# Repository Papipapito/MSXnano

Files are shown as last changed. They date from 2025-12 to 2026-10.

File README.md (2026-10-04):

# MSXnano — MSX2+ FPGA Core for Tang Nano 20K

**MSXnano** is an open-source MSX2+ FPGA implementation for the Tang Nano 20K (Gowin GW2AR-18). It runs a complete MSX2+ system — Z80 CPU, V9958 VDP with HDMI output, SCC/OPLL sound, SD card with Nextor, USB keyboard, joystick and mouse, and optional WiFi — entirely on the FPGA, with no original MSX hardware required.

> 📖 Project page, install guides and community: **[msx.barcelona](https://msx.barcelona)**

> **Project status: v2.1** ([`v2.1`](https://github.com/Papipapito/MSXnano/releases/tag/v2.1), 30/09/2026 — a **pre-release** until it is
> validated on the board; the last validated one is [`v2.0-final`](https://github.com/Papipapito/MSXnano/releases/tag/v2.0-final)).
> v2.1 brings a sorted SD browser and a faster CPU read path; the core still fills ~89 % of
> the GW2AR-18, so no larger features fit. Everything that
> works is documented; everything that was left out is listed, with the reasons, in
> [docs/tecnica/09-pendientes.md](docs/tecnica/09-pendientes.md). Larger features live on
> in [MSXimus](https://github.com/Papipapito/MSXimus) (Tang Console 60K).

## Features

* Z80 with authentic MSX timing (per-M1 wait state, ~100% of real MSX speed)
* V9958 VDP with HDMI output
* MSX2+ BIOS · 4 MB mapper · 2 MB Megaram SCC · RTC
* PSG · OPLL · SCC+ (×2) · stereo
* SD card with **Nextor 2.1.4**, boot menu and file browser
* **USB keyboard, joystick and MSX mouse** through an RP2040 companion
* **Turbo** — Panasonic WSX protocol at an exact 5.369318 MHz
* Optional **WiFi** (MSX UNAPI) via ESP-01S, or an **ESP32-C6** that adds a status screen

---

## What's new in v2.1

- **The SD browser is sorted**: folders first, then ROMs and disks together, alphabetical and
  case-insensitive. Hidden and system files stay out of the list (Windows' `System Volume
  Information`, the `.Trashes` and `._name.rom` a Mac leaves behind). A folder holds up to 112
  entries; if there are more, the counter ends in `+` (`112/112+`). On the gamepad, left and
  right (page jumps) now count once per press.
- **A faster CPU read path**: the read multiplexer is a tree instead of a 31-deep chain, with
  exactly the same priority (proven with a formal equivalence check). The CPU clock now closes
  on 6 placements out of 6, against 3 out of 6 before; this build runs at 62.5 MHz for the
  54 MHz it needs.
- **BIOS packs in English** as well as Spanish: four packs, English or Spanish menu, Nextor
  2.1.4 or 3.
- Settings shows **2.1** as the FPGA version. The RP2040 and ESP32-C6 firmwares do not change.

## What's new in v2.0

### 🎛️ One BIOS, and the menu is now an option

There used to be two BIOS builds — one that booted straight to MSX, one with the SD
browser — so you had to pick which one to flash. There is now **a single BIOS** and the
menu is a **setting**: press **S** at boot, tick *Menu al arrancar*, `Save & Restart`.
Untick it and you are back to booting straight into MSX. The choice is stored in flash.

### 📥 Downloads from the boot menu (File-Hunter)

With WiFi connected, press **F** in the browser to search and download ROMs and disk
images straight to the SD card, without a PC.

### 🕹️ RP2040 companion — better keyboards, and an MSX mouse

The onboard **BL616 is no longer used**. USB keyboard, joystick and mouse are now served
by an **RP2040 (Pico Zero)** over a single wire.

This removes the biggest compatibility headache of the previous versions: Tang Nano 20K
boards made since 2024 (marked **`3921`**) ship a BL616 in a secure-boot state that often
could not run the companion firmware, leaving you **without a keyboard** and needing an
external M0S Dock. **With the RP2040 that problem is gone** — every board behaves the same.

And it adds what the BL616 never did: a **real MSX mouse**, from any USB mouse.

### 🖥️ Optional companion screen

Alongside WiFi you can fit an **ESP32-C6 with a 240×240 LCD** that shows connection
status, the clock and whether Turbo is on — plus the classic MSX boot logo. The
**ESP-01S** is still supported if you only want WiFi.

---

## 🔌 Wiring

All three companions are **optional and independent**. The core boots and runs with none
of them (you just get no keyboard, so fit the RP2040 at least).

### FPGA ↔ RP2040 (keyboard, joystick, mouse)

| Pico Zero | Tang Nano 20K | Notes |
|---|---|---|
| **GP15** (TX) | **pin 31** | PIO-UART, 115200 8N1 |
| GND | GND | common ground |
| VBUS | 5V | powers the Pico |

Plug the USB keyboard, gamepad or mouse into the Pico's own USB port (a hub works).

Firmware: **`rp2040_keyboard_zero.uf2`** for the Waveshare **RP2040-Zero** (the default), or
**`rp2040_keyboard_pico.uf2`** for a plain Raspberry Pi Pico — both in the release. Source
and the same binaries are in [`fpga/rp2040/`](fpga/rp2040/) (there the Zero one is named
`rp2040_keyboard.uf2`).

### FPGA ↔ ESP-01S (WiFi only)

| ESP-01S | Tang Nano 20K |
|---|---|
| RX | **pin 27** |
| TX | **pin 28** |
| VCC | 3.3V |
| GND | GND |

### FPGA ↔ ESP32-C6 (WiFi + status screen)

The C6 replaces the ESP-01S on the same UART and adds one wire for the Turbo indicator.

| ESP32-C6 | Tang Nano 20K | Signal |
|---|---|---|
| **GPIO17** (RX) | **pin 27** | FPGA → C6 |
| **GPIO16** (TX) | **pin 28** | C6 → FPGA |
| **GPIO3** | **pin 29** | Turbo status |
| GND | GND | common ground |

Board: Waveshare **ESP32-C6-LCD-1.3**. Firmware: **[ESP32-for-FPGA](https://github.com/Papipapito/ESP32-for-FPGA)**.

---

## 💾 What to flash

Everything is attached to the **[v2.1 release](https://github.com/Papipapito/MSXnano/releases/tag/v2.1)** (the previous one, [`v2.0-final`](https://github.com/Papipapito/MSXnano/releases/tag/v2.0-final), stays available).

| Step | File | Address | Tool |
|---|---|---|---|
| 1 | `msxnano_v2.1.fs` | `0x000000` | [Gowin Programmer](https://www.gowinsemi.com/en/support/download_eda/) — External Flash mode |
| 2 | **One** pack: `pack_bios_msxnano.bin` (Spanish menu, Nextor 2.1.4, recommended), `pack_bios_msxnano_en.bin` (English menu), `pack_bios_msxnano_nextor3.bin` / `pack_bios_msxnano_en_nextor3.bin` (Nextor 3 beta) | `0x200000` | Gowin Programmer — *exFlash C Bin Erase, Program thru GAO-Bridge* |
| 3 | `rp2040_keyboard_zero.uf2` (RP2040-Zero) **or** `rp2040_keyboard_pico.uf2` (Pico) | — | Drag onto the Pico's `RPI-RP2` drive (hold BOOTSEL while plugging in) |
| 4 | `firmware_esp32c6_v2.0_merged.bin` | `0x0` | `esptool` — only if you fit the ESP32-C6 (the ESP-01S uses the ducasp UNAPI firmware) |

> The BIOS packs bundle the MSX2+ BIOS, sub-ROM, kanji, MSX-MUSIC, Nextor, the WiFi ROM,
> the boot menu and the config block. The system ROMs in them are copyrighted by their
> owners. Flashing a pack resets the saved Settings.

### The SD card

The best way to prepare the microSD is **[MSX SD Maker](https://github.com/Papipapito/SD_Maker)**, which has its own repository (a copy with
its guide is in [`MSXsdmaker/`](MSXsdmaker/README.md)): a Windows program that splits the card into 2 or 4 GB FAT16 partitions the way Nextor's FDISK does, copies Nextor 2.1.4 or 3
(to match your pack), SofaRun, Multi Mente and a set of utilities, and writes the `AUTOEXEC.BAT` that mounts the other
partitions as C:, D:… Nextor cannot read FAT32, so MSX-DOS needs FAT16.

---

## Keyboard

| MSX key | USB key |
|---|---|
| **GRAPH** | Left Alt, or either **Windows** key |
| **CODE / KANA** | Right Alt |
| **STOP** | F12, or Scroll Lock |
| **SELECT** | End |
| **CAPS** | Caps Lock |
| **F6–F10** | F6–F10 — sent as SHIFT+F1..F5, exactly as on a real MSX |
| F1–F5, arrows, HOME/INS/DEL, ESC/TAB/BS/RETURN | 1:1 |

**F11** toggles Turbo on the fly. It can also be set at power-on from **Settings**
(*Boot Turbo*) or by software through the Panasonic ports `$40/$41` (software wins if
both change it in the same cycle).

---

## Slot map

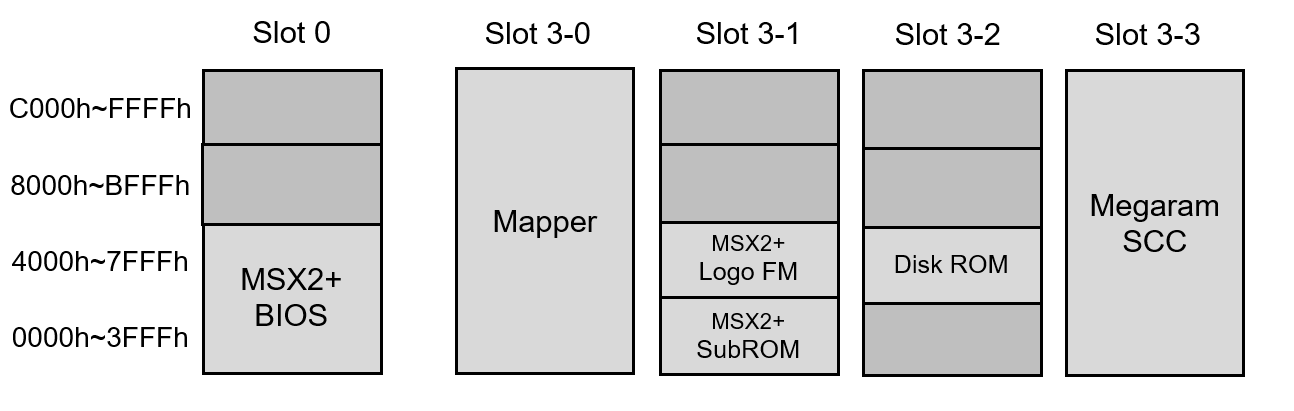
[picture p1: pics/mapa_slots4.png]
MSXnano MSX2+ slot map / memory layout for the Tang Nano 20K FPGA core


The layout is fixed by design: **Megaram in slot 2**, SD in **3-2**. SofaRun detects the
Megaram automatically; other software may need it set by hand.

---

## Hardware: case & bill of materials

* Parts list: [`docs/BOM.md`](docs/BOM.md) (spreadsheet: [`docs/MSXnano_BOM.xlsx`](docs/MSXnano_BOM.xlsx)).
* 3D-printable case: [`case/`](case/README.md) — a Bambu Studio project with every part,
  plus the STLs. Two top-left lids: one with a window for the ESP32-C6 screen, one plain.

> The 3D case is based on [this Thingiverse design](https://www.thingiverse.com/thing:4066021), which served as the inspiration and starting point for our improved version.

---

## 📚 Documentation

Full documentation (in Spanish) is in [`docs/INDICE.md`](docs/INDICE.md):

| | |
|---|---|
| [`docs/manual/`](docs/manual/01-que-es.md) | **User manual** — install, SD card, boot menu, ROMs and mappers, keyboard/mouse/joystick, WiFi and File-Hunter, audio/video/turbo, case, troubleshooting |
| [`docs/tecnica/`](docs/tecnica/01-arquitectura.md) | **Technical reference** — architecture, I/O ports, memory maps, the BIOS pack, the RP2040 protocol, synthesis and timing (why nothing more fits), simulation, changelog, open items |
| [`docs/historico/`](docs/historico/README.md) | Index of bug-hunt reports, design documents and retired code kept in the tree |

## Credits

This project is based on the work of **jabadiagm** ([MSXgoauldSD_tn20k](https://github.com/jabadiagm/MSXgoauldSD_tn20k)), licensed under **GPLv3**.

It is a standalone FPGA implementation that does not rely on the original physical MSX hardware, so all hardware-related files (PCB, MSX interface, schematics) have been removed.

**Claude (Anthropic)** collaborated on this project.

---

## Community & links

- 🌐 Project page & guides: [msx.barcelona](https://msx.barcelona)
- 🐙 Other MSX FPGA projects: [github.com/Papipapito](https://github.com/Papipapito)
- 🗣️ Barcelona MSX community: [AAMSX](https://www.aamsx.com)

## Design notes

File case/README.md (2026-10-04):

# Case (3D-printable enclosure)

3D-printable enclosure for the MSXnano (Tang Nano 20K based MSX2+).

## Quick print
Open **`msxnano_case_bambulab.3mf`** in **Bambu Studio** — it contains every part laid
out and ready to print all at once.

**Recommended material: white PETG.**

## Parts (STL)

| File | Part | Qty |
|---|---|-----|
| `Upper_Left_esp32.stl` | Top — left, **with a window for the ESP32-C6 LCD** | 1 (pick one) |
| `upper_left_sin_pantalla.stl` | Top — left, **plain** (ESP-01S or no WiFi module) | 1 (pick one) |
| `upper_right.stl` | Top — right | 1 |
| `lower_left.stl` | Bottom — left, **cut for the [MSXnano carrier v2](https://github.com/Papipapito/MSXnano-Boards/tree/main/carrier)**: USB-C, HDMI and 2 × USB-A out of the back wall, 4 standoffs for the board | 1 |
| `prototipo/lower_left_prototipo.stl` | Bottom — left, previous prototype (Tang + RP2040 wired by hand) | — |
| `lower_right.stl` | Bottom — right | 1 |
| `lower_side.stl` | Bottom side (TN20K case v4) | 1 |
| `keyboard_support_a.stl` | Keyboard support A | 1 |
| `keyboard_support_b.stl` | Keyboard support B | 1 |
| `raspberry_support.stl` | Board support (hand-wired RP2040 build; not needed with the carrier) | 1 |
| `pillar1.stl` | Pillar 1 | 2 |
| `pillar2.stl` | Pillar 2 | 2 |
| `msxnano_case_bambulab.3mf` | Bambu Lab project (all parts) | — |

### The two top-left lids

Only one of the two is printed. The left lid is where the WiFi module sits: choose
`Upper_Left_esp32.stl` if you fit the **Waveshare ESP32-C6-LCD-1.3** (its 240×240 screen
shows through the window), or `upper_left_sin_pantalla.stl` for an ESP-01S or no module.
Every other part is common to both builds.

### Bottom-left for the carrier board (2026-09)

`lower_left.stl` is the original Thingiverse part with the rear window closed and four new
openings for the carrier's rear edge (USB-C power, HDMI, keyboard USB-A, gamepad USB-A), plus
four standoffs printed into the floor on the Raspberry Pi 3 hole pattern (Ø 6 mm, 6.5 mm tall,
Ø 2.2 mm blind holes). The carrier sits on them 10.5 mm above the floor with its rear edge
against the back wall; fix it with 4 × M2.5 × 6–8 screws from the top (they cut their own
thread in the plastic; if you prefer heat-set inserts, open the holes to Ø 3.2 mm).
`raspberry_support.stl` is not needed with the carrier. The lid and the other parts are unchanged.

## Credits
Based on [Spectravideo SVI-728 Retropie case](https://www.thingiverse.com/thing:4066021)
by Palver (CC BY-NC), which served as the inspiration and starting point for this improved
version. The parts here are modified versions of that design.

## Assembly
See the bill of materials in [`../docs/MSXnano_BOM.xlsx`](../docs/MSXnano_BOM.xlsx) (or
[`../docs/BOM.md`](../docs/BOM.md)) and the wiring/flashing steps in the [main README](../README.md).
Step-by-step assembly, in Spanish: [`../docs/manual/09-carcasa.md`](../docs/manual/09-carcasa.md).

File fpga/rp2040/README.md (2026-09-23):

# RP2040 companion — USB keyboard, gamepad and mouse

The FPGA has no USB host. This RP2040 firmware is the MSXnano's USB host (TinyUSB): it reads
a USB keyboard, gamepads and a mouse and sends everything to the FPGA over **one wire**.
Derived from the MSXgoauld "Guardian Angel" firmware.

## Wiring (1 wire + power, RP2040 → FPGA)

| RP2040 | Tang Nano 20K | Notes |
|---|---|---|
| **GP15** | **pin 31** (`kbd_uart_rx_pin`) | PIO UART TX, 115200 8N1, idle-high. Data flows RP2040 → FPGA only |
| GND | GND | common ground |
| VBUS | 5V | the Tang powers the RP2040; the RP2040 powers the keyboard / hub |

- 3.3 V LVCMOS on both ends: direct connection, no level shifter.
- GP15 is driven by PIO because the hardware UARTs can't reach it on this board layout.
- Plug the keyboard, gamepad or mouse into the RP2040's own USB port. A self-powered hub
  lets you use all three at once.

## What it does

- **Keyboard** → MSX matrix (`inc/keymaps.h`): GRAPH on Left Alt and both Windows keys,
  CODE/KANA on Right Alt, STOP on F12 / Scroll Lock, SELECT on End, F6–F10 as SHIFT+F1..F5.
- **F11** → turbo toggle (command `0x04`).
- **Gamepads**: generic HID (DirectInput) and **XInput**. All pads go to MSX joystick
  port 1. Buttons 3 and 4 are **autofire** at 10 Hz.
- **Mouse** → a real MSX mouse on joystick port 2 (the protocol is emulated in the FPGA,
  `fpga/src/msx_mouse.v`). The RP2040-Zero LED turns cyan while a mouse is mounted.
- Full-matrix **resync every 250 ms**, so a lost byte never leaves a key stuck.

The wire protocol is frozen; the contract is the header of
[`fpga/src/kbd_uart_rx.v`](../src/kbd_uart_rx.v), explained in Spanish in
[`docs/tecnica/05-companion-rp2040.md`](../../docs/tecnica/05-companion-rp2040.md).

## Firmware files

| Board | In this directory | In the release |
|---|---|---|
| Waveshare RP2040-Zero (default, LED on GPIO16) | `rp2040_keyboard.uf2` | `rp2040_keyboard_zero.uf2` |
| Raspberry Pi Pico (LED on GPIO25) | `rp2040_keyboard_pico.uf2` | `rp2040_keyboard_pico.uf2` |

Same binaries, two names. To flash: hold **BOOTSEL** while plugging the board into a PC and
drag the `.uf2` onto the `RPI-RP2` drive.

## Build Instructions

Before build, make sure to:

* have `pico-sdk` with `tinyusb` library
* check `PICO_SDK_PATH` environment variable linked to `pico-sdk` directory
* have the **Arm bare-metal compiler**: `arm-none-eabi-gcc`
  (on Windows: `winget install --id Arm.GnuArmEmbeddedToolchain`)
* have a **native host C/C++ compiler too** — and this one catches people out.
  SDK 2.x builds `picotool` from source to turn the `.elf` into a `.uf2`, and
  picotool runs on your PC, not on the RP2040, so the Arm compiler alone is not
  enough. On Windows, running the build from a Visual Studio *vcvars64* shell is
  enough; on Linux, `build-essential`.

Both `.uf2` in this directory are built from this source. Rebuild BOTH when you change the
firmware.

```
mkdir build && cd build
cmake -G Ninja .. && ninja      # default = Waveshare RP2040-Zero; add -DRP2040_ZERO=0 for a Pico
```

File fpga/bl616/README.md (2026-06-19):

# Teclado USB (BL616 / FPGA-Companion) — IMPORTANTE

El teclado y los mandos USB del MSXnano los gestiona el **MCU BL616** mediante el
firmware **FPGA-Companion** (de [MiSTle-Dev](https://github.com/MiSTle-Dev/FPGA-Companion)),
que habla con la FPGA por SPI. Hay **dos formas** de tener ese BL616:

1. **El BL616 de a bordo** del propio Tang Nano 20K, o
2. **Un M0S Dock externo** (módulo BL616 aparte) conectado al header `m0s`.

El core conmuta **automáticamente** al M0S Dock externo cuando lo detecta
(pin `m0s[2]`), así que basta con enchufarlo.

---

## ⚠️ El problema de los Tang Nano 20K nuevos (2024+)

Desde **~febrero de 2024**, Sipeed fabrica los Tang Nano 20K (marca **`3921`** en la
placa) con el **eFuse de "secure-boot" del BL616 en un estado distinto**. En estas
placas, el BL616 de a bordo **a menudo NO puede ejecutar el firmware del companion**,
y el resultado es que **el teclado no funciona** (aunque la imagen por HDMI y el menú
sí funcionen — eso es la FPGA, no el BL616).

El propio autor del firmware lo advierte: en un BL616 en estado "unfused" *flashear el
firmware del µC lo puede dejar sin responder* (recuperable, ver abajo), y **es imposible
saber a priori si un `3921` es fused o unfused**. Su recomendación oficial para estas
placas es **usar un M0S Dock externo** (o PiPico) en lugar del BL616 de a bordo.

**Resumen:**

| Tu placa | BL616 de a bordo | Solución |
|---|---|---|
| Antigua (pre-2024) | Suele funcionar | Flashear el firmware onboard (abajo) |
| Nueva (`3921`, 2024+) | A menudo NO | **M0S Dock externo** |

---

## Test rápido: ¿mi Tang necesita el M0S Dock?

1. Flashea el **firmware onboard** (carpeta de abajo, `flash_nano20k.ini`).
2. Apaga y enciende la placa (power-cycle).
3. Conecta un teclado USB y prueba en el menú.
   - **Funciona** → tu BL616 de a bordo es compatible. Listo, no necesitas el dock.
   - **No funciona** → necesitas un **M0S Dock** (sección M0S Dock).

> Si tras flashear el onboard la placa deja de aparecer como puerto serie o no se deja
> reprogramar, **recupérala** con el firmware de fábrica `friend_20k`:
> https://github.com/harbaum/MiSTeryNano/blob/main/firmware/friend_20k

---

## Cómo flashear (Bouffalo Lab Dev Cube / Flash Cube)

Para cualquiera de las tres opciones:

1. Abre **BouffaloLabDevCube** (o BLFlashCube) → pestaña **MCU** / carga del `.ini`.
2. **Mantén pulsado BOOT/UPDATE** mientras conectas el USB-C, luego suelta.
3. Refresca el puerto COM, selecciónalo, baud **2000000**, y pulsa **Create & Download**.

### Opción A — BL616 de a bordo (estándar)
`flash_nano20k.ini`
- `bl616_fpga_partner_nano20k.bin` → `0x0`
- `fpga_companion_nano20k.bin` → `0x40000`

### Opción B — BL616 de a bordo (unconditional / bootloader firmado)
`flash_nano20k_unconditional.ini` (alternativa si la A no arranca el companion estando
el USB-C conectado a un PC para alimentar)
- `bl616_bootloader_0x20000_nano20k_signed.bin` → `0x0`
- `fpga_companion_bl616_tn20k.bin` → `0x20000`

### Opción C — M0S Dock externo (recomendado para placas nuevas)
`flash_m0sdock_cfg.ini`
- `fpga_companion_m0sdock.bin` → `0x0`

Flashea el M0S Dock (con su propio BOOT), cablea las 5 líneas SPI + alimentación
al Tang, y enchufa el teclado al USB-C del M0S Dock con un adaptador
**USB-C → USB-A (OTG)**. El core detecta el dock cuando CS (`m0s[2]`) baja y
conmuta del BL616 de a bordo al externo automáticamente (no hay que tocar RTL).

#### Cableado M0S Dock → Tang Nano 20K

Las señales SPI están definidas en el firmware (`mcu_hw.c`, build `M0S_DOCK`:
MISO=IO10, MOSI=IO11, CSN=IO12, SCK=IO13, IRQ=IO14) y en el RTL del MSXnano
(`fpga_companion.v` + `tang9k.cst`). Mapeo final:

| Señal | M0S Dock | Tang Nano 20K (pin GW2A) | `m0s[]` |
|---|---|---|---|
| MISO (FPGA→M0S) | IO10 | 42 | `m0s[0]` |
| MOSI (M0S→FPGA) | IO11 | 41 | `m0s[1]` |
| CS/SS (M0S→FPGA) | IO12 | 56 | `m0s[2]` |
| SCK (M0S→FPGA) | IO13 | 54 | `m0s[3]` |
| IRQ (FPGA→M0S) | IO14 | 51 | `m0s[4]` |
| 5V | 5V | 5V | alimentación |
| GND | GND | GND | común |

Notas:
- **IO10–IO14 están agrupadas** en el header CK-Link/debug del M0S Dock.
- El M0S Dock se **alimenta desde el Tang** (5V + GND), porque su USB-C lo ocupa
  el teclado.
- Las direcciones de señal cuadran 1:1: MISO/IRQ las conduce la FPGA, y
  MOSI/CS/SCK las conduce el M0S; `m0s[2]` lleva PULL-UP para que sin dock se use
  el BL616 de a bordo.

---

## Créditos / licencia

Los binarios `.bin` y `.ini` de esta carpeta son del proyecto
**FPGA-Companion** de MiSTle-Dev (versión **v1.4.21**), redistribuidos aquí por
comodidad bajo su licencia. Fuente y versiones más recientes:
https://github.com/MiSTle-Dev/FPGA-Companion/releases

Más contexto del cambio de hardware de Sipeed:
https://github.com/MiSTle-Dev/.github/wiki/Versions_TangNano20k

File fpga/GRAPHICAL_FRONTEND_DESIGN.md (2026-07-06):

# Frontend gráfico "no-MSX" para MSXnano — Documento de diseño

**Estado: FASE DE DISEÑO / investigación (2026-07-06).** Pregunta del usuario: sustituir el
menú MSX por un frontend gráfico bonito estilo EmuELEC/Batocera (con carátulas), NO limitado
al VDP MSX, que al elegir un juego lance el core MSX con el ROM/DSK. Investigado con panel
multi-agente (landscape multi-core, coste de construir el frontend, modelos de convivencia)
+ verificación en el repo. Ligado a [[msx_tang_nano_60k]].

## 1. Respuesta directa
SÍ es técnicamente posible, pero con una distinción crucial: NO es "instalar Batocera/EmuELEC". Es CONSTRUIR un frontend gráfico propio, estilo Game Bub (Eli Lipsitz), donde el MCU BL616 renderiza la UI bonita (carátulas, listas) y la envía a la FPGA, que la compone sobre el vídeo y la saca por el HDMI que ya generas. Al elegir un juego, el BL616 hace el handoff: carga el ROM/DSK en la megaram y reinicia el MSX (o reconfigura el bitstream). El frontend NO está limitado al VDP MSX porque no se dibuja con el VDP: lo dibuja el BL616 y lo pinta la lógica de vídeo de la FPGA (mismo camino HDMI, otra fuente de píxeles). Punto de partida REAL en tu repo: el canal SPI MCU↔FPGA ya existe y YA tiene un target OSD reservado (fpga/src/usb/mcu_spi_new.v:18-27: mcu_sys_strobe/mcu_hid_strobe/mcu_osd_strobe/mcu_sdc_strobe) y el BL616 ya es dueño de la SD (mcu_sdc_strobe + fpga/src/wondertang/sd_reader.sv). Es decir: el conducto de control y el acceso a las carátulas en SD ya están cableados; falta el renderizador gráfico (firmware) y un compositor de framebuffer (RTL). Esto va en el Console 60K, no en el TN20K.

## 2. Reality-check (por qué NO es "instalar Batocera")
Batocera, EmuELEC y MiSTer NO corren tal cual en un Tang, y la razón es de hardware, no de esfuerzo. Batocera/EmuELEC = Linux embebido + EmulationStation + RetroArch/libretro emulando por SOFTWARE sobre una CPU ARM (Rockchip/Amlogic); no reconfiguran ninguna FPGA. MiSTer sí reconfigura FPGA por juego, pero lo hace desde el ARM HPS del DE10-Nano (Cyclone V SoC: 2×Cortex-A9 @800MHz con Linux) que escribe el .rbf en la tela. Los tres dependen de un SoC con Linux para dibujar el menú gráfico. El Tang Nano 20K / Console 60K NO tiene SoC Linux: solo FPGA + el MCU BL616 (RISC-V, ~320-384MHz, ~480KB SRAM, SIN controlador HDMI propio — el vídeo SIEMPRE lo genera la FPGA). Por tanto EmulationStation es imposible aquí. Lo ÚNICO portable es el MODELO ABSTRACTO: un controlador renderiza el menú y hace handoff a la FPGA por juego. Además, el ecosistema de menús Tang que ya existe (FPGA-Companion, MiSTeryNano, TangCore, cores de nand2mario) hace ese handoff pero su OSD es SOLO TEXTO (buffer 32×28 caracteres enviado por UART/SPI), sin carátulas — no cumple tu deseo out-of-the-box. Un frontend gráfico con cover art en FPGA pelada NO existe reutilizable; hay que construirlo. Lo que SÍ es replicable y verificado: la arquitectura de Game Bub (MCU dibuja UI con Slint → framebuffer RGB15+alpha por QSPI ~20MB/s → la FPGA compone UI sobre vídeo del emulador y saca a pantalla → el MCU reconfigura el bitstream por consola). Es casi 1:1 con tu BL616+FPGA. Reutilizas: la ARQUITECTURA de referencia (no el código), tu canal SPI con target OSD ya existente, el acceso SD del BL616, y todo el camino HDMI (tn_vdp_v3_v9958/src/hdmi/*.sv + vdp_vga.vhd). Construyes: el renderizador de UI en el BL616 y un compositor/escalador en RTL. OJO de licencia: vdp_vga.vhd (Ohnaka) prohíbe uso comercial sin permiso escrito — condiciona qué se puede redistribuir.

## 3. Hook verificado en el repo (el punto de partida real)
El canal SPI BL616↔FPGA YA reserva un **target OSD**: `fpga/src/usb/mcu_spi_new.v:18-27` define
`mcu_{sys,hid,osd,sdc}_strobe`, direccionados por el primer byte de cada transacción
(`spi_target==2` → OSD, líneas 74-77). PERO está **stubbeado**: `fpga/src/usb/fpga_companion.v:85`
ata `.mcu_osd_din(8'b0)` y no hay ningún renderer que consuma `mcu_osd_strobe` (herencia de
MiSTeryNano/FPGA-Companion que este fork no activó porque usa el menú MSX). El BL616 además ya
es dueño de la SD (`mcu_sdc_strobe` + `fpga/src/wondertang/sd_reader.sv`). → El conducto de
control y el acceso a las carátulas en SD YA están cableados; falta el **renderer gráfico**
(firmware BL616) y un **compositor de framebuffer** (RTL).

Referencia de arquitectura probada y casi 1:1 con tu BL616+FPGA: **Game Bub** (Eli Lipsitz,
open-source): un MCU (ESP32-S3) renderiza la UI con Slint y envía el framebuffer RGB15+alpha
por QSPI (~20MB/s); la FPGA lo compone sobre el vídeo del emulador y saca a pantalla; el MCU
carga el bitstream por consola. Se copia la ARQUITECTURA, no el código.

## 4. Arquitecturas evaluadas
### A) Companion-OSD enriquecido del BL616 (carátulas simples sobre el OSD existente)
- **Convivencia**: companion-osd · **Esfuerzo**: medio · **¿Cabe en TN20K?**: Sí
- **Cómo**: Extender el target OSD que YA existe en el canal SPI (mcu_spi_new.v: mcu_osd_strobe) de texto a un overlay bitmap pequeño: el BL616 lee la carátula pre-escalada/pre-decodificada de la SD (ya es dueño de la SD vía mcu_sdc_strobe + sd_reader.sv), la manda por SPI y la FPGA la pinta en una ventana del OSD sobre el vídeo del menú/core. No es un framebuffer completo: es un overlay tipo MiSTer (tile/ventana) con una miniatura de carátula + texto bonito.
- **Carátulas**: Carátula pequeña pre-escalada (p.ej. 128x128 o 160x200) decodificada en el BL616 y enviada como bitmap a una ventana OSD; una imagen a la vez (la del juego seleccionado), no un grid 60fps. Actualización a ritmo de menú, no de frame.
- **Reutiliza / construye**: MUCHO: canal SPI + target OSD (mcu_spi_new.v:18-27), acceso SD del BL616 (sd_reader.sv), camino HDMI completo. Se construye: firmware de decodificación+envío en BL616 y ampliar el bloque OSD del RTL de texto a bitmap.
- **Pros**: El menor salto desde lo que ya tienes; reusa el conducto existente; probablemente cabe hasta en TN20K (overlay pequeño, no segundo sistema de vídeo). Handoff ya resuelto (el BL616 ya lanza juegos). Da el 'wow' de carátula sin reescribir el pipeline.
- **Contras**: No es un frontend 'Batocera' de pantalla completa: es un menú con una carátula, no un grid animado de portadas con scroll fluido. El menú de fondo sigue siendo el actual (MSX o un fondo simple), no una UI totalmente libre. Estético limitado por el tamaño del overlay.
### B) Blitter + framebuffer en DDR3 comandado por el BL616 (el 'Game Bub' propio)
- **Convivencia**: companion-osd · **Esfuerzo**: alto · **¿Cabe en TN20K?**: No (Console 60K)
- **Cómo**: En el Console 60K, un framebuffer completo en DDR3 (512MB da de sobra) que posee la FPGA; el BL616 renderiza la UI (Slint/LVGL) y envía SOLO tiles/regiones sucias por SPI/QSPI (partial rendering, como Game Bub), o comanda un pequeño blitter en RTL (copia rects, escala, alpha-blend carátulas). Un compositor lee el framebuffer y lo saca por el HDMI existente; en modo juego, compone la UI (semitransparente/overlay) sobre el vídeo del core o la sustituye. Al elegir juego: handoff a megaram + reset del MSX.
- **Carátulas**: Grid completo de carátulas con scroll: el BL616 decodifica JPG/PNG pre-escalados de la SD y los blitea al framebuffer DDR3; el blitter RTL hace el escalado/alpha. Esto SÍ es un frontend bonito de pantalla completa tipo EmulationStation.
- **Reutiliza / construye**: MEDIO: reusa el canal SPI (ampliándolo a QSPI para ancho de banda), acceso SD, camino HDMI (hdmi/*.sv), y el controlador DDR3 del port 60K. Se construye: compositor+blitter RTL (net-new), firmware UI del BL616 (net-new), protocolo de framebuffer.
- **Pros**: Es EXACTAMENTE lo que el usuario pide y hay referencia probada (Game Bub open-source, arquitectura casi idéntica: MCU+FPGA, framebuffer del lado FPGA, partial render del MCU). Aprovecha la DDR3 del 60K (el TN20K no la tiene). Frontend totalmente libre del VDP MSX, animaciones, transiciones. Escala a otros cores del futuro.
- **Contras**: Net-new RTL (blitter/compositor/escalador) + net-new firmware BL616 con GUI framework — el mayor bloque de trabajo original. 480KB SRAM del BL616 obliga a partial rendering + framebuffer del lado FPGA (no cabe frame completo en el MCU). NO cabe en TN20K (89% CLS). Requiere el port 60K terminado primero.
### C) Soft-SoC (LiteX/VexRiscv) que dibuja el frontend dentro de la FPGA
- **Convivencia**: hibrido · **Esfuerzo**: muy alto · **¿Cabe en TN20K?**: No (Console 60K)
- **Cómo**: Instanciar un soft-CPU RISC-V (LiteX + VexRiscv) DENTRO de la FPGA con su propio framebuffer en DDR3 y un core de vídeo; ese SoC corre el frontend (C/Rust o incluso un Linux mínimo en LiteX) y, al elegir juego, reconfigura/entrega el control al core MSX. En vez de usar el BL616 externo, el 'cerebro gráfico' es lógica de la propia FPGA.
- **Carátulas**: Framebuffer propio del soft-SoC en DDR3 con librería gráfica corriendo en el VexRiscv; carátulas decodificadas por el soft-CPU. Potencia equivalente a B pero todo dentro de la FPGA.
- **Reutiliza / construye**: BAJO en lo específico del proyecto: reusa el camino HDMI y DDR3, pero introduce un stack nuevo (LiteX) que hay que integrar con tu core MSX y tu toolchain Gowin. El BL616 quedaría solo para USB/teclado.
- **Pros**: Frontend muy potente e independiente del BL616 (no dependes de la SRAM/CPU del MCU); un soft-CPU con Linux/LiteX puede montar SD, decodificar imágenes, red, etc. Ecosistema LiteX maduro para Xilinx/Lattice.
- **Contras**: Coste de lógica ALTO (soft-CPU + MMU + framebuffer + periféricos compiten con el core MSX por LUTs del GW5AT-60); soporte LiteX en Gowin GW5A es inmaduro/no oficial (riesgo real de toolchain). Duplica un 'cerebro' que ya tienes en el BL616 — desperdicia el MCU. Peor relación esfuerzo/beneficio que B para el mismo resultado visual. Solo tiene sentido si se descarta usar el BL616 como renderizador.
### D) Reconfiguración total estilo MiSTer (bitstream 'monitor' separado + bitstreams por core)
- **Convivencia**: reconfig-total · **Esfuerzo**: alto · **¿Cabe en TN20K?**: Sí
- **Cómo**: Un bitstream 'menú/monitor' independiente (que puede incluir el frontend gráfico de B o C) corre solo; al elegir juego, el BL616 hace streaming del bitstream del core MSX (o de otro core) a la FPGA y arranca. No conviven dos sistemas de vídeo a la vez: se SUSTITUYEN por reconfiguración (nand2mario mide ~2s optimizado). Complementa B: define CÓMO se separa el frontend del core en el tiempo.
- **Carátulas**: La del bitstream de menú (por tanto, tan bonita como B o C, ya que el menú es su propio bitstream con framebuffer dedicado y sin compartir lógica con el core MSX).
- **Reutiliza / construye**: Reusa el mecanismo de carga de bitstream del BL616 (ya carga/gestiona la FPGA para teclado; TangCore/nand2mario demuestran /cores en SD). Se construye: el flujo de multi-bitstream, y el bitstream de menú (que es B o C).
- **Pros**: El frontend NO compite por lógica con el core MSX (viven en bitstreams distintos) — resuelve el 89% CLS del TN20K para la parte de menú. Modelo probado en Tang (TangCore, nand2mario ~2s de reconfig). Escala a multi-core (NES/SNES/MSX...). Casa con tu restricción conocida: la SDRAM/megaram es volátil y se pierde en cualquier reconfiguración de todos modos.
- **Contras**: El handoff pierde el estado (reconfig = reset total; coherente con tu megaram volátil, pero el retorno menú→juego→menú recarga flash cada vez). Complejidad de gestionar N bitstreams y el arranque. Sigues necesitando construir el bitstream de menú bonito (B o C) — D es el 'cómo se orquesta', no ahorra el trabajo del frontend gráfico. ~2s de conmutación visible.

## 5. Recomendación
Ruta escalonada, target Tang Console 60K (GW5AT-60) para todo lo gráfico nuevo — el TN20K al 89% CLS solo aguanta la Fase 1. FASE 1 (ya, bajo riesgo, incluso en TN20K): Arquitectura A. Ampliar el target OSD que YA existe en mcu_spi_new.v de texto a un overlay bitmap y que el BL616 lea una carátula pre-escalada de la SD (ya es dueño de la SD). Consigues 'menú con carátula' reutilizando el 90% del conducto existente, sin tocar el pipeline de vídeo ni depender del port 60K. Es la validación barata de que el modelo MCU-dibuja / FPGA-compone funciona en tu hardware. FASE 2 (cuando llegue y esté portado el Console 60K): Arquitectura B, el 'Game Bub propio'. Framebuffer completo en DDR3 propiedad de la FPGA + compositor/blitter RTL + firmware UI en el BL616 (Slint o LVGL, partial rendering porque los 480KB de SRAM no dan para frame completo, carátulas JPG/PNG pre-escaladas en SD). Copia la arquitectura de Game Bub (open-source, casi 1:1 con tu BL616+FPGA), NO su código. Esto es el frontend bonito de pantalla completa tipo Batocera que quieres. FASE 3 (organizativa, si vas a multi-core): envolver B en el modelo D (bitstream de menú separado + streaming de bitstream por core), que además esquiva el problema de compartir lógica con el core MSX y encaja con tu megaram volátil (la reconfig resetea de todos modos). DESCARTAR C (soft-SoC LiteX) salvo que decidas no usar el BL616 como renderizador: para el mismo resultado visual cuesta mucho más lógica y el soporte LiteX en Gowin GW5A es inmaduro; además duplica un cerebro que ya tienes. Regla de honestidad para comunicar al usuario: no prometas 'correr Batocera'; promete 'un frontend gráfico companion estilo Game Bub, con carátulas, construido para MSXnano, en el Console 60K'.

## 6. Preguntas abiertas
- Ancho de banda del enlace BL616→FPGA: el canal actual es SPI byte a byte (mcu_spi_new.v). ¿A qué reloj corre hoy y hay pines libres para pasar a QSPI 4-bit como Game Bub (~20MB/s) en el Console 60K? Un grid de carátulas necesita más que el UART/SPI de texto actual.
- ¿El controlador DDR3 del port 60K expondrá un puerto de escritura/lectura libre para un framebuffer del frontend, o toda la DDR3 estará ocupada por el core MSX (VRAM/megaram)? Determina si B es viable sin robar ancho de banda al MSX.
- Presupuesto de SRAM del BL616 (480KB) con USB-host de teclado YA activo + GUI framework + decodificador JPG/PNG + buffers de tiles sucios: ¿cabe Slint/LVGL a la vez que el firmware de teclado actual, o hace falta un segundo MCU / mover el teclado?
- Handoff y estado: con megaram volátil, el ciclo menú→juego→menú recarga flash y resetea. ¿Se acepta el ~2s (modelo D) y la pérdida de estado, o se quiere 'suspend/resume' del juego (que exigiría snapshot de SDRAM a SD, mucho más trabajo)?
- Licencia: vdp_vga.vhd (Ohnaka) prohíbe uso comercial sin permiso escrito, y el firmware PicoVerse es CC-BY-NC. Si el MSXnano se vende, ¿qué piezas del camino de vídeo/frontend son redistribuibles comercialmente y cuáles hay que reimplementar clean-room?
- ¿El frontend debe soportar solo MSX o es la semilla de un multi-core (SG-1000/Coleco ya existen en v1.8)? Si es multi-core, el modelo D (bitstream de menú separado) gana peso desde el principio y cambia el diseño de la Fase 2.
- Origen de las carátulas: ¿se generan/empaquetan offline en el Pack Builder (PySide6) pre-escaladas al tamaño exacto del overlay/grid, o el BL616 escala en runtime? Pre-escalar en el Pack Builder descarga muchísimo al MCU.

## 7. Ficheros clave del repo
- `fpga/src/usb/mcu_spi_new.v` (canal SPI BL616, target OSD reservado), `fpga/src/usb/fpga_companion.v` (OSD stubbeado, din=0).
- `fpga/src/wondertang/sd_reader.sv` (SD, ya del BL616).
- `fpga/tn_vdp_v3_v9958/src/hdmi/*.sv` + `vdp_vga.vhd` (camino HDMI; ⚠️ vdp_vga.vhd de Ohnaka = NO comercial sin permiso).
- Menú MSX actual: `fpga/src/msxnano_menu/` (se sustituiría/coexistiría).

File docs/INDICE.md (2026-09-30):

# Documentación del MSXnano

Índice general. El [README](../README.md) del repositorio (en inglés) se queda corto a
propósito: qué es, qué hace falta y cómo se instala. Todo lo demás vive aquí.

Estado del proyecto: **v2.1** (release [`v2.1`](https://github.com/Papipapito/MSXnano/releases/tag/v2.1), 30/09/2026, pre-release hasta validarla en placa; la última validada es [`v2.0-final`](https://github.com/Papipapito/MSXnano/releases/tag/v2.0-final), 23/09/2026). La v2.1 trae el navegador ordenado y el mux de lectura de la CPU en árbol ([changelog](tecnica/08-changelog.md)). El core ocupa el ~89 % de la lógica del chip y no
queda sitio para funcionalidades nuevas. Lo que hay funciona y está validado en placa; lo
que se quedó fuera está documentado en [pendientes y aparcado](tecnica/09-pendientes.md)
para quien quiera retomarlo.

## Cómo está organizada

| Carpeta | Para quién | Qué contiene |
|---|---|---|
| `docs/manual/` | Quien tiene la placa y quiere usarla | Instalación, tarjeta SD, menú, ROMs, teclado y ratón, WiFi, audio y vídeo, carcasa, problemas |
| `docs/tecnica/` | Quien quiere entender o modificar el core | Arquitectura, puertos de E/S, mapas de memoria, pack de BIOS, protocolo del companion, síntesis y timing, simulación, changelog, pendientes |
| `docs/historico/` | Nadie en particular | Índice de los documentos de diseño y las cazas de bugs que se conservan por si explican una decisión, pero que ya no describen el estado actual |

Idioma: castellano. El README y el `case/README.md` están en inglés porque son la puerta
de entrada pública.

## Manual de usuario (`docs/manual/`)

| Nº | Capítulo | De dónde sale |
|---|---|---|
| 01 | [Qué es el MSXnano](manual/01-que-es.md): la máquina, lo que trae, lo que hace falta, lo que no es | README, top.v |
| 02 | [Instalación](manual/02-instalacion.md): flashear el core y el pack, el RP2040, el ESP-01S o el ESP32-C6, cableado, actualizar | README, firmwares |
| 03 | [La tarjeta SD](manual/03-tarjeta-sd.md): formato, qué poner, Nextor | menú, Nextor |
| 04 | [El menú de arranque](manual/04-menu.md): Ajustes, navegador, lanzar ROM y disco, Boot Turbo, File-Hunter | bios-msxnano-msximus |
| 05 | [ROMs y mappers](manual/05-roms-mappers.md): la megaram, los mappers, cómo se decide, el forzado manual | megaram.v, menú |
| 06 | [Teclado, ratón y joystick](manual/06-teclado-raton-joystick.md): el companion RP2040, el mapa de teclas, F11, el ratón MSX, autofire, hubs | rp2040/, kbd_uart_rx.v, msx_mouse.v |
| 07 | [WiFi y File-Hunter](manual/07-wifi-file-hunter.md): ESP-01S o ESP32-C6, la tecla W, la tecla F, la pantalla del C6 | README, ESP32-for-FPGA |
| 08 | [Audio, vídeo y turbo](manual/08-audio-video-turbo.md): los chips, estéreo por HDMI, scanlines, el turbo Panasonic y cómo activarlo | top.v, tn_vdp |
| 09 | [La carcasa](manual/09-carcasa.md): piezas, las dos tapas, impresión, montaje, lista de materiales | case/, docs/BOM.md |
| 10 | [Problemas frecuentes](manual/10-problemas.md): por síntoma, con causa probable y qué hacer | todo lo anterior |

## Referencia técnica (`docs/tecnica/`)

| Nº | Capítulo | De dónde sale |
|---|---|---|
| 01 | [Arquitectura](tecnica/01-arquitectura.md): relojes, módulos, mapa de ficheros, defines de compilación | top.v, build.tcl |
| 02 | [Puertos de E/S](tecnica/02-puertos-es.md): todos los puertos que decodifica el core, propios y estándar | top.v, submódulos |
| 03 | [Mapas de memoria](tecnica/03-mapas-memoria.md): slots, SDRAM, flash | top.v, README |
| 04 | [El pack de BIOS](tecnica/04-pack-bios.md): anatomía byte a byte, cómo se monta, qué es propietario | bios-msxnano-msximus |
| 05 | [El companion RP2040](tecnica/05-companion-rp2040.md): el protocolo UART congelado, teclado, joystick, ratón, latencia | kbd_uart_rx.v, msx_mouse.v, usbin.c |
| 06 | [Síntesis y timing](tecnica/06-sintesis-timing.md): Gowin, ocupación, relojes críticos, campañas, **por qué no cabe más** | build.tcl, commits |
| 07 | [Simulación](tecnica/07-simulacion.md): Icarus en WSL, los testbenches que hay | tools/ |
| 08 | [Changelog](tecnica/08-changelog.md): de la v1.0 a la v2.0 | tags, releases |
| 09 | [Pendientes y aparcado](tecnica/09-pendientes.md): lo que se sabe y no se hizo, con su porqué | auditorías, sesiones |

## Histórico (`docs/historico/`)

[Índice](historico/README.md) de los documentos que se conservan tal cual: la auditoría
previa al porte al 60K, el diseño del frontend gráfico, la caza del bug de Metal Gear 2 y
el expediente de la doble interrupción de línea.

## Otros repositorios del proyecto

| Repositorio | Qué es |
|---|---|
| `bios-msxnano-msximus` (**privado**) | El menú de arranque y las herramientas que montan el pack de BIOS. Fuente único para las dos máquinas; los packs ya montados van en la release |
| [ESP32-for-FPGA](https://github.com/Papipapito/ESP32-for-FPGA) | Firmware del ESP32-C6 (WiFi UNAPI + pantalla) |
| [MSXimus](https://github.com/Papipapito/MSXimus) | El hermano mayor, en la Tang Console 60K |
| [msx-turbo](https://github.com/Papipapito/msx-turbo) | `TURBO.COM`: activar y desactivar el turbo desde MSX-DOS |

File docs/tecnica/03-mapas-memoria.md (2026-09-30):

# 03. Mapas de memoria

Tres mapas distintos que conviene no mezclar: lo que ve el **Z80** (slots), dónde vive
cada cosa en la **SDRAM** de 8 MB, y qué hay en la **flash SPI** de la placa.

## Lo que ve el Z80: slots

Los slots 0 y 3 están expandidos; el 1 no existe (a menos que la config lo habilite:
*Slot 1* en Ajustes) y el 2 es la Megaram.

| Slot | Página 0 (0000) | Página 1 (4000) | Página 2 (8000) | Página 3 (C000) |
|---|---|---|---|---|
| **0-0** | BIOS MSX2+ | BIOS | — | — |
| **0-1** | — | Driver kanji | Driver kanji | — |
| **0-2** | — | ROM WiFi (UNAPI ESP) | — | — |
| **0-3** | — | Logo (16 KB) | — | — |
| **1** | — | — | — | — |
| **2** | Megaram | Megaram | Megaram | Megaram |
| **3-0** | Mapper 4 MB | Mapper | Mapper | Mapper |
| **3-1** | Sub-ROM | MSX-MUSIC + **menú** | — | — |
| **3-2** | — | Nextor | Nextor | — |
| **3-3** | — | — | — | — |

Notas:

- La **BIOS** es la del MSXgoauld con el parche `int_fix` (ver [04](04-pack-bios.md)).
- **Nextor 2.1.4** en el 3-2 es lo que ven `NEXTOR.SYS` y las utilidades; es el slot que
  hay que dar a `DRVTEST` y compañía.
- El **mapper** es de 4 MB = 256 segmentos de 16 KB. Nextor lo detecta como "4096 KB".
- La **Megaram** de 2 MB responde en las cuatro páginas; el mapper que tenga activo decide
  qué ventanas se ven (ver [02](02-puertos-es.md), memoria mapeada).
- El **menú** va pegado a la ROM de MSX-MUSIC en el 3-1 (16 KB entre los dos) y el
  **logo** de arranque en el 0-3. Ninguno se ve una vez en el DOS: el menú hace su
  trabajo y se retira.
- Con *Slot 1* activado en Ajustes, el mapper aparece además en el slot 1 (`mapper_req12`
  en `top.v`): sirve para software antiguo que solo busca RAM en los slots 1-2.

## La SDRAM de 8 MB

Es un chip de 64 Mbit sobre la placa, con bus de datos de 16 bits. El core lo trata como
8 MB de bytes (`ram_addr[22:0]`) y lo reparte así (el comentario de `top.v` línea ~1540
es la fuente):

| Rango | Tamaño | Qué | Banco |
|---|---|---|---|
| `0x000000 – 0x3FFFFF` | 4 MB | **Mapper de RAM** | A + B |
| `0x400000 – 0x5FFFFF` | 2 MB | **Megaram** | C |
| `0x600000 – 0x6FFFFF` | 1 MB | libre | — |
| `0x700000 – 0x73FFFF` | 256 KB | Kanji JIS1 + JIS2 | D |
| `0x740000 – 0x75FFFF` | 128 KB | Nextor (disco WonderTANG) | D |
| `0x760000 – 0x767FFF` | 32 KB | BIOS MSX2+ | D |
| `0x768000 – 0x76BFFF` | 16 KB | Sub-ROM | D |
| `0x76C000 – 0x76FFFF` | 16 KB | MSX-MUSIC + menú | D |
| `0x770000 – 0x777FFF` | 32 KB | Driver kanji | D |
| `0x778000 – 0x77BFFF` | 16 KB | ROM WiFi (esp8266e) | D |
| `0x77C000 – 0x77FFFF` | 16 KB | Logo | D |
| `0x7C0000 – 0x7FFFFF` | 256 KB | **VRAM** del V9958 (128 KB útiles, ampliable) | D |

Tres cosas que se deducen del mapa:

1. **El pack se copia entero a `0x700000`**: el cargador de flash escribe desde
   `RAM_START_ADDRESS + 1` en adelante, y por eso el offset de cada ROM en el pack es
   exactamente su dirección menos `0x700000`. Si se mueve algo en el pack hay que mover
   también el `ram_addr` correspondiente en `top.v`.
2. **La VRAM comparte chip con todo**: de ahí el árbitro CPU/VDP en `memory.v` y por qué
   el VDP tiene prioridad (un píxel perdido se ve; un ciclo del Z80 retrasado no).
3. **Queda 1 MB libre** (`0x600000-0x6FFFFF`). No es sitio para lógica, es sitio para
   datos: por ejemplo, una SRAM de cartucho persistente ([09](09-pendientes.md)).

Los "bancos" A-D son los cuatro bancos internos de la SDRAM. El reparto no es casual:
el controlador puede tener una fila abierta por banco, así que la RAM del mapper (A+B),
la Megaram (C) y las ROMs + VRAM (D) no se pisan las filas entre sí.

## La flash SPI de la placa

Es la flash de configuración de la Tang Nano 20K (la misma que carga el bitstream), de
8 MB, y el core la lee por SPI en el arranque:

| Dirección | Tamaño | Qué | Cómo se graba |
|---|---|---|---|
| `0x000000` | ~1 MB | **Bitstream** (`msxnano_v2.1.fs` en la release, `bin/msxnano.fs` en el repo) | Gowin Programmer, *External Flash Mode* |
| `0x200000` | 512 KB + 6 | **Pack de BIOS** + firma + config | Gowin Programmer, *exFlash C Bin Erase, Program thru GAO-Bridge*, dirección `0x200000` |
| `0x280000` | 6 bytes | Firma `AB` + `config1` + `config2` + turbo de arranque + `FF` | Lo escribe el core al hacer *Save & Restart* |

El cargador (`flash_rw.v` + la máquina de estados de `top.v`, `FLASH_START_ADDRESS`)
lee `GOAULD_ROM_SIZE = 512·1024 + 6` bytes seguidos. Los 6 últimos son la configuración
persistente: la firma `41 42` ("AB") dice que el bloque es válido; si no está, se cargan
los valores por defecto (`CONFIG1_DEFAULT`, `CONFIG2_DEFAULT`).

Esto tiene una consecuencia práctica: **regrabar el pack borra los ajustes** (el
Programmer borra el sector entero). No es un fallo, es que la config vive pegada al pack.

## Ejemplo: seguir una lectura de la BIOS

`LD A,(0000h)` con el slot 0-0 en la página 0:

1. El Z80 saca `bus_addr = 0x0000`, `MREQ`, `RD`.
2. `top.v` resuelve slot primario 0 (PPI A8) y secundario 0 (`0xFFFF` del slot 0) →
   `bios_req = 1`.
3. `ram_addr = {8'b11101100, bus_addr[14:0]}` = `0x760000`.
4. `memory.v` pide el byte a la SDRAM en el hueco que le deja el VDP; el Z80 espera con
   `wait_n` si hace falta.
5. El byte vuelve por el mux de `cpu_din`.

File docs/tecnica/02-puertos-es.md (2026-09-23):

# 02. Puertos de E/S

Todos los puertos que responde el core, agrupados. Los estándar del MSX se comportan como
en la máquina real; los **propios** del MSXnano están marcados y son los que interesan a
quien escriba software para él.

## Propios del MSXnano

| Puerto | R/W | Qué es |
|---|---|---|
| **0x2F** | R | **Versión del core** (`FPGA_VERSION` en `top.v`). Formato `0x1X` = 1.X, `0x20` = 2.0. El menú lo **muestra** en Ajustes; desde la v2.0 no lo compara con nada (el guardián de versión de la v1.9 se quitó). Sin guarda: se lee siempre |
| **0x2B** | R | Diagnóstico del **ratón**: estado del handshake (fase, pin 8, últimos nibbles). Solo para depurar `msx_mouse.v`; portado del 0x2E del MSXimus |
| **0x40** | W | **E/S conmutada** (OCM): selecciona el dispositivo. `OUT &H40,8` = turbo Panasonic; `OUT &H40,&H48` (72) = configuración goauld |
| **0x40** | R | Devuelve el complemento del dispositivo seleccionado si existe (`&HF7` tras seleccionar el 8) |
| **0x41** | R/W | Con el dispositivo 8: **turbo Panasonic**. Bit 0 = 0 turbo 5,37 MHz, 1 = 3,58. `OUT &H41,128` activa, `OUT &H41,129` desactiva; `INP(&H41)` lee el estado. Con el dispositivo 0x48: **config1** (mapper, Megaram, segundo SCC, scanlines; mapa de bits en [04](04-pack-bios.md)) |
| **0x42** | R/W | Con el dispositivo 0x48: **config2** en los bits 5:0 (SD, slot de Nextor, menú al arrancar, 8 sprites/línea, estéreo); **bit 6 = guardar en la flash**, **bit 7 = reiniciar**. Escribir en 0x41 o en 0x42 aplica los dos registros a la vez: el menú escribe siempre 0x41 y luego 0x42 |
| **0x43** | R/W | Con el dispositivo 0x48: `sram_cfg` de la Megaram (qué segmentos son SRAM). Volátil |
| **0x45** | R/W | Con el dispositivo 0x48: **Boot Turbo** (bit 0); se guarda en la flash con el resto |
| **0x10 / 0x11 / 0x12** | W/W/R | **Segundo PSG** (YM2149): registro, escritura y lectura, como los 0xA0-0xA2. En estéreo va al canal derecho |
| **0x06 / 0x07** | R/W | **UART del ESP** (WiFi): 0x07 = TX / estado (bit 0 = hay dato), 0x06 = RX / velocidad (`OUT (6),20` vacía el FIFO). Los usa la ROM UNAPI; velocidad fija 859372 |

### El protocolo del turbo, paso a paso

Es exactamente el del Panasonic FS-A1WSX, para que el software que lo conoce lo detecte:

```basic
OUT &H40,8            ' seleccionar el dispositivo "turbo"
IF INP(&H40)=&HF7 THEN PRINT "hay turbo"
OUT &H41,128          ' activar (bit0 = 0)
OUT &H41,129          ' desactivar (bit0 = 1)
PRINT INP(&H41) AND 1 ' 0 = en turbo
```

Si el puerto y la tecla F11 cambian el turbo en el mismo ciclo, gana el puerto (en el
chip T9769 real el puerto es el único control).

## Estándar del MSX (comportan como la máquina real)

| Puerto | Chip | Notas |
|---|---|---|
| **0x98 – 0x9B** | V9958 | VRAM, registros, paleta, indirecto. Con las esperas del VDP real |
| **0xA0 – 0xA2** | PSG | Registro, escritura, lectura. El puerto A (R#14) lleva el joystick/ratón; el bit 7 es la entrada de casete (siempre a 1, no hay casete) |
| **0xA8 – 0xAB** | PPI 8255 | Slots primarios (A8), teclado (A9 columna, AA fila), y **AB con el modo bit-set/reset** (motor, click, CAPS). Los cuatro se decodifican; el AA se puede releer (hubo un bug histórico aquí) |
| **0x7C / 0x7D** | OPLL | MSX-MUSIC |
| **0xB4 / 0xB5** | RTC | RP-5C01 |
| **0xD8 – 0xDB** | Kanji | JIS1 y JIS2 |
| **0xFC – 0xFF** | Mapper de RAM | 4 MB = 256 segmentos; los registros **no son legibles** (devuelven 0xFF) — es uno de los hallazgos aparcados |
| **0xF2** | — | Latch de 8 bits de lectura/escritura (heredado del OCM) |

## Memoria mapeada (no son puertos, pero se buscan aquí)

| Rango | Qué | Cómo |
|---|---|---|
| `0x5000/0x7000/0x9000/0xB000` en slot 2 | Bancos de la Megaram en modo Konami SCC | Escritura del número de banco |
| `0x9800 – 0x98FF` en slot 2 | **SCC** de la Megaram (con el banco 0x3F en 0x9000) | Registros de onda, frecuencia, volumen |
| `0x6000/0x8000/0xA000` | Konami4 | Idem |
| `0x6000/0x6800/0x7000/0x7800` | ASCII8 | Idem |
| `0x6000/0x7000` | ASCII16 | Idem |
| `0x7FFE / 0xBFFE` | SCC+: registro de modo | Solo el bit 5 (modo SCC+) está implementado; los de deformación no |
| `0xFFFF` | Registro de slot expandido | En los slots 0 y 3, que están expandidos |

## Lo que NO hay

Sin puerto de casete (el bit 7 del PSG está fijo a 1), sin impresora (0x90/0x91), sin
puerto de la MSX-AUDIO (0xC0-0xC3), sin OPL4 (0x7E/0x7F, 0xC4-0xC7), sin puertos del
turbo R (0xA7, 0xE4-0xE7). El software que los sondea recibe 0xFF y sigue.

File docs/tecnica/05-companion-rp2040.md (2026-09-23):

# 05. El companion RP2040 (teclado, mando, ratón)

La FPGA no tiene host USB. Un **RP2040** (Waveshare RP2040-Zero o una Pico normal) hace
de host con TinyUSB, traduce teclado, mando y ratón a un protocolo de un solo cable y se
lo cuenta a la FPGA por una **UART a 115200 8N1** (GP15 → pin 31 de la Tang). La FPGA
mantiene una **matriz de teclado virtual** que el MSX lee por el PPI como si fuera un
teclado de verdad.

Fuentes: `fpga/rp2040/` (firmware, `FW_VERSION = 0x13`) y `fpga/src/kbd_uart_rx.v`
(receptor). **La cabecera de `kbd_uart_rx.v` es el contrato**; si alguien cambia el
protocolo tiene que cambiar los dos lados a la vez.

## Cableado

| Pico | Tang Nano 20K | Notas |
|---|---|---|
| GP15 | **pin 31** | UART TX (PIO) → RX de la FPGA. `PULL_MODE=UP`: sin Pico la línea reposa alta = nada pulsado |
| GND | GND | Masa común, obligatoria |
| VBUS (5 V) | 5 V | La Pico se alimenta de la Tang; el teclado y el hub, de la Pico |

Un solo sentido (la FPGA nunca habla con la Pico). Los pines 27/28/29 del mismo header
son de la WiFi y el turbo ([BOM](../BOM.md)).

## El protocolo (congelado)

Bytes por la UART, LSB primero. Los opcodes con el bit 7 a 1 llevan operandos; los que
lo tienen a 0 son órdenes de un byte.

| Secuencia | Significado |
|---|---|
| `0x90 <celda>` | **MAKE**: tecla pulsada. `celda = 0x80 \| (bit << 4) \| fila`, fila 0-10, bit 0-7 |
| `0xA0 <celda>` | **BREAK**: tecla soltada |
| `0xFE m0 … m10 0xFF` | **Resync** de la matriz completa (11 filas, activas a nivel bajo). Cada 250 ms |
| `0xC0 <versión>` | Anuncio de versión del firmware (con cada resync). La FPGA lo **consume y lo descarta** (el guardián de versión se quitó en la v2.0); hay que seguir leyéndolo o el byte de versión se tomaría por una orden |
| `0xB0 <puerto> <byte>` | **Joystick**: `puerto` 0 = puerto 1 del MSX, 1 = puerto 2. `byte` activo alto: bit0 derecha, bit1 izquierda, bit2 abajo, bit3 arriba, bit4 A, bit5 B |
| `0xD0 <dx> <dy> <btn>` | **Ratón**: deltas con signo (+ = derecha/abajo, tal cual del host), `btn` bit0 izquierdo, bit1 derecho, activo alto |
| `0x04` | Orden: **turbo toggle** (F11). La única orden cableada en `top.v` |
| `0x01`, `0x02`, `0x03` | Órdenes históricas (scanlines, reset, OSD). Decodificadas, sin conectar |

Dos propiedades de diseño que conviene no romper:

- **Todo es aditivo.** Una FPGA vieja ignora los opcodes que no conoce y los operandos
  caen como opcodes desconocidos, también ignorados. Así se pudo añadir el ratón y el
  joystick sin obligar a reflashear las dos cosas a la vez.
- **El resync cada 250 ms cura cualquier byte perdido.** Un MAKE que se pierde deja una
  tecla pulsada como mucho 250 ms. Y hay un **vigilante de ~1 s** en la FPGA: sin bytes
  durante ese tiempo suelta toda la matriz y pone los joysticks a cero. Desenchufar la
  Pico en caliente no deja nada colgado.

## Lo que hace el firmware

- **Teclado HID → matriz MSX**: la tabla en `inc/keymaps.h`. Distribución internacional
  (la de la BIOS); no hay ñ porque la fuente de la BIOS no la tiene.
- **F11** = orden `0x04` (turbo). El resto de F1-F10 son las teclas de función del MSX.
- **Mandos**: HID genérico (DirectInput) y **XInput** (`xinput_host.c`). Todos los mandos
  van al **puerto 1** (`joy_set_state(0, …)`): el firmware no reparte un segundo mando al
  puerto 2. Los botones 3 y 4 son **autofire** a 10 Hz (`AF_HALF_PERIOD_US = 50 ms`; no
  bajar de ~40 ms o el PAL a 50 Hz se pierde pulsaciones).
- **Ratón**: se reenvían los informes HID tal cual (deltas sin negar; negarlos es cosa
  del RTL). LED de la Pico Zero en cian cuando hay ratón montado.
- **Hubs**: funcionan; un teclado + un mando + un ratón por un hub alimentado es el
  montaje normal. Teclados con hub interno a veces no enumeran.

## El lado FPGA

`kbd_uart_rx.v` corre entero en `clk_54m` (el pin RX pasa por un sincronizador de dos
flops; no hay CDC multi-bit). Expone:

- `vkey_row_out`: la fila de la matriz virtual para la columna que el PPI tiene
  seleccionada (`vkey_col`, nibble bajo del puerto C). En `top.v` se hace AND con la
  lectura del `0xA9`, así que si algún día hubiera un teclado físico convivirían.
- `joy_state0/1`: guardados activos a alto tal cual llegan; `top.v` los reordena al
  formato activo-bajo del PSG y los mezcla en la lectura del `0xA2`.
- `cmd_turbo_toggle`: pulso de un ciclo que en `top.v` hace `turbo <= ~turbo`
  (la misma variable que mueve el puerto Panasonic `0x41`).
- `mouse_*`: hacia `msx_mouse.v`.

## El ratón: `msx_mouse.v`

El ratón MSX no es de cuadratura: es "inteligente" y habla por **handshake con el pin 8**
del puerto de joystick. El MSX mueve ese pin y el ratón presenta **cuatro nibbles** por
los bits 0-3 del puerto A del PSG (X alto, X bajo, Y alto, Y bajo); los botones van en
los bits 4-5, activos a bajo. El módulo sigue el protocolo de **openMSX**
(`src/input/Mouse.cc`), no de memoria, y hay cuatro detalles que documenta su cabecera y
que se pierde quien lo escribe de oído:

1. Son **ocho fases**, no cuatro: una ronda completa es el ciclo principal y un ciclo
   alterno que devuelve deltas a cero a propósito (es como el software distingue un
   ratón de un trackball).
2. Se avanza por **flanco** del strobe, no por nivel (por nivel la máquina avanzaría
   sola y perdería movimiento). Cazado por `tb_msx_mouse`, prueba 1.
3. **El delta va negado**: mover a la derecha da delta negativo.
4. **Timeout de 1,5 ms** sin actividad → la fase vuelve al final del ciclo alterno, de
   forma que el siguiente strobe alto empieza una ronda limpia. Tiene que ser menor que
   un frame para que el joytest funcione (bug #474 de openMSX).

El delta se entrega saturado a ±127 y se **consume** del acumulador en vez de borrarlo:
así los movimientos lentos no desaparecen al dividir por la sensibilidad, que es la
trampa clásica de un ratón USB moderno con mucho más DPI que uno de MSX. El ratón vive
en el **puerto 2** (strobe `psgPB[5]`); el puerto `0x2B` expone la fase para depurar.

## Latencia

De la tecla al MSX, con teclado USB:

| Tramo | Típico |
|---|---|
| Sondeo USB del teclado (intervalo HID típico) | 1-8 ms, media ~4 |
| Firmware + UART (2 bytes a 115200) | ~0,2 ms |
| Hasta que el MSX lee esa fila del PPI (barrido de la BIOS por interrupción) | 0-20 ms, media ~8-10 |
| **Total** | **~14 ms** típico, 30 peor caso |

El tramo grande es el barrido del propio MSX, que sería el mismo con un teclado físico.
El BL616 de la placa por SPI (lo que usaba la v1.x) daba lo mismo: el USB y el barrido
mandan, el cable no.

## Compilar el firmware

`fpga/rp2040/README.md` tiene el detalle. Resumen: Pico SDK + TinyUSB, `cmake -G Ninja
.. && ninja`. Salen dos `.uf2`: `rp2040_keyboard.uf2` para la RP2040-Zero (LED NeoPixel
en GPIO16, por defecto) y `rp2040_keyboard_pico.uf2` para la Pico (`-DRP2040_ZERO=0`,
LED en GPIO25). El pin de la UART es GP15 en las dos. Si tocas el firmware, recompila
las dos. Se graban arrastrando el `.uf2` con la placa en modo BOOTSEL.

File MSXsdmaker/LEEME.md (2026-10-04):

# MSX SD Maker 1.3 — preparar la tarjeta SD

*[English version](README.md)*

**MSX SD Maker** deja una tarjeta SD lista para usar en un **MSXimus** (Tang Console 60K, Tang Mega 138K o la versión Zynq), un **MSXnano** o una **MSX Pico**. En unos segundos hace todo esto:

1. Borra la tarjeta y la parte en particiones que MSX-DOS entiende.
2. Formatea cada partición.
3. Copia el sistema operativo (Nextor o MSX-DOS) en la primera partición.
4. Copia una colección de programas: SofaRun, Multi Mente, utilidades, red, música…
5. Escribe un `AUTOEXEC.BAT` que lo deja todo a mano al arrancar.
6. Relee lo escrito para comprobar que la tarjeta ha quedado bien.

No hay nada que instalar: es un solo fichero, `MSXsdmaker.exe`.

---

## Índice

1. [Qué necesitas](#1-qué-necesitas)
2. [Abrir el programa](#2-abrir-el-programa)
3. [Paso a paso](#3-paso-a-paso)
4. [Qué queda en la tarjeta](#4-qué-queda-en-la-tarjeta)
5. [El primer arranque en el MSX](#5-el-primer-arranque-en-el-msx)
6. [Poner juegos y programas](#6-poner-juegos-y-programas)
7. [Guardar como imagen en vez de tarjeta](#7-guardar-como-imagen-en-vez-de-tarjeta)
8. [Problemas frecuentes](#8-problemas-frecuentes)
9. [Para curiosos: cómo lo hace](#9-para-curiosos-cómo-lo-hace)
10. [Licencias y créditos](#10-licencias-y-créditos)

---

## 1. Qué necesitas

- **Un PC con Windows 10 u 11.**
- **Un lector de tarjetas**: el del portátil o uno USB.
- **Una tarjeta SD o microSD de 4 GB o más.** Lo más práctico es de 8 a 32 GB. Una de más de 32 GB también vale, pero con FAT16 solo se usan 8 particiones.
- **Saber qué versión de Nextor lleva tu máquina.** Depende del pack de BIOS o del `BOOT` que grabaste. Lo verás en el [paso 3.3](#33-el-sistema).

> ⚠️ **El programa borra la tarjeta entera.** Si tiene algo que quieras conservar, cópialo antes al PC.

---

## 2. Abrir el programa

1. Descarga el ZIP de la [última versión de MSX SD Maker](https://github.com/Papipapito/SD_Maker/releases/latest) (`MSX_SD_Maker_<versión>.zip`), en su repositorio ([SD_Maker](https://github.com/Papipapito/SD_Maker)), y **descomprímelo** donde quieras: dentro está `MSXsdmaker.exe` con estas instrucciones. En los repositorios de las máquinas también hay una copia en la carpeta `MSXsdmaker`.
2. Mete la tarjeta en el lector.
3. Haz doble clic en `MSXsdmaker.exe`.
4. Windows pregunta si permites que haga cambios en el equipo: responde **Sí**. Hace falta porque el programa escribe la tarjeta entera, tabla de particiones incluida.

**Versiones nuevas**: al abrirse, el programa mira en GitHub si hay una versión más nueva de MSX SD Maker; si la hay, lo dice y ofrece abrir la página de descarga. Sin internet no pasa nada.

**Si Windows muestra «Windows protegió su PC»** (SmartScreen): pulsa **Más información** y después **Ejecutar de todas formas**. Sale porque el programa no está firmado digitalmente.

**Si el antivirus se queja**: los programas hechos en Python y empaquetados en un solo `.exe` dan a veces falsos positivos. El código fuente está en [SD_Maker](https://github.com/Papipapito/SD_Maker) (y una copia en la carpeta `fuente/`).

---

## 3. Paso a paso

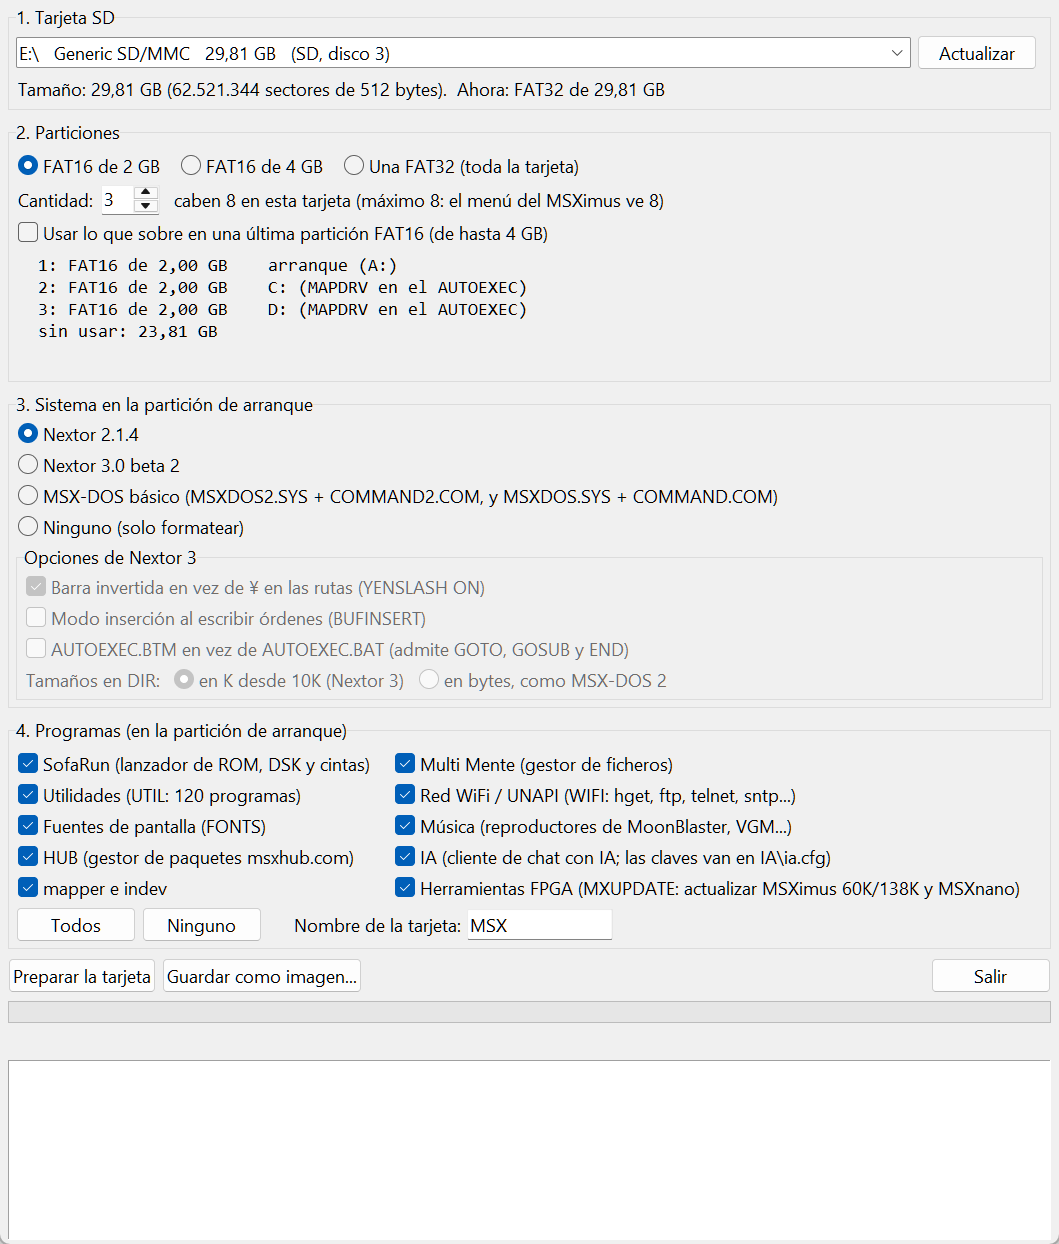
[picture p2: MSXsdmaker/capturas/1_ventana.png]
La ventana de MSX SD Maker


La ventana tiene cuatro bloques, de arriba abajo. Rellénalos en orden y pulsa **Preparar la tarjeta**.

### 3.1 La tarjeta

La lista de arriba muestra las tarjetas conectadas: letra de unidad, nombre del lector, tamaño y tipo. Si acabas de meter la tarjeta y no sale, pulsa **Actualizar**.

Debajo se ve el tamaño exacto y cómo está la tarjeta ahora; por ejemplo «Ahora: FAT32 de 29,81 GB».

> 🛡️ **Solo aparecen lectores de tarjetas SD y memorias USB extraíbles.** El disco donde está Windows no aparece nunca, y los discos duros externos tampoco. Aun así, fíjate bien en el tamaño antes de seguir.

### 3.2 Las particiones

Una **partición** es un trozo de la tarjeta que el MSX ve como una unidad de disco independiente (A:, C:, D:…). MSX-DOS no puede usar discos enormes, por eso la tarjeta se reparte en trozos que sí entiende.

| Opción | Tamaño de cada partición | Para qué sirve |
|---|---|---|
| **FAT16 de 2 GB** | 2 GB | **La opción recomendada.** Cada fichero ocupa como mínimo 32 KB, así que se desperdicia poco con ROM y DSK pequeños. |
| **FAT16 de 4 GB** | 4 GB, el máximo de Nextor | Menos particiones y más grandes. Cada fichero ocupa como mínimo 64 KB. |
| **Una FAT32** | Toda la tarjeta | Solo para el menú del MSXimus (ROM y DSK) y la MSX Pico. **MSX-DOS no la ve** (ver el aviso de abajo). |

**Cantidad.** El programa te dice cuántas particiones caben en tu tarjeta y no te deja pasar de ahí. El máximo es 8, que son las que recorre el menú del MSXimus. Si la tarjeta es más pequeña que una partición entera (las de «2 GB» tienen menos de 2 GB de verdad), se hace una sola partición con toda la tarjeta.

**«Usar lo que sobre en una última partición FAT16».** Márcalo para no desperdiciar el trozo final de la tarjeta: se crea una partición más, más pequeña, con lo que quede (hasta 4 GB). Si no lo marcas, ese espacio queda libre y ni Windows ni el MSX lo ven.

Debajo verás cómo quedará la tarjeta. Por ejemplo:

```
  1: FAT16 de 2,00 GB    arranque (A:)
  2: FAT16 de 2,00 GB    C: (MAPDRV en el AUTOEXEC)
  3: FAT16 de 2,00 GB    D: (MAPDRV en el AUTOEXEC)
  sin usar: 23,81 GB
```

Cuántas caben en las tarjetas más habituales (su capacidad real es algo menor que la de la etiqueta):

| Tarjeta | FAT16 de 2 GB | + lo que sobra | FAT16 de 4 GB | + lo que sobra |
|---|---|---|---|---|
| 2 GB | 1 con toda la tarjeta | — | 1 con toda la tarjeta | — |
| 4 GB | 1 | + 1 de 1,7 GB | 1 con toda la tarjeta | — |
| 8 GB | 3 | + 1 de 1,4 GB | 1 | + 1 de 3,4 GB |
| 16 GB | 7 | + 1 de 0,8 GB | 3 | + 1 de 2,8 GB |
| 32 GB | 8 | — | 7 | + 1 de 1,7 GB |
| 64 GB o más | 8 | — | 8 | — |

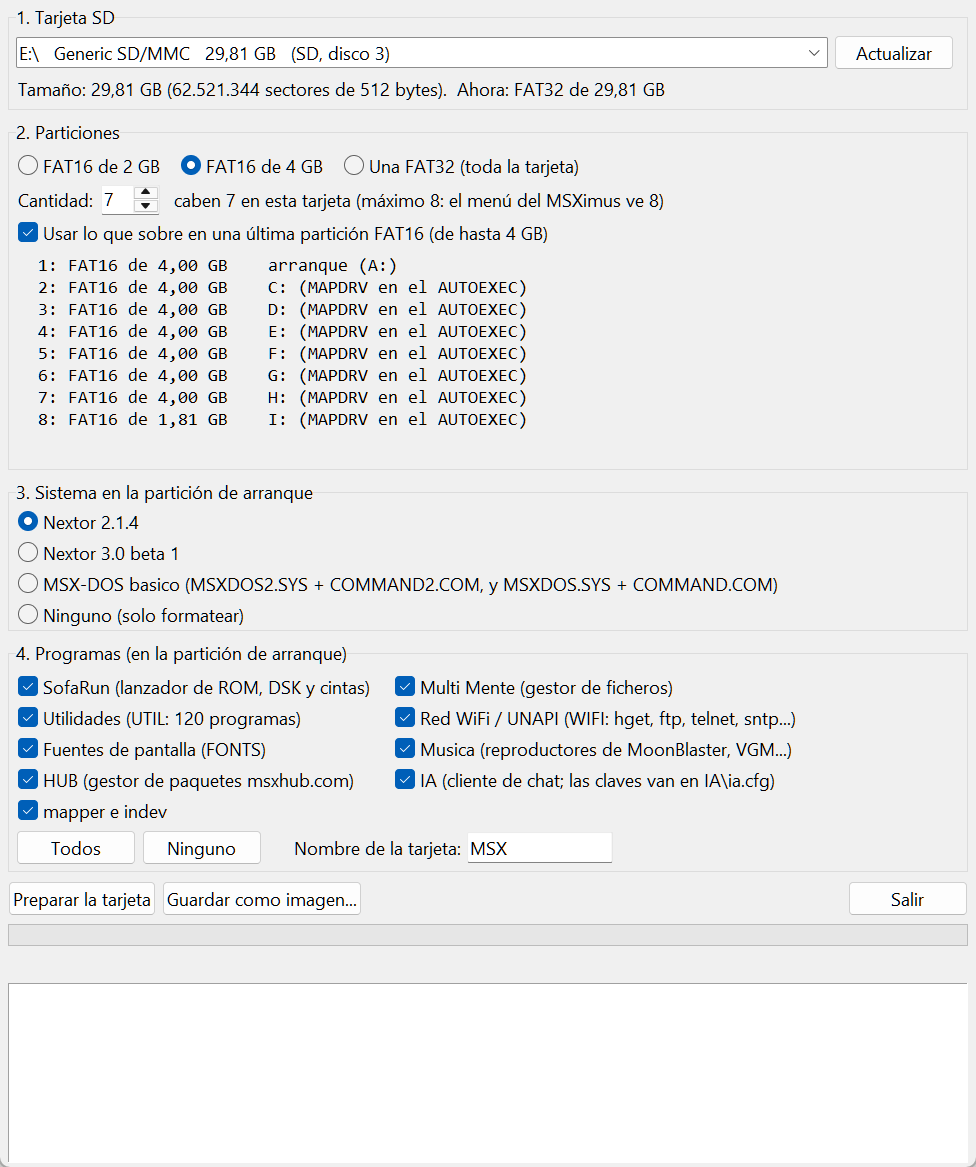
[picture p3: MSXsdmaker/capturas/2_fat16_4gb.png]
FAT16 de 4 GB con el sobrante aprovechado


> ⚠️ **FAT32 y MSX-DOS.** Ni Nextor 2.1.4 ni Nextor 3.0 leen particiones FAT32. Con una tarjeta FAT32 el MSX **no arrancará MSX-DOS** desde ella; saldrá el menú del MSXimus o BASIC. En el MSXimus, además, el menú no descarga del File-Hunter ni guarda la SRAM de los cartuchos en FAT32: solo lanza ROM y DSK. Elígela solo para eso o para la MSX Pico.
>
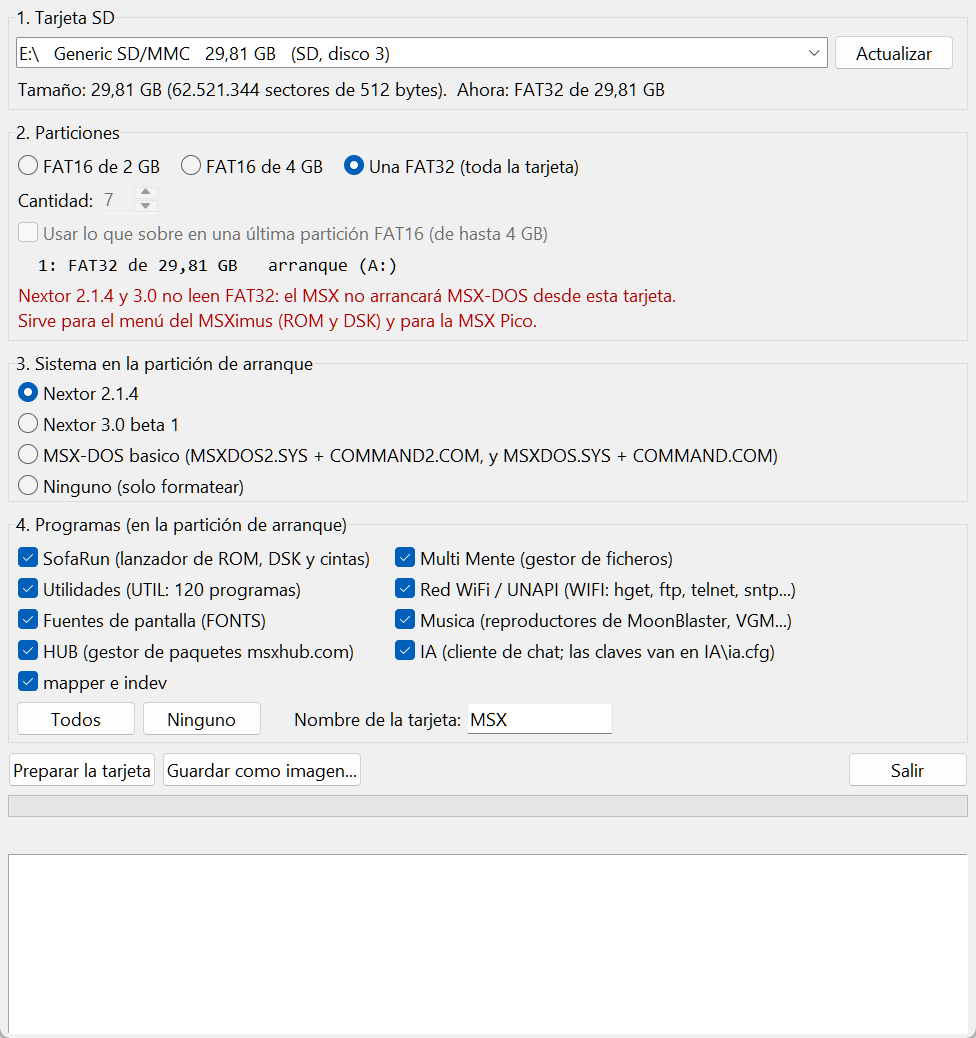
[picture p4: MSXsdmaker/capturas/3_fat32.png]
Aviso de FAT32
> 

### 3.3 El sistema

Es el sistema operativo que se copia en la primera partición, la de arranque. **Tiene que coincidir con el Nextor que lleva tu máquina**: si no, el MSX no llega a MSX-DOS.

| Tu máquina | Si grabaste… | Elige |
|---|---|---|
| MSXimus 60K o 138K | `pack_bios_msximus.bin` o `pack_bios_msximus_en.bin` | **Nextor 2.1.4** |
| MSXimus 60K o 138K | `pack_bios_msximus_nextor3.bin` o `…_en_nextor3.bin` | **Nextor 3.0 beta 2** |
| MSXimus Z (Zynq) | un `BOOT_…_nextor214.bin` | **Nextor 2.1.4** |
| MSXimus Z (Zynq) | un `BOOT_…_nextor3.bin` | **Nextor 3.0 beta 2** |
| MSXnano | `pack_bios_msxnano.bin` o `pack_bios_msxnano_en.bin` | **Nextor 2.1.4** |
| MSXnano | `pack_bios_msxnano_nextor3.bin` o `…_en_nextor3.bin` | **Nextor 3.0 beta 2** |
| Goa'uld | `pack_bios_goauld_es.bin` o `pack_bios_goauld_en.bin` | **Nextor 2.1.4** |
| MSX Pico u otro MSX con Nextor 2.1 | — | **Nextor 2.1.4** |

Las otras dos opciones:

- **MSX-DOS básico**: solo `MSXDOS2.SYS` y `COMMAND2.COM`, más `MSXDOS.SYS` y `COMMAND.COM` de MSX-DOS 1, sin las herramientas de Nextor. Sin ellas el `AUTOEXEC` no puede montar C:, D:…; se hace a mano con `CALL MAPDRV` desde BASIC.
- **Ninguno (solo formatear)**: particiona y formatea, sin sistema ni programas. Útil para una tarjeta solo de juegos.

**Opciones de Nextor 3.** Con Nextor 3 se activa un recuadro con cuatro opciones del arranque:

| Opción | Qué hace | Por defecto |
|---|---|---|
| Barra invertida en vez de ¥ (`YENSLASH ON`) | Las rutas se ven `A:\DIR\FICHERO` y no con el yen de los MSX japoneses. Desde la beta 2, `YENSLASH` es una orden del propio `COMMAND3.COM` | Marcada |
| Modo inserción (`SET BUFINSERT=ON`) | Al escribir una orden, lo que tecleas se inserta en vez de sobrescribir. INS cambia de modo, como siempre | Sin marcar |
| `AUTOEXEC.BTM` en vez de `AUTOEXEC.BAT` | `COMMAND3.COM` lo carga entero, así que admite `GOTO`, `GOSUB`, `RETURN` y `END` | Sin marcar |
| Tamaños en DIR | En K desde 10K (lo de Nextor 3) o siempre en bytes, como MSX-DOS 2 (`SET DIRK=0`). `DIRB` los da siempre en bytes | En K |

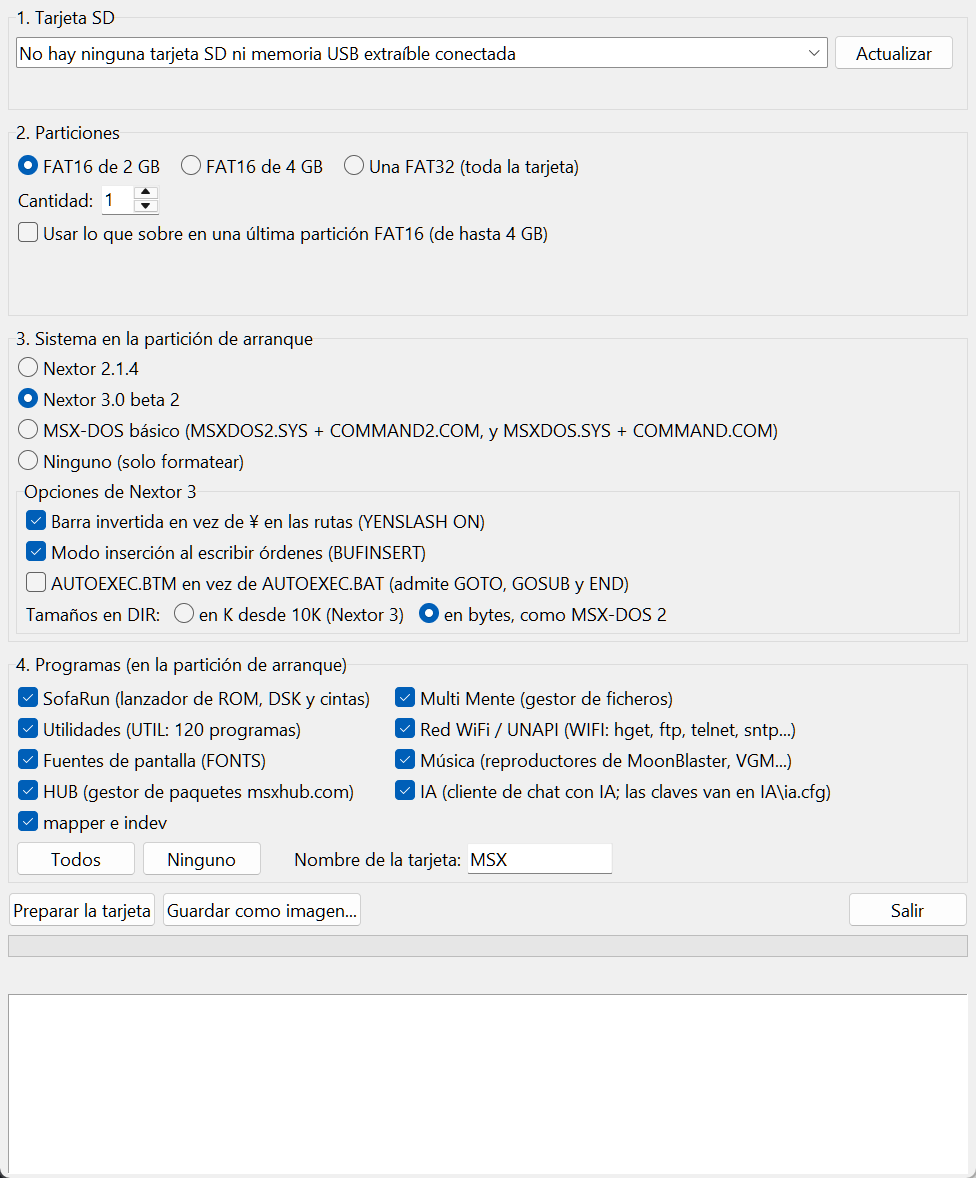
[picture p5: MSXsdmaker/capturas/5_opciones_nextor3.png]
Opciones de Nextor 3


> ℹ️ MSX-DOS 1 solo arranca desde particiones FAT12 de 16 MB o menos, que no son las que crea este programa. Por eso con cualquiera de estas opciones arranca MSX-DOS 2, y los ficheros de MSX-DOS 1 van solo por si los necesitas.

### 3.4 Los programas

Se copian en la primera partición, cada uno en su carpeta. Marca los que quieras; los botones **Todos** y **Ninguno** ayudan.

| Casilla | Carpeta | Qué es | Cómo se abre |
|---|---|---|---|
| SofaRun | `SOFARUN` | Lanzador de ROM, DSK y cintas CAS con menú, de Louthrax | `SR` |
| Multi Mente | `MM` | Gestor de ficheros de dos paneles | `MM` |
| Utilidades | `UTIL` | Unas 120 herramientas: `DI` (DIR con nombres largos), `LOGIN`, reproductores, copias… | por su nombre |
| Red WiFi / UNAPI | `WIFI` | Programas de red TCP/IP: `HGET`, `FTP`, `TELNET`, `SNTP`, `FH` (File-Hunter)… | por su nombre |
| Fuentes de pantalla | `FONTS` | Tipos de letra para Multi Mente (ISO Latin-1, japonés, ruso…) | los usa MM |
| Música | `musica` | Reproductores de MoonBlaster Wave, VGM y más | por su nombre |
| HUB | `hub` | Cliente de MSX Hub, para instalar programas desde internet | `HUBG` o `HUB` |
| IA | `IA` | Cliente de chat con IA; tus claves van en `IA\ia.cfg` | `IA` |
| mapper e indev | `mapper`, `indev.com` | `MAPPER` desactiva el mapeador de MSX-DOS 2 para programas antiguos | por su nombre |
| Herramientas FPGA | `FPGA` | `MXUPDATE`: actualiza el core y el pack del MSXimus 60K/138K y del MSXnano (2.1.1 o posterior) desde MSX-DOS, con un `.UPD` de la tarjeta o por WiFi (`MXUPDATE /N`); por WiFi se pone al día él mismo antes de nada. `MXUPDATE /?` enseña las órdenes. El MSXimus Z (Zynq) se actualiza por su cuenta | `MXUPDATE` |

Siempre que haya sistema se crean también estas carpetas vacías. **No las borres**:

- `FHUNT`: donde el menú del MSXimus guarda lo que descarga del File-Hunter. El menú no puede crear carpetas, así que tiene que existir.
- `TMP`: carpeta temporal de MSX-DOS y de SofaRun.
- `SAVES` y `SETTINGS`, si marcaste SofaRun: sus partidas guardadas y su configuración.

**Nombre de la tarjeta**: es el nombre de la partición 1 que verás en Windows y con `VOL` en MSX-DOS. Las demás se llaman igual con su número detrás: «MSX 2», «MSX 3»…

### 3.5 Preparar

1. Pulsa **Preparar la tarjeta**.
2. El programa te enseña **qué va a borrar** (nombre, tamaño y unidades de la tarjeta) y **qué va a crear**. Léelo con calma. Solo sigue si respondes **Sí**; el botón por defecto es No.
3. La barra avanza mientras trabaja. Tarda unos segundos; con FAT32 en tarjetas grandes, algo más.
4. Al final, **verifica**: vuelve a leer la tabla de particiones y cada fichero copiado, y los compara con lo que quería escribir. Si todo cuadra, dice **«La tarjeta está lista y verificada»**.
5. Windows vuelve a montar la tarjeta solo. Cada partición aparece con su propia letra de unidad.

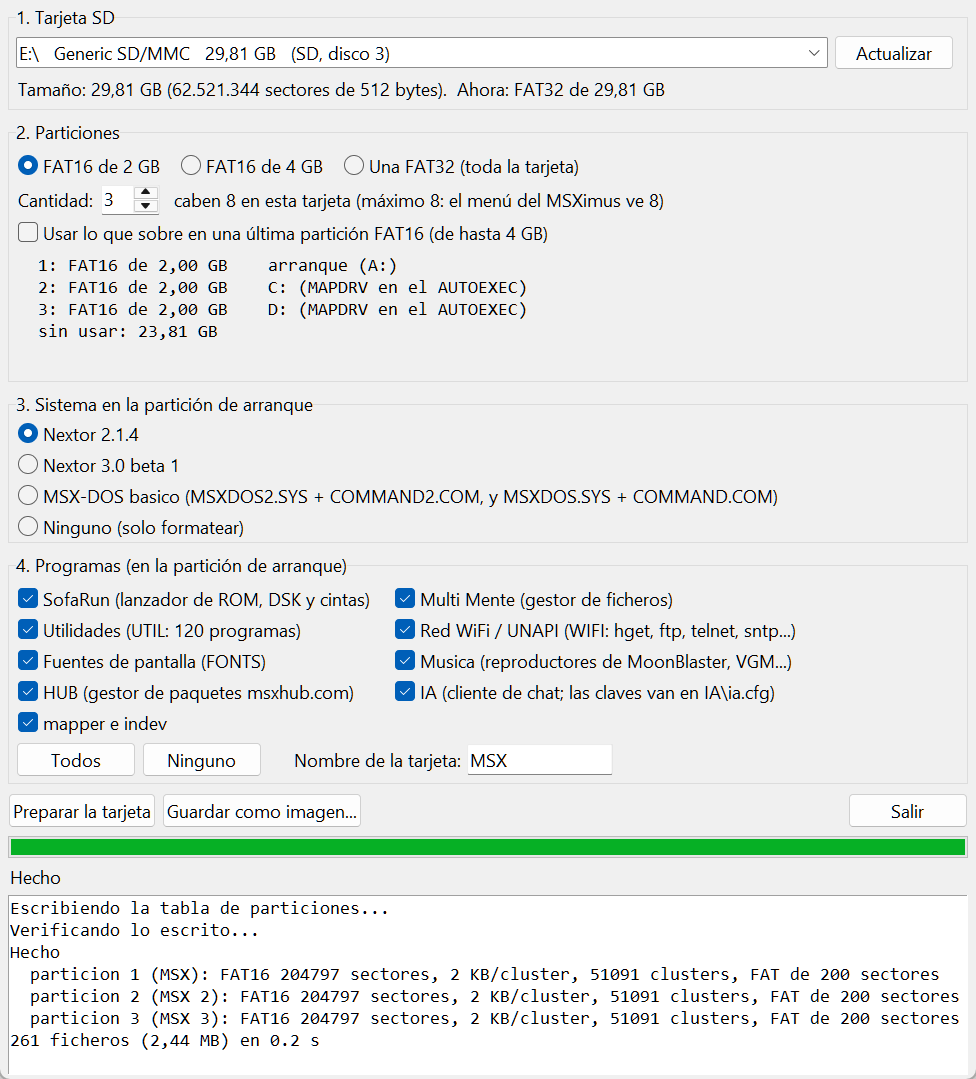
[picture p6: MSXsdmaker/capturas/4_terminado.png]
Tarjeta terminada


Ya puedes sacar la tarjeta. Usa «Expulsar» en Windows antes de quitarla, como con cualquier memoria.

---

## 4. Qué queda en la tarjeta

La **partición 1** (A: en el MSX), con Nextor 2.1.4 y todos los programas:

```
A:\
├── NEXTOR.SYS, COMMAND2.COM       el sistema (con Nextor 3: COMMAND3.COM)
├── MSXDOS2.SYS, MSXDOS.SYS…       sistema de respaldo
├── AUTOEXEC.BAT                   se ejecuta al arrancar (ver abajo)
├── bin\                           herramientas de Nextor: MAPDRV, DRIVERS, DEVINFO…
├── SOFARUN\  SAVES\  SETTINGS\    SofaRun y lo suyo
├── MM\  FONTS\                    Multi Mente y sus fuentes
├── UTIL\  WIFI\  musica\          utilidades, red y música
├── hub\  IA\  mapper\  indev.com
├── FPGA\                          MXUPDATE: actualizar el core del MSXimus y del MSXnano
├── FHUNT\                         descargas del File-Hunter (no borrar)
└── TMP\                           temporal (no borrar)
```

Las **particiones 2, 3…** quedan vacías para tus juegos y programas.

### El AUTOEXEC.BAT

Se genera según lo que hayas elegido. Con todo marcado y tres particiones queda así:

```
PATH A:\;%1\BIN;%1\SOFARUN;%1\MM;%1\UTIL;%1\WIFI;%1\musica;%1\hub;%1\IA;%1\mapper;%1\FPGA
SET TIMEZONE=+02:00
mode 80
ALIAS .BAS = "BASIC "
ALIAS .ASC = "BASIC "
sntp pool.ntp.org /v
set temp %1\TMP
set MM=%1\MM
alias .ROM srom
alias .DSK sri
yenslash
SET FONT0808=%1\FONTS\ISO-LAT1.FNT
echo Type LOGIN to show system info (not for MSX1!)
echo Type DI for DIR with long filenames
echo Type SR to start Sofarun
echo Type MM to start Multi Mente
echo Type HUBG to start HUB Gui or HUB to CLI
echo Type FH to FileHunter Download
echo
echo Maped Units C,D
mapdrv c: 2 1 0
mapdrv d: 3 1 0
```

Qué hace cada parte:

- **`PATH`**: puedes escribir el nombre de cualquier programa desde cualquier carpeta, sin la ruta. `%1` es la unidad de arranque.
- **`SET TIMEZONE`**: la zona horaria (+02:00, horario de verano peninsular). Cámbiala si hace falta.
- **`mode 80`**: pantalla de 80 columnas.
- **`ALIAS`**: escribiendo el nombre de un `.BAS` se abre en BASIC; el de un `.ROM` o un `.DSK`, se lanza con SofaRun.
- **`sntp`**: pone el reloj en hora por internet, si hay red. Sin red da un error y sigue: es normal.
- **`mapdrv c: 2 1 0`**: monta la partición 2 como unidad C:, la 3 como D:, y así sucesivamente.

Con **Nextor 3**, en lugar de `yenslash` van las líneas de sus opciones (`YENSLASH ON`, y `SET BUFINSERT=ON` y `SET DIRK=0` si las marcas), y el fichero se llama `AUTOEXEC.BTM` si eliges esa opción.

Puedes editar el `AUTOEXEC.BAT` desde Windows con el Bloc de notas. Guárdalo sin cambiarle el nombre.

---

## 5. El primer arranque en el MSX

1. Mete la tarjeta en la máquina y enciéndela.
2. **MSXimus y MSXnano**: si tienes activado «Menú al arrancar» en Ajustes, sale el navegador de la tarjeta.
   - La línea de abajo dice en qué partición estás, por ejemplo `P1/3`. **TAB** pasa a la siguiente.
   - **R**, **D** y **A** filtran por ROM, DSK o todo.
   - **ESC** sale del menú y arranca MSX-DOS desde la tarjeta.
3. MSX-DOS arranca, ejecuta el `AUTOEXEC.BAT` y queda en `A:\>`. Algo así (probado en un MSXimus Z con una tarjeta de tres particiones):

```
SNTP time setter for the TCP/IP UNAPI 1.1
*** ERROR: Unknown error when opening UDP connection (code 15)      <- sin red: normal
Type LOGIN to show system info (not for MSX1!)
Type DI for DIR with long filenames
Type SR to start Sofarun
Type MM to start Multi Mente
Type HUBG to start HUB Gui or HUB to CLI
Type FH to FileHunter Download

Maped Units C,D
A:\>vol c:
 Volume in drive C: is MSX 2
A:\>vol d:
 Volume in drive D: is MSX 3
```

Órdenes útiles para empezar:

| Escribe | Para |
|---|---|
| `SR` | SofaRun: elegir y lanzar ROM, DSK y cintas |
| `MM` | Multi Mente: copiar, mover y borrar ficheros |
| `DI` | Listar la carpeta con los nombres largos |
| `DIR C:` | Ver lo que hay en la partición 2 |
| `LOGIN` | Información del sistema |
| `BASIC` | Ir a MSX-BASIC |

---

## 6. Poner juegos y programas

Con la tarjeta en el PC, cada partición es una unidad de Windows. Copia los ficheros arrastrándolos como a cualquier memoria USB.

Una forma cómoda de organizarse:

| Partición | En el MSX | Para |
|---|---|---|
| 1 | A: | Sistema y programas (déjala como está) |
| 2 | C: | ROM de cartucho |
| 3 | D: | Discos DSK |
| 4 | E: | Música, imágenes, lo que quieras |

Hay que saber:

- **Nombres largos.** El menú del MSXimus y Windows los ven completos, como «Aleste 2 (1988).rom». MSX-DOS y SofaRun ven el nombre corto de 8+3 letras que Windows genera, como `ALESTE~1.ROM`.
- **El menú del MSXimus** recorre todas las particiones con TAB y lanza ROM y DSK sin pasar por MSX-DOS.
- **No formatees las particiones desde Windows.** Windows les cambiaría el formato o el tamaño de cluster. Para empezar de cero, vuelve a pasar la tarjeta por MSX SD Maker.
- **No borres `FHUNT` ni `TMP`** de la partición 1.

---

## 7. Guardar como imagen en vez de tarjeta

**Guardar como imagen…** crea un fichero `.img` con la tarjeta entera, en lugar de escribirla. Sirve para:

- Preparar varias tarjetas iguales: se graba la imagen con Rufus, balenaEtcher o Win32 Disk Imager.
- Probar en un emulador.
- Guardar una copia de una configuración.

El programa pregunta el tamaño de la imagen. Una imagen se puede grabar en una tarjeta de ese tamaño **o mayor**, nunca menor, y las tarjetas tienen algo menos de lo que dice la etiqueta: `1800M` cabe en cualquiera de 2 GB y `3500M` en cualquiera de 4 GB. La imagen solo ocupa en el disco del PC lo que se ha escrito de verdad, no su tamaño entero.

Con cada versión del MSXimus se publica también una imagen ya hecha con Nextor 3 (1800 MB, con todos los programas): basta con grabarla.

---

## 8. Problemas frecuentes

**La tarjeta no aparece en la lista.**
Comprueba que está bien metida y pulsa **Actualizar**. Solo salen lectores SD y memorias USB extraíbles. Algunos adaptadores USB-SATA o USB-NVMe se presentan como disco fijo y no salen, a propósito.

**«La unidad E: está en uso: cierra lo que la tenga abierta».**
Cierra las ventanas del Explorador que muestren la tarjeta y los programas que tengan ficheros suyos abiertos. Vuelve a intentarlo.

**El programa dice que hacen falta permisos de administrador.**
Ábrelo con doble clic y responde **Sí** en la ventana de Windows.

**El MSX no llega a MSX-DOS.**
- ¿El sistema que elegiste coincide con el pack de BIOS o el `BOOT` de tu máquina? Mira la tabla del [paso 3.3](#33-el-sistema).
- ¿Elegiste FAT32? MSX-DOS no la lee.
- ¿Está «Menú al arrancar» activado? Entonces sale el menú primero: pulsa **ESC**.

**En MSX-DOS no aparecen C: ni D:.**
Con «MSX-DOS básico» no se copian las herramientas de Nextor, así que el `AUTOEXEC` no puede montarlas. Hazlo desde BASIC con `CALL MAPDRV`, o vuelve a preparar la tarjeta con Nextor.

**Sale «ERROR … opening UDP connection» al arrancar.**
Es `SNTP`, que intenta poner la hora por internet y no hay red. No afecta a nada. Si te molesta, borra esa línea del `AUTOEXEC.BAT`.

**La verificación ha encontrado errores.**
La tarjeta o el lector pueden estar fallando. Prueba otra vez y, si se repite, con otro lector u otra tarjeta.

**¿Puedo tener más de 8 particiones?**
No. El menú del MSXimus ve 8, y Nextor solo busca en las 9 primeras al arrancar.

**Windows dice que la tarjeta es más pequeña de lo que pone en la etiqueta.**
Es normal: los fabricantes cuentan 1 GB como 1.000 millones de bytes y Windows como 1.073 millones.

**¿Toca algo de mi PC?**
No. Solo escribe en la tarjeta que elijas, y el disco de Windows nunca aparece en la lista.

---

## 9. Para curiosos: cómo lo hace

- **Reparte la tarjeta igual que el `FDISK` de Nextor**, la herramienta que se abre con `CALL FDISK`. La partición 1 es primaria, activa y empieza en el sector 1. Las demás son lógicas dentro de una partición extendida. Así Nextor las numera 1, 2, 3… y `MAPDRV` las encuentra.
- **La FAT16 usa la geometría del `FDISK` de Nextor**: clusters de 2 a 64 KB según el tamaño, como mucho 65.524 clusters y 512 entradas en la raíz.
- **La FAT32** empieza en el sector 8192, con los datos alineados a 4 MB, como hace el formateador de la SD Association.
- **Nombres**: guarda el nombre corto de 8+3 que lee MSX-DOS y, si hace falta, también el nombre largo que ven Windows y el menú.
- **La tabla de particiones se escribe al final**, cuando todo lo demás ya está en su sitio. Luego se relee y se compara cada fichero con su CRC32.

El código fuente y el contenido de la tarjeta están en [SD_Maker](https://github.com/Papipapito/SD_Maker); en los repositorios de las máquinas hay una copia del programa en [`fuente/`](fuente/) (Python 3 con tkinter; `construir_exe.bat` hace el `.exe` con PyInstaller). Para usarlo sin el `.exe` hace falta el contenido de la tarjeta en una carpeta `sd/` junto a `MSXsdmaker.py`, con `base/`, `nextor-2.1.4/`, `nextor-3.0.0-beta2/` y `extras/`. El `.exe` ya lo lleva dentro. Desde la línea de órdenes también se pueden hacer imágenes:

```
python MSXsdmaker.py imagen prueba.img --tamano 8G --esquema fat16-2g --n 3 --sistema nextor214 --programas todos
python MSXsdmaker.py imagen n3.img --tamano 1800M --sistema nextor3 --bufinsert --dirk bytes --btm
```

Con Nextor 3: `--sin-yenslash`, `--bufinsert`, `--dirk bytes` y `--btm` son las opciones del recuadro.

---

## 10. Licencias y créditos

MSX SD Maker es parte del proyecto MSXimus / MSXnano, de Albert (Papipapito), bajo GPL v3 como el resto del proyecto.

Los programas que copia en la tarjeta son de sus autores: Nextor y MSX-DOS, SofaRun, Multi Mente, las herramientas UNAPI, HUB y más. Mira [LICENCIAS.md](LICENCIAS.md): lleva la lista y el aviso de licencia de Nextor, que exige acompañar a sus ficheros.

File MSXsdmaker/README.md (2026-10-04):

# MSX SD Maker 1.3 — preparing the SD card

*[Versión en castellano](LEEME.md)*

**MSX SD Maker** gets an SD card ready for an **MSXimus** (Tang Console 60K, Tang Mega 138K or the Zynq version), an **MSXnano** or an **MSX Pico**. In a few seconds it does all this:

1. Wipes the card and splits it into partitions that MSX-DOS understands.
2. Formats each partition.
3. Copies the operating system (Nextor or MSX-DOS) to the first partition.
4. Copies a set of programs: SofaRun, Multi Mente, utilities, networking, music…
5. Writes an `AUTOEXEC.BAT` that sets everything up at boot.
6. Reads everything back to check that the card came out right.

Nothing to install: it is a single file, `MSXsdmaker.exe`. The program itself is in Spanish; this guide explains every option.

---

## Contents

1. [What you need](#1-what-you-need)
2. [Opening the program](#2-opening-the-program)
3. [Step by step](#3-step-by-step)
4. [What ends up on the card](#4-what-ends-up-on-the-card)
5. [First boot on the MSX](#5-first-boot-on-the-msx)
6. [Adding games and programs](#6-adding-games-and-programs)
7. [Saving an image instead of a card](#7-saving-an-image-instead-of-a-card)
8. [Troubleshooting](#8-troubleshooting)
9. [For the curious: how it works](#9-for-the-curious-how-it-works)
10. [Licenses and credits](#10-licenses-and-credits)

---

## 1. What you need

- **A PC with Windows 10 or 11.**
- **A card reader**: the laptop's own or a USB one.
- **An SD or microSD card of 4 GB or more.** 8 to 32 GB is the most practical. Bigger cards work too, but with FAT16 only 8 partitions are used.
- **To know which Nextor version your machine runs.** It depends on the BIOS pack or the `BOOT` file you flashed. See [step 3.3](#33-the-system).

> ⚠️ **The program wipes the whole card.** If it holds anything you want to keep, copy it to the PC first.

---

## 2. Opening the program

1. Download the ZIP from the [latest MSX SD Maker release](https://github.com/Papipapito/SD_Maker/releases/latest) (`MSX_SD_Maker_<version>.zip`), in its own repository ([SD_Maker](https://github.com/Papipapito/SD_Maker)), and **unzip it** anywhere: inside there is `MSXsdmaker.exe` with this guide. The machines' repositories also carry a copy in their `MSXsdmaker` folder.
2. Put the card in the reader.
3. Double-click `MSXsdmaker.exe`.
4. Windows asks whether to allow it to make changes to the device: answer **Yes**. It needs this because it writes the whole card, partition table included.

**New versions**: when it opens, the program checks GitHub for a newer MSX SD Maker; if there is one, it says so and offers to open the download page. Without internet nothing happens.

**If Windows shows "Windows protected your PC"** (SmartScreen): click **More info** and then **Run anyway**. It appears because the program is not digitally signed.

**If your antivirus complains**: Python programs packed into a single `.exe` sometimes trigger false positives. The source code is in [SD_Maker](https://github.com/Papipapito/SD_Maker) (and a copy in the `fuente/` folder).

---

## 3. Step by step

The MSX SD Maker window

The window has four blocks, top to bottom. Fill them in order and press **Preparar la tarjeta** (*Prepare the card*).

### 3.1 The card — *1. Tarjeta SD*

The list at the top shows the connected cards: drive letter, reader name, size and type. If you have just inserted the card and it is not there, press **Actualizar** (*Refresh*).

Below it you see the exact size and what is on the card now (*Ahora*), for example "FAT32 de 29,81 GB".

> 🛡️ **Only SD card readers and removable USB sticks are listed.** The disk Windows lives on never appears, and neither do external hard disks. Still, check the size carefully before going on.

### 3.2 The partitions — *2. Particiones*

A **partition** is a slice of the card that the MSX sees as a separate drive (A:, C:, D:…). MSX-DOS cannot handle huge disks, so the card is split into slices it does understand.

| Option | Size of each partition | What it is for |
|---|---|---|
| **FAT16 de 2 GB** | 2 GB | **The recommended choice.** Every file takes at least 32 KB, so little is wasted on small ROM and DSK files. |
| **FAT16 de 4 GB** | 4 GB, the Nextor maximum | Fewer, bigger partitions. Every file takes at least 64 KB. |
| **Una FAT32** | The whole card | Only for the MSXimus menu (ROM and DSK) and the MSX Pico. **MSX-DOS cannot see it** (see the warning below). |

**Cantidad** (*count*). The program tells you how many partitions fit on your card and does not let you go beyond that. The maximum is 8, the number the MSXimus menu walks through.

**"Usar lo que sobre en una última partición FAT16"** (*use the leftover space in one last FAT16 partition*). Tick it so the end of the card is not wasted: one more, smaller partition is created with what is left (up to 4 GB). If you leave it unticked, that space stays unused and neither Windows nor the MSX sees it.

Below you see how the card will end up. For example (*arranque* = boot, *sin usar* = unused):

```
  1: FAT16 de 2,00 GB    arranque (A:)
  2: FAT16 de 2,00 GB    C: (MAPDRV en el AUTOEXEC)
  3: FAT16 de 2,00 GB    D: (MAPDRV en el AUTOEXEC)
  sin usar: 23,81 GB
```

How many fit on the most common cards (their real capacity is a bit less than the label says):

| Card | FAT16 2 GB | + leftover | FAT16 4 GB | + leftover |
|---|---|---|---|---|
| 2 GB | 1 with the whole card | — | 1 with the whole card | — |
| 4 GB | 1 | + 1 of 1.7 GB | 1 with the whole card | — |
| 8 GB | 3 | + 1 of 1.4 GB | 1 | + 1 of 3.4 GB |
| 16 GB | 7 | + 1 of 0.8 GB | 3 | + 1 of 2.8 GB |
| 32 GB | 8 | — | 7 | + 1 of 1.7 GB |
| 64 GB or more | 8 | — | 8 | — |

FAT16 of 4 GB with the leftover space used

> ⚠️ **FAT32 and MSX-DOS.** Neither Nextor 2.1.4 nor Nextor 3.0 can read FAT32 partitions. With a FAT32 card the MSX **will not boot MSX-DOS** from it; you get the MSXimus menu or BASIC. On the MSXimus, the menu also cannot download from File-Hunter or save cartridge SRAM on FAT32: it only launches ROM and DSK files. Choose it only for that, or for the MSX Pico.
>
> FAT32 warning

### 3.3 The system — *3. Sistema en la partición de arranque*

This is the operating system copied to the first, boot partition. **It must match the Nextor your machine runs**; otherwise the MSX never reaches MSX-DOS.

| Your machine | If you flashed… | Choose |
|---|---|---|
| MSXimus 60K or 138K | `pack_bios_msximus.bin` or `pack_bios_msximus_en.bin` | **Nextor 2.1.4** |
| MSXimus 60K or 138K | `pack_bios_msximus_nextor3.bin` or `…_en_nextor3.bin` | **Nextor 3.0 beta 2** |
| MSXimus Z (Zynq) | a `BOOT_…_nextor214.bin` | **Nextor 2.1.4** |
| MSXimus Z (Zynq) | a `BOOT_…_nextor3.bin` | **Nextor 3.0 beta 2** |
| MSXnano | `pack_bios_msxnano.bin` or `pack_bios_msxnano_en.bin` | **Nextor 2.1.4** |
| MSXnano | `pack_bios_msxnano_nextor3.bin` or `…_en_nextor3.bin` | **Nextor 3.0 beta 2** |
| Goa'uld | `pack_bios_goauld_es.bin` or `pack_bios_goauld_en.bin` | **Nextor 2.1.4** |
| MSX Pico or another MSX with Nextor 2.1 | — | **Nextor 2.1.4** |

The other two options:

- **MSX-DOS básico** (*basic MSX-DOS*): only `MSXDOS2.SYS` and `COMMAND2.COM`, plus MSX-DOS 1's `MSXDOS.SYS` and `COMMAND.COM`, without the Nextor tools. Without them the `AUTOEXEC` cannot mount C:, D:…; do it by hand with `CALL MAPDRV` from BASIC.
- **Ninguno (solo formatear)** (*none, format only*): partitions and formats, with no system and no programs. Handy for a games-only card.

If the card is smaller than a whole partition ("2 GB" cards hold a little under 2 GB), a single partition with the whole card is made.

**Nextor 3 options** (*Opciones de Nextor 3*). With Nextor 3 a box with four boot options is enabled:

| Option | What it does | Default |
|---|---|---|
| Backslash instead of ¥ (`YENSLASH ON`) | Paths show as `A:\DIR\FILE` instead of with the yen sign of Japanese MSX computers. Since beta 2, `YENSLASH` is a command of `COMMAND3.COM` itself | Ticked |
| Insert mode (`SET BUFINSERT=ON`) | What you type at the prompt is inserted instead of overwriting. INS toggles, as always | Not ticked |
| `AUTOEXEC.BTM` instead of `AUTOEXEC.BAT` | `COMMAND3.COM` loads it whole, so it accepts `GOTO`, `GOSUB`, `RETURN` and `END` | Not ticked |
| Sizes in DIR | In K from 10K (Nextor 3's way) or always in bytes, like MSX-DOS 2 (`SET DIRK=0`). `DIRB` always shows bytes | In K |

Nextor 3 options

> ℹ️ MSX-DOS 1 only boots from FAT12 partitions of 16 MB or less, which is not what this program creates. That is why any of these options boots MSX-DOS 2; the MSX-DOS 1 files are there only in case you need them.

### 3.4 The programs — *4. Programas*

They are copied to the first partition, each in its own folder. Tick the ones you want; **Todos** (*all*) and **Ninguno** (*none*) help.

| Checkbox | Folder | What it is | How to start it |
|---|---|---|---|
| SofaRun | `SOFARUN` | ROM, DSK and CAS tape launcher with a menu, by Louthrax | `SR` |
| Multi Mente | `MM` | Two-pane file manager | `MM` |
| Utilidades | `UTIL` | About 120 tools: `DI` (DIR with long names), `LOGIN`, players, copying… | by name |
| Red WiFi / UNAPI | `WIFI` | TCP/IP networking: `HGET`, `FTP`, `TELNET`, `SNTP`, `FH` (File-Hunter)… | by name |
| Fuentes de pantalla | `FONTS` | Fonts for Multi Mente (ISO Latin-1, Japanese, Russian…) | used by MM |
| Música | `musica` | MoonBlaster Wave, VGM and other players | by name |
| HUB | `hub` | MSX Hub client, to install programs from the internet | `HUBG` or `HUB` |
| IA | `IA` | AI chat client; your keys go in `IA\ia.cfg` | `IA` |
| mapper e indev | `mapper`, `indev.com` | `MAPPER` disables the MSX-DOS 2 mapper routines for old software | by name |
| Herramientas FPGA | `FPGA` | `MXUPDATE`: updates the core and the pack of the MSXimus 60K/138K and the MSXnano (2.1.1 or later) from MSX-DOS, from a `.UPD` on the card or over WiFi (`MXUPDATE /N`); over WiFi it first brings itself up to date. `MXUPDATE /?` shows the commands. The MSXimus Z (Zynq) updates itself | `MXUPDATE` |

Whenever a system is installed these empty folders are created too. **Do not delete them**:

- `FHUNT`: where the MSXimus menu saves what it downloads from File-Hunter. The menu cannot create folders, so it must exist.
- `TMP`: temporary folder for MSX-DOS and SofaRun.
- `SAVES` and `SETTINGS`, if you ticked SofaRun: its saved games and its settings.

**Nombre de la tarjeta** (*card name*): the name of partition 1 as shown in Windows and by `VOL` in MSX-DOS. The others get the same name with their number: "MSX 2", "MSX 3"…

### 3.5 Preparing

1. Press **Preparar la tarjeta**.
2. The program shows **what it is going to wipe** (the card's name, size and drives) and **what it will create**. Read it carefully. It only goes ahead if you answer **Sí** (*Yes*); the default button is No.
3. The bar moves while it works. It takes a few seconds; somewhat longer with FAT32 on big cards.
4. At the end it **verifies**: it reads back the partition table and every copied file and compares them with what it meant to write. If everything matches it says **"La tarjeta está lista y verificada"** (*the card is ready and verified*).
5. Windows mounts the card again by itself. Each partition shows up with its own drive letter.

Finished card

You can take the card out now. Use "Eject" in Windows first, as with any memory stick.

---

## 4. What ends up on the card

**Partition 1** (A: on the MSX), with Nextor 2.1.4 and every program:

```
A:\
├── NEXTOR.SYS, COMMAND2.COM       the system (with Nextor 3: COMMAND3.COM)
├── MSXDOS2.SYS, MSXDOS.SYS…       fallback system files
├── AUTOEXEC.BAT                   runs at boot (see below)
├── bin\                           Nextor tools: MAPDRV, DRIVERS, DEVINFO…
├── SOFARUN\  SAVES\  SETTINGS\    SofaRun and its folders
├── MM\  FONTS\                    Multi Mente and its fonts
├── UTIL\  WIFI\  musica\          utilities, networking and music
├── hub\  IA\  mapper\  indev.com
├── FPGA\                          MXUPDATE: updating the MSXimus and MSXnano core
├── FHUNT\                         File-Hunter downloads (do not delete)
└── TMP\                           temporary (do not delete)
```

**Partitions 2, 3…** are left empty for your games and programs.

### The AUTOEXEC.BAT

It is generated from your choices. With everything ticked and three partitions it looks like this:

```
PATH A:\;%1\BIN;%1\SOFARUN;%1\MM;%1\UTIL;%1\WIFI;%1\musica;%1\hub;%1\IA;%1\mapper;%1\FPGA
SET TIMEZONE=+02:00
mode 80
ALIAS .BAS = "BASIC "
ALIAS .ASC = "BASIC "
sntp pool.ntp.org /v
set temp %1\TMP
set MM=%1\MM
alias .ROM srom
alias .DSK sri
yenslash
SET FONT0808=%1\FONTS\ISO-LAT1.FNT
echo Type LOGIN to show system info (not for MSX1!)
echo Type DI for DIR with long filenames
echo Type SR to start Sofarun
echo Type MM to start Multi Mente
echo Type HUBG to start HUB Gui or HUB to CLI
echo Type FH to FileHunter Download
echo
echo Maped Units C,D
mapdrv c: 2 1 0
mapdrv d: 3 1 0
```

What each part does:

- **`PATH`**: you can type any program's name from any folder, without its path. `%1` is the boot drive.
- **`SET TIMEZONE`**: the time zone (+02:00, Central European summer time). Change it if needed.
- **`mode 80`**: 80-column screen.
- **`ALIAS`**: typing the name of a `.BAS` opens it in BASIC; the name of a `.ROM` or `.DSK` launches it with SofaRun.
- **`sntp`**: sets the clock from the internet if there is a network. Without one it prints an error and carries on: that is normal.
- **`mapdrv c: 2 1 0`**: mounts partition 2 as drive C:, partition 3 as D:, and so on.

With **Nextor 3**, instead of `yenslash` come the lines of its options (`YENSLASH ON`, plus `SET BUFINSERT=ON` and `SET DIRK=0` if ticked), and the file is `AUTOEXEC.BTM` if you choose that option.

You can edit `AUTOEXEC.BAT` from Windows with Notepad. Keep its name.

---

## 5. First boot on the MSX

1. Put the card in the machine and switch it on.
2. **MSXimus and MSXnano**: if "Menú al arrancar" (*menu at boot*) is on in the Settings, the card browser appears.
   - The bottom line shows which partition you are in, for example `P1/3`. **TAB** moves to the next one.
   - **R**, **D** and **A** filter by ROM, DSK or all.
   - **ESC** leaves the menu and boots MSX-DOS from the card.
3. MSX-DOS boots, runs `AUTOEXEC.BAT` and stops at `A:\>`. Something like this (tested on an MSXimus Z with a three-partition card):

```
SNTP time setter for the TCP/IP UNAPI 1.1
*** ERROR: Unknown error when opening UDP connection (code 15)      <- no network: normal
Type LOGIN to show system info (not for MSX1!)
Type DI for DIR with long filenames
Type SR to start Sofarun
Type MM to start Multi Mente
Type HUBG to start HUB Gui or HUB to CLI
Type FH to FileHunter Download

Maped Units C,D
A:\>vol c:
 Volume in drive C: is MSX 2
A:\>vol d:
 Volume in drive D: is MSX 3
```

Useful commands to start with:

| Type | To |
|---|---|
| `SR` | SofaRun: pick and launch ROM, DSK and tapes |
| `MM` | Multi Mente: copy, move and delete files |
| `DI` | List the folder with long names |
| `DIR C:` | See what is on partition 2 |
| `LOGIN` | System information |
| `BASIC` | Go to MSX-BASIC |

---

## 6. Adding games and programs

With the card in the PC, each partition is a Windows drive. Copy files by dragging them, as with any USB stick.

A convenient way to organise it:

| Partition | On the MSX | For |
|---|---|---|
| 1 | A: | System and programs (leave it as it is) |
| 2 | C: | Cartridge ROMs |
| 3 | D: | DSK disk images |
| 4 | E: | Music, pictures, anything |

Good to know:

- **Long names.** The MSXimus menu and Windows show them in full, like "Aleste 2 (1988).rom". MSX-DOS and SofaRun see the 8+3 short name Windows generates, like `ALESTE~1.ROM`.
- **The MSXimus menu** walks every partition with TAB and launches ROM and DSK files without going through MSX-DOS.
- **Do not format the partitions from Windows.** Windows would change their format or cluster size. To start over, run the card through MSX SD Maker again.
- **Do not delete `FHUNT` or `TMP`** from partition 1.

---

## 7. Saving an image instead of a card

**Guardar como imagen…** (*save as image*) creates an `.img` file with the whole card instead of writing it. Useful to:

- Prepare several identical cards: write the image with Rufus, balenaEtcher or Win32 Disk Imager.
- Try it in an emulator.
- Keep a copy of a setup.

The program asks for the image size. An image can be written to a card of that size **or larger**, never smaller, and cards hold a little less than their label says: `1800M` fits any 2 GB card and `3500M` any 4 GB card. The image only takes up on the PC's disk what was really written, not its whole size.

Every MSXimus release also ships a ready-made image with Nextor 3 (1800 MB, all programs): just write it.

---

## 8. Troubleshooting

**The card is not in the list.**
Check it is properly inserted and press **Actualizar**. Only SD readers and removable USB sticks are listed. Some USB-SATA or USB-NVMe adapters present themselves as fixed disks and are left out on purpose.

**"La unidad E: está en uso: cierra lo que la tenga abierta"** (*drive E: is in use: close whatever has it open*).
Close the Explorer windows showing the card and any program with files open on it. Try again.

**The program says it needs administrator rights.**
Open it by double-clicking and answer **Yes** in the Windows prompt.

**The MSX never reaches MSX-DOS.**
- Does the system you chose match your machine's BIOS pack or `BOOT` file? See the table in [step 3.3](#33-the-system).
- Did you choose FAT32? MSX-DOS cannot read it.
- Is "Menú al arrancar" on? Then the menu comes first: press **ESC**.

**C: and D: do not appear in MSX-DOS.**
With "MSX-DOS básico" the Nextor tools are not copied, so the `AUTOEXEC` cannot mount them. Do it from BASIC with `CALL MAPDRV`, or prepare the card again with Nextor.

**"ERROR … opening UDP connection" at boot.**
That is `SNTP` trying to set the clock from the internet with no network. It does not affect anything. If it bothers you, delete that line from `AUTOEXEC.BAT`.

**The verification found errors.**
The card or the reader may be failing. Try again and, if it happens again, with another reader or another card.

**Can I have more than 8 partitions?**
No. The MSXimus menu sees 8, and Nextor only looks at the first 9 at boot.

**Windows says the card is smaller than its label.**
That is normal: manufacturers count 1 GB as 1,000 million bytes and Windows as 1,073 million.

**Does it touch anything on my PC?**
No. It only writes to the card you choose, and the Windows disk never appears in the list.

---

## 9. For the curious: how it works

- **It splits the card the same way as Nextor's `FDISK`**, the tool you open with `CALL FDISK`. Partition 1 is primary, active and starts at sector 1. The rest are logical partitions inside an extended one. That way Nextor numbers them 1, 2, 3… and `MAPDRV` finds them.
- **FAT16 uses the geometry of Nextor's `FDISK`**: clusters from 2 to 64 KB depending on the size, at most 65,524 clusters and 512 root entries.
- **FAT32** starts at sector 8192, with the data aligned to 4 MB, as the SD Association formatter does.
- **Names**: it stores the 8+3 short name MSX-DOS reads and, when needed, also the long name Windows and the menu show.
- **The partition table is written last**, once everything else is in place. Then everything is read back and every file is compared by its CRC32.

The source code and the card contents are in [SD_Maker](https://github.com/Papipapito/SD_Maker); the machines' repositories carry a copy of the program in [`fuente/`](fuente/) (Python 3 with tkinter; `construir_exe.bat` builds the `.exe` with PyInstaller). To run it without the `.exe` you need the card contents in an `sd/` folder next to `MSXsdmaker.py`, with `base/`, `nextor-2.1.4/`, `nextor-3.0.0-beta2/` and `extras/`. The `.exe` already carries them. From the command line it can also make images:

```
python MSXsdmaker.py imagen test.img --tamano 8G --esquema fat16-2g --n 3 --sistema nextor214 --programas todos
```

---

## 10. Licenses and credits

MSX SD Maker is part of the MSXimus / MSXnano project, by Albert (Papipapito), under GPL v3 like the rest of the project.

The programs it copies to the card belong to their authors: Nextor and MSX-DOS, SofaRun, Multi Mente, the UNAPI tools, HUB and more. See [LICENCIAS.md](LICENCIAS.md): it has the list and the Nextor license notice, which must accompany its files.

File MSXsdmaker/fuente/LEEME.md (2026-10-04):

# SD_Maker — tarjetas SD para los MSX en FPGA

*[English](README.md)*

**MSX SD Maker** prepara tarjetas SD para los MSX en FPGA, **MSXimus** (60K, 138K, Zynq), **MSXnano** y **Goa'uld**, y también para la **MSX Pico**: las particiona, las formatea, copia el sistema y deja una estructura de programas con su `AUTOEXEC.BAT`.

## Uso

Se reparte en un ZIP (`MSX_SD_Maker_<versión>.zip`, en las [releases](https://github.com/Papipapito/SD_Maker/releases/latest)): descomprimir y ejecutar `MSXsdmaker.exe`. Pide permisos de administrador (hacen falta para escribir la tarjeta entera).

1. **Tarjeta**: solo aparecen lectores SD/MMC y memorias USB extraíbles, nunca el disco de Windows. Se ve el tamaño y las particiones que tiene ahora.
2. **Particiones**:
   - FAT16 de 2 GB o de 4 GB, tantas como quepan (hasta 8, las que ve el menú del MSXimus). Opcionalmente, una última con lo que sobre.
   - O una FAT32 con toda la tarjeta. Nextor 2.1.4 y 3.0 no leen FAT32: sirve para el menú del MSXimus (ROM y DSK) y la MSX Pico, no para arrancar MSX-DOS.
3. **Sistema** en la partición 1: Nextor 2.1.4, Nextor 3.0 beta 2, MSX-DOS básico (`MSXDOS2.SYS` + `COMMAND2.COM`, y los de MSX-DOS 1) o ninguno.
4. **Programas**: SofaRun, Multi Mente, UTIL, WiFi/UNAPI, fuentes, música, HUB, IA, mapper e indev, y las herramientas FPGA (`FPGA\MXUPDATE.COM`, que actualiza el core del MSXimus 60K/138K y del MSXnano). Se crean también `FHUNT` y `TMP` (el menú no puede crear carpetas) y `SAVES` y `SETTINGS` de SofaRun.

El `AUTOEXEC.BAT` se genera con lo elegido: `PATH`, alias de SofaRun y una línea `mapdrv c: 2 1 0` por cada partición de más (C:, D:, E:...). Con Nextor 3 (1.1) lleva además las opciones del recuadro: `YENSLASH ON` (la orden interna de COMMAND3.COM desde la beta 2; el `yenslash` a secas solo diría el estado), `SET BUFINSERT=ON`, `SET DIRK=0` y, si se elige, se llama `AUTOEXEC.BTM`. Desde la 1.1, una tarjeta más pequeña que una partición entera (las de "2 GB") lleva una sola con todo, y la imagen pregunta siempre el tamaño (1800M por defecto: cabe en cualquier tarjeta de 2 GB).

Al acabar se relee todo lo escrito: la tabla de particiones y cada fichero por CRC.

Al abrirse mira en GitHub la última release de SD_Maker (`sdmaker/novedades.py`); si es mayor que la suya, lo dice y ofrece abrir la página de descarga. `python MSXsdmaker.py version` enseña las dos.

🚨 La primera vez, pruébalo con una tarjeta que no tenga nada que importe: borra la tarjeta entera.

## Cómo reparte la tarjeta

Igual que el `FDISK` de Nextor (`kernel/bank5/fdisk2.c`): partición 1 primaria, activa y en el sector 1; las demás lógicas dentro de una extendida, cada una con su EBR. Geometría FAT16 idéntica a la suya (cluster de 2 a 64 KB, como mucho 65.524 clusters, 512 entradas de raíz). La FAT32 empieza en el sector 8192 con los datos alineados a 4 MB.

## Contenido

Sale de `sd/` y va dentro del `.exe`: `base/`, `nextor-2.1.4/`, `nextor-3.0.0-beta2/` y `extras/` (SOFARUN, hub, mapper, IA e indev de la SD de la MSX Pico, y FPGA con MXUPDATE.COM); [`sd/LEEME.md`](sd/LEEME.md) explica cada carpeta. Para cambiar lo que se copia, se cambian esas carpetas y se vuelve a construir.

Casi todo lo de `sd/` es de terceros (Nextor, MSX-DOS, SofaRun, Multi Mente, las herramientas UNAPI...) y va bajo la responsabilidad del autor de este proyecto: autores y licencias en [`paquete/LICENCIAS.md`](paquete/LICENCIAS.md), con la licencia de Nextor. El programa es GPL v3 ([`LICENSE`](LICENSE)).

## Construir y probar

```bat
construir_exe.bat
```

Hace `dist\MSXsdmaker.exe` con PyInstaller. `python hacer_zip.py` hace el ZIP de la release (`dist\MSX_SD_Maker_<versión>.zip`: el `.exe` con LEEME, README, LICENCIAS y las capturas).

Línea de órdenes (con Python), útil para probar con imágenes:

```bash
python MSXsdmaker.py imagen prueba.img --tamano 8G --esquema fat16-2g --n 3 --sistema nextor214 --programas todos
```

Pruebas en WSL con herramientas ajenas al programa (`sfdisk`, `fsck.fat`, `mtools`):

```bash
bash pruebas/probar_imagenes.sh
```

Nueve casos: 3×200 MB, 2×2 GB con sobrante y Nextor 3, 2×4 GB con sobrante, FAT32 de 16 GB, MSX-DOS, vacía, 8 particiones, las opciones de Nextor 3 y una imagen de 1800 MB. En cada uno, la partición 1 se extrae y se compara con un árbol hecho con `cp`.

## Paquete para los repos de las máquinas

```bash
python publicar_paquete.py ../MSXimus_zynq ../MSXimus
```

Copia a la carpeta `MSXsdmaker/` de cada repo el `.exe` (antes, `construir_exe.bat`), las instrucciones, `LICENCIAS.md` y las capturas de `paquete/`, y el código en `fuente/`. No hace commit.

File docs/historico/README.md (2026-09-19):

# Histórico: expedientes, diseños y código retirado

Documentos y directorios que **no describen la v2.0** pero explican cómo se llegó a ella.
Se dejan donde están (muchos los referencian commits y scripts); esto es el índice.

## Expedientes de cazas de bugs

| Documento | Qué cuenta |
|---|---|
| [`fpga/tools/hsync_int_sim/README.md`](../../fpga/tools/hsync_int_sim/README.md) | La interrupción de línea del VDP que se dispara dos veces: diagnóstico, testbench, parche y por qué está aparcado. Commit `633e58e` |
| [`tools/scctest/opcheck/BUG22_MG2_bladeba.md`](../../tools/scctest/opcheck/BUG22_MG2_bladeba.md) | Nota de traspaso de la caza del bug #22 (Metal Gear 2 glitcheando en partida), con lo aprendido del repo de bladeba. Resuelto en la v1.8 (R#13 del menú) |
| [`fpga/AUDIT_PRE_PORT_60K.md`](../../fpga/AUDIT_PRE_PORT_60K.md) | Auditoría del core antes de portarlo a la Tang Console 60K (base v1.8/v1.9): código muerto heredado, 6 bugs latentes en rutas de error, y los cuatro frentes del port (SDRAM → DDR3, relojes, constraints, companion). Es el punto de partida del MSXimus |

## Diseños no implementados en el nano

| Documento | Qué es |
|---|---|
| [`fpga/GRAPHICAL_FRONTEND_DESIGN.md`](../../fpga/GRAPHICAL_FRONTEND_DESIGN.md) | Frontend gráfico de carátulas estilo EmuELEC, dibujado por el MCU y compuesto en la FPGA. Investigado en julio de 2026; pensado para el 60K. `tools/frontend_demo/sample_sd/` tiene el `INDEX.DAT` + `COVERS.PAK` de muestra |
| [`fpga/src/msxnano_menu/LEEME.md`](../../fpga/src/msxnano_menu/LEEME.md) | Por qué el fuente del menú ya no vive en este repo (está en `bios-msxnano-msximus`) y por qué queda un `.bin` |

## Código en el árbol que no compila en la v2.0

| Directorio | Qué era | Estado |
|---|---|---|
| [`fpga/bl616/`](../../fpga/bl616/README.md) | Firmware FPGA-Companion del BL616 (teclado/mando por SPI) y sus `.ini` de flasheo, con la guía del M0S Dock externo | Retirado en la v2.0 (RP2040). Se conserva para quien tenga una placa anterior a la `3921` y quiera la v1.9 |
| `fpga/src/usb/` | El lado FPGA del BL616: `fpga_companion.v`, `hid.v`, `mcu_spi_new.v`, `sys_ctrl.v`, `usb_keyboard_msx.vhd` | Fuera de `build.tcl` desde `8ce5b74` |
| `fpga/msx_debug/timing_debug.v` | Diagnóstico de tiempos del goauld original | Fuera de producción (costaba 3 % de CLS) |
| `fpga/pulse_min_max/` | Utilidades de medida de pulsos del goauld | Sin usar |
| `fpga/src/rom/` | `build.bat` y los rellenos `*_ff.bin` para montar el pack a la antigua | Sustituido por `hacer_packs.py` del repo de BIOS; sigue valiendo si tienes las 10 ROMs |
| `tools/megaram_equiv/megaram_v16.v`, `megaram_v17.v` | Versiones históricas de la Megaram | Referencia para comparar |

## Releases y ficheros entregados

- `files/<fecha>/` guarda cada pareja `.fs` + `.bin` entregada, con el dado en el nombre
  o en el commit. La v2.0 es `files/20260904/msxnano_20260904_48_v20_sinCinta.*`.
- `bin/` lleva el `.fs` y el pack de la release vigente.
- Las notas de cada versión: [`tecnica/08-changelog.md`](../tecnica/08-changelog.md) y
  [GitHub → Releases](https://github.com/Papipapito/MSXnano/releases).

## Ramas y repos que ya no están

`MSXNano_SCC`, `MSXNano_Menu`, `Menu`, `dev`, `MSXnano-cinta` y `_MSXnano_dev_ref` se
fusionaron o se eliminaron; **`main` es la única rama**. Los repos `ESP32-UNAPI-MSX` y el
fork `ESP32-UNAPI-Firmware` se retiraron: el firmware del ESP vive en
[`ESP32-for-FPGA`](https://github.com/Papipapito/ESP32-for-FPGA). Todo lo borrado sigue en
el respaldo privado `MSXnano-backup`.

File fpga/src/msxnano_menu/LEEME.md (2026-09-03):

# El fuente del menú ya NO vive aquí

El **repositorio oficial de las BIOS de las dos máquinas** (MSXnano y MSXimus)
es **`bios-msxnano-msximus`**. Allí está el fuente único (`src/menu_main.asm`),
que genera las cuatro variantes con las banderas `MSXIMUS` / `BIOS_MENU` /
`BIOS_ESP32` / `BIOS_FH`, y allí se montan los packs con `tools/hacer_packs.py`.

Lo que había en esta carpeta era una **copia bifurcada y obsoleta** (8.504 líneas
frente a 9.393): le faltaban `sd_cmd_go` (la carrera del strobe de la SD),
`INIT_VEC`/`MIR16` (el lanzamiento de ROMs planas) y la verificación CRC32 de las
descargas. Se eliminó el 02/09/2026 para que no hubiera dos menús con el mismo
nombre y distinto contenido.

Los documentos de diseño que estaban aquí se movieron a `bios-msxnano-msximus/docs/`:
`LAUNCH_SCREEN_DESIGN.md`, `M2_DESIGN.md` y `SRAM_PERSIST_CONSOLE60K_DESIGN.md`.

## Por qué queda un .bin

`fpga/src/rom/build.bat` concatena `..\msxnano_menu\fm_logo_menu.bin` para armar
el pack. **Ese binario lo genera el repo de BIOS**; aquí solo está la copia que
consume el build. Para regenerarlo:

```bash
cd ../../../../bios-msxnano-msximus && ./build.sh
# y copiar out/bios-Menu_msxnano.bin sobre fm_logo_menu.bin
```

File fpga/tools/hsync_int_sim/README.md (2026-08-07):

# Interrupción de línea del VDP: se dispara DOS veces por línea

**Estado: bug CONFIRMADO, arreglo ESCRITO Y VERIFICADO en simulación, pero
APARCADO porque hoy no cabe en el chip.** Ver "Por qué está aparcado".

## El bug

`vdp.vhd` genera la ventana de disparo de la interrupción de línea con **dos**
comparaciones:

```vhdl
IF( PREDOTCOUNTER_X = 255+25 OR PREDOTCOUNTER_X = "111111111" )THEN
    ACTIVE_LINE <= '1';
```

Y las dos pertenecen a la **misma línea**. El motivo está en `vdp_ssg.vhd`:

```vhdl
-- vdp_ssg.vhd:399 — el avance de linea cae en el MISMO valor 511
W_HSYNC <= '1' WHEN( W_H_CNT(1 DOWNTO 0) = "10" AND FF_PRE_X_CNT = "111111111" )
-- vdp_ssg.vhd:454 — y el contador Y va un ciclo por detras
FF_PRE_Y_CNT <= FF_MONITOR_LINE + ("0" & REG_R23_VSTART_LINE);
```

O sea: cuando el contador X vale 511 —que es justo el instante en que avanza la
línea— el contador Y **todavía tiene el número de la línea anterior**. Así que
`Y_CNT = R#19` se cumple dos veces para la misma línea, separadas por decenas de
microsegundos.

Como el borrado del flag (leer S#1) es un **pulso**, si la ISR hace el ack entre
las dos ventanas, la segunda **vuelve a pedir interrupción** y la rutina se
ejecuta **dos veces en la misma línea**.
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

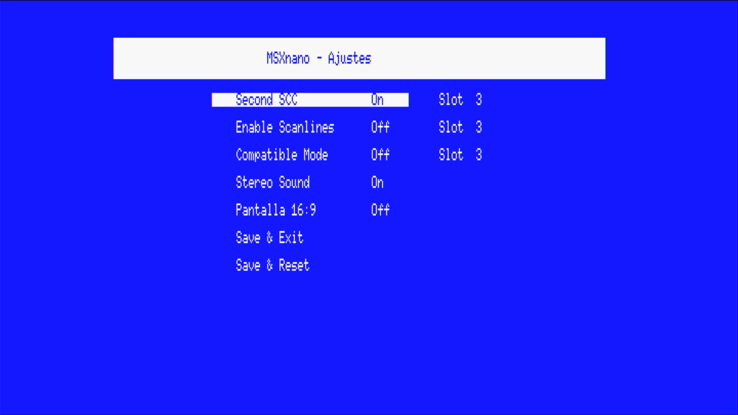
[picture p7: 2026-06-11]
pics/menu_settings.png

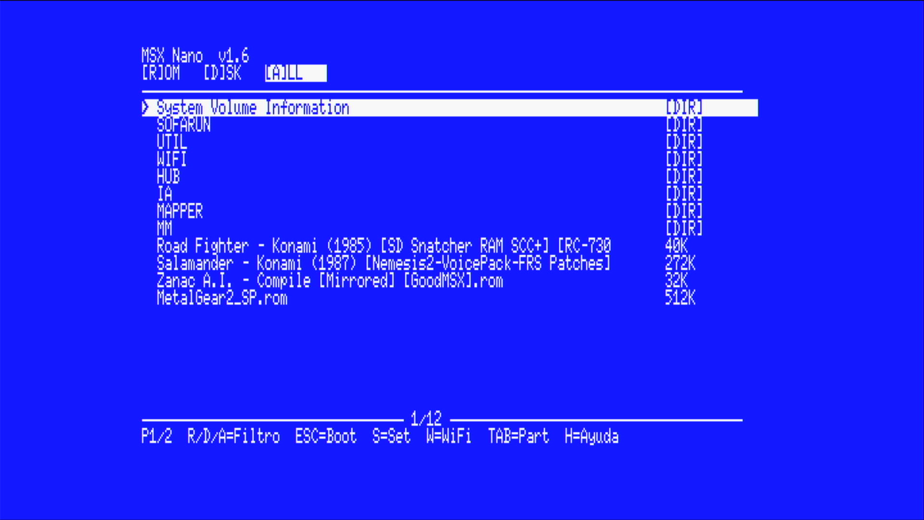
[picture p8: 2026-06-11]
pics/menu_browser.png

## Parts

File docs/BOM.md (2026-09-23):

# Bill of Materials (BOM) — v2.0

Everything you need to build a **MSXnano** (standalone MSX2+ on the Tang Nano 20K).
Items marked _(optional)_ are not required to boot; they add the feature noted.

Spreadsheet version: [`MSXnano_BOM.xlsx`](MSXnano_BOM.xlsx).

## Core

| # | Qty | Component | Notes |
|---|-----|---|---|
| 1 | 1 | **Sipeed Tang Nano 20K** (GW2AR-18) | The main board. Any revision works: since v2.0 the onboard BL616 is **not used**, so boards marked `3921` (locked BL616) are fine. |
| 2 | 1 | **microSD card**, FAT32 | 2–32 GB is simplest. Larger cards must be formatted FAT32 by hand. |
| 3 | 1 | **USB-C cable** | Power + programming (Gowin Programmer). |
| 4 | 1 | **HDMI cable** | Video and audio out. There is no analog audio. |

## Keyboard, joystick and mouse (required for a keyboard)

| # | Qty | Component | Notes |
|---|-----|---|---|
| 5 | 1 | **RP2040 board** | Waveshare **RP2040-Zero** (recommended, `rp2040_keyboard_zero.uf2` in the release) or a plain **Raspberry Pi Pico** (`rp2040_keyboard_pico.uf2`). |
| 6 | 3 | **Jumper wires** | Pico GP15 → Tang **pin 31**, GND → GND, VBUS → 5V. |
| 7 | 1 | **USB keyboard** | Plugged into the Pico's USB port. Plain keyboards work best (avoid ones with a built-in hub). |
| 8 | 1 | **USB hub** _(optional)_ | To use keyboard **and** gamepad/mouse at once. A **self-powered** hub is recommended. |
| 9 | 1 | **USB gamepad** _(optional)_ | DirectInput (HID) or XInput. Buttons 3/4 = autofire. |
| 10 | 1 | **USB mouse** _(optional)_ | Becomes a real MSX mouse on joystick port 2. |

## WiFi _(optional — MSX UNAPI, File-Hunter)_

Pick **one** of the two. Both use the same UART on pins 27/28.

| # | Qty | Component | Notes |
|---|-----|---|---|
| 11a | 1 | **ESP-01S** (ESP8266) | RX → Tang **pin 27**, TX → **pin 28**, VCC → 3.3V, GND → GND. Firmware: ducasp ESP8266-UNAPI at 859372 baud. WiFi only. |
| 11b | 1 | **Waveshare ESP32-C6-LCD-1.3** | GPIO17 → pin 27, GPIO16 → pin 28, GPIO3 → **pin 29** (turbo LED), GND → GND. Powered by its own USB-C. Adds a 240×240 status screen. Firmware: [ESP32-for-FPGA](https://github.com/Papipapito/ESP32-for-FPGA). |
| 12 | — | Jumper wires / header | 4 wires for either module. |

## Enclosure _(optional)_

| # | Qty | Component | Notes |
|---|-----|---|---|
| 13 | 1 set | **3D-printed case**, white PETG recommended | STL files in [`../case/`](../case). Print everything at once with `msxnano_case_bambulab.3mf`. Two top-left variants: with a window for the ESP32-C6 screen, or without. |
| 14 | — | **M2/M3 screws and standoffs** | See the spreadsheet and [`../case/README.md`](../case/README.md). |

## Notes

- **No soldering** is needed: the RP2040 and the ESP connect with jumper wires to the
  Tang Nano 20K header. All signals are 3.3 V, direct connection.
- Pins used on the Tang Nano 20K: **27, 28** (WiFi UART), **29** (turbo status, C6 only),
  **31** (keyboard link). All in the free 26–32 area.
- Flashing (bitstream + BIOS pack + RP2040 + ESP) is in the [main README](../README.md)
  and, in Spanish and in detail, in [`manual/02-instalacion.md`](manual/02-instalacion.md).

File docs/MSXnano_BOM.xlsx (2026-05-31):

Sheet: Piezas 3D (case)
MSXnano — Piezas de la carcasa (impresión 3D)
🖨 Imprime todo con case/msxnano_case_bambulab.3mf (proyecto Bambu Lab). Material recomendado: PETG BLANCO.
# | Pieza | Fichero | Cantidad | Link (descarga/origen) | Notas
1 | Superior izquierda | upper_left.stl | 1
2 | Superior derecha | upper_right.stl | 1
3 | Inferior izquierda | lower_left.stl | 1
4 | Inferior derecha | lower_right.stl | 1
5 | Lateral inferior | lower_side.stl | 1 |  | TN20K case v4
6 | Soporte teclado A | keyboard_support_a.stl | 1
7 | Soporte teclado B | keyboard_support_b.stl | 1
8 | Soporte de placa | raspberry_support.stl | 1
9 | Pilar 1 | pillar1.stl | 2 |  | imprimir ×2
10 | Pilar 2 | pillar2.stl | 2 |  | imprimir ×2
11 | Proyecto Bambu Lab (todo) | msxnano_case_bambulab.3mf | 1 |  | abre en Bambu Studio e imprime todo de una

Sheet: Componentes
MSXnano — Lista de componentes (BOM)
# | Componente | Cantidad | Link (compra)
Núcleo
1 | Sipeed Tang Nano 20K (FPGA GW2AR-18) | 1 | https://es.aliexpress.com/item/1005005581148230.html
2 | Conector Hembra MicroSD a Micro SD 15cm | 1 | https://es.aliexpress.com/item/1005004124859525.html?scm_id=1007.22922.271278.0&scm-url=1007.22922.271278.0
3 | Cable USB-C internos 20cm | 3 | https://es.aliexpress.com/item/1005006806265814.html?scm_id=1007.23125.137358.0&scm-url=1007.23125.137358.0
4 | Conector Hembra USB-C | 1 | https://es.aliexpress.com/item/1005003355262263.html
5 | Conector HDMI Hembra |  | https://es.aliexpress.com/item/1005001975924049.html
6 | Conector Hembra HDMI 15cm | 1 | https://es.aliexpress.com/item/1005009220802088.html
7 | Teclado USB (USB-A) | 1 | Ajazz AK33
8 | Hub USB | 1 | https://es.aliexpress.com/item/1005009094671557.html
WiFi (opcional)
9 | Módulo ESP-01S (ESP8266) | 1 | https://es.aliexpress.com/item/1005007199950424.html?curPageLogUid=fEYHOSyp5NIc

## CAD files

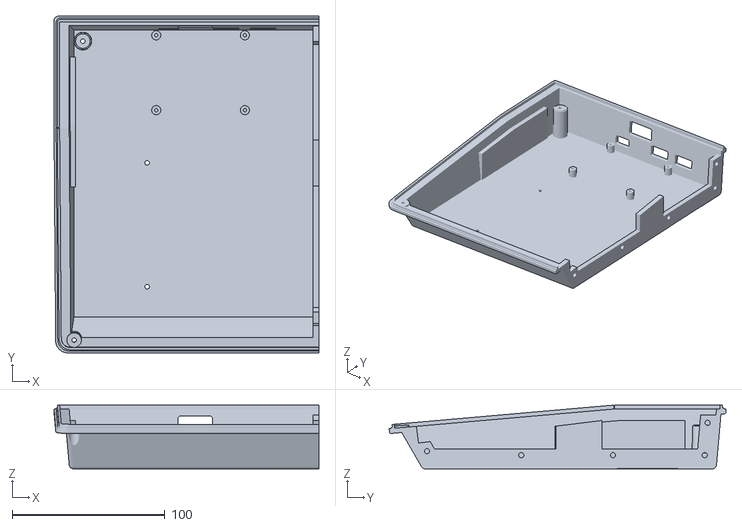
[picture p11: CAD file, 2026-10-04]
case/lower_left.stl
173.4 x 220.4 x 41.8

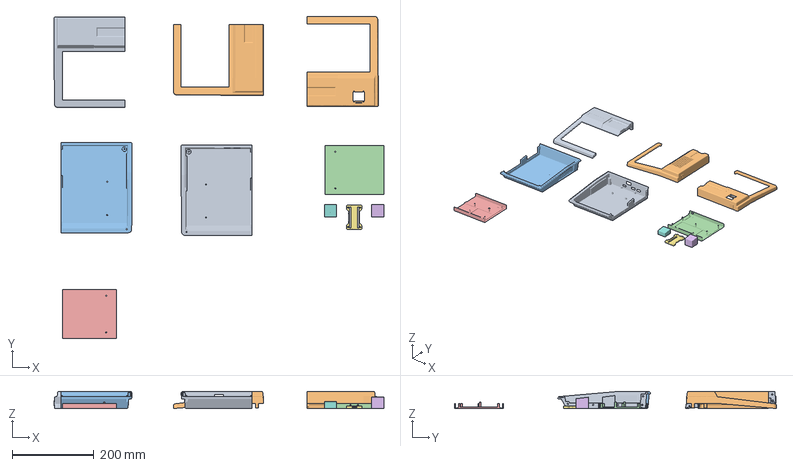
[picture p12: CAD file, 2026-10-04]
case/msxnano_case_bambulab.3mf
805.1 x 786.5 x 41.9 mm
Upper_Left.stl.stl
Upper_Right.stl.stl
Lower_Right.stl.stl
Keyboard_Support.stl_B.stl
Keyboard_Support.stl_A.stl
Pillar1_x2.stl.stl
tn20k_case_v4-lower_side.stl
Pillar2_x2.stl.stl
Lower left.stl
Upper_Left_esp32.stl

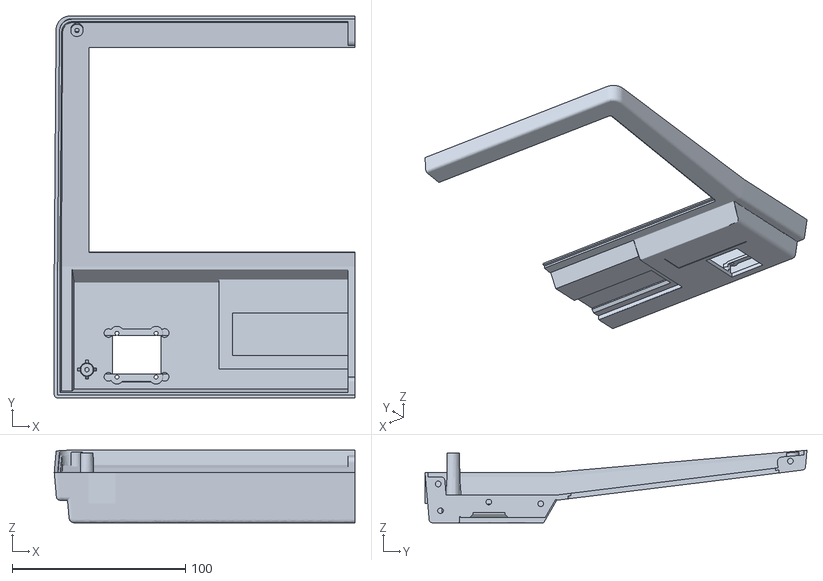
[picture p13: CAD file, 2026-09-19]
case/Upper_Left_esp32.stl
173.4 x 220.4 x 41.9

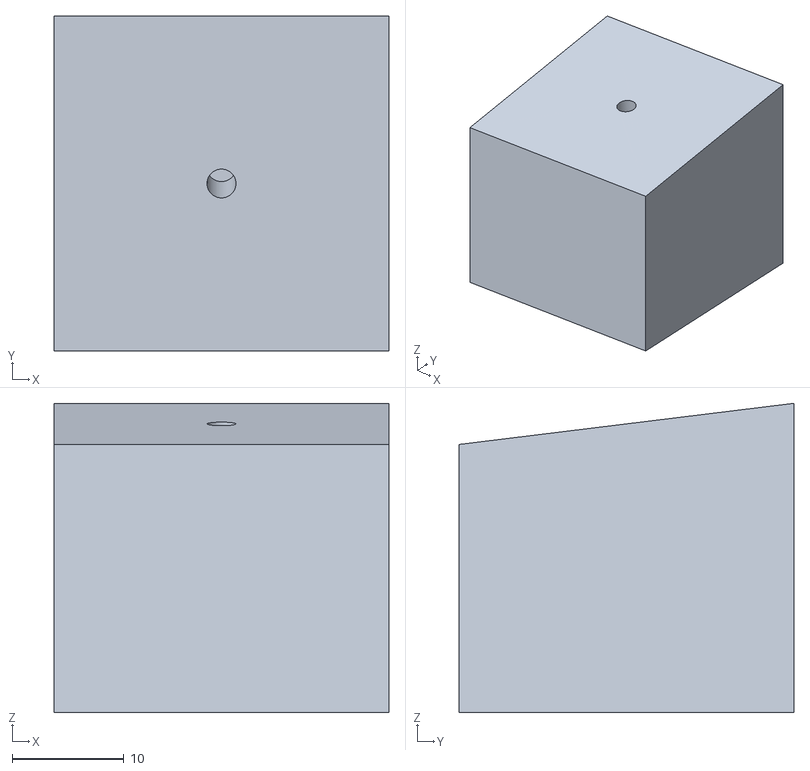
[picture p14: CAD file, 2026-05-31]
case/pillar1.stl
30.0 x 30.0 x 27.7

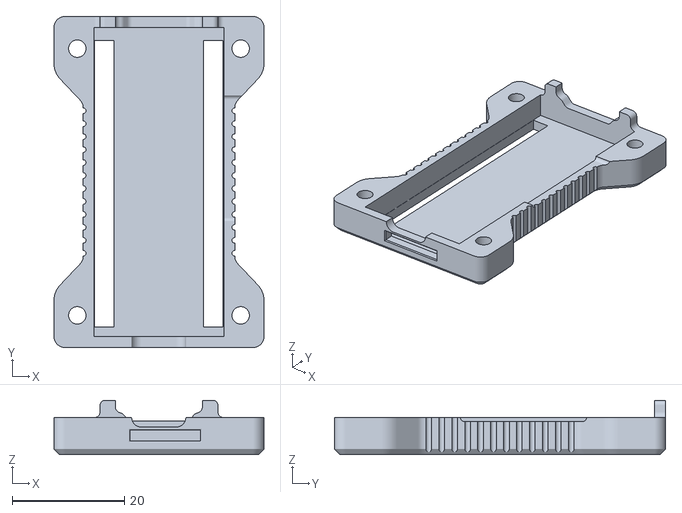
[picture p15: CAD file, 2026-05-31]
case/lower_side.stl
37.4 x 59.0 x 9.67

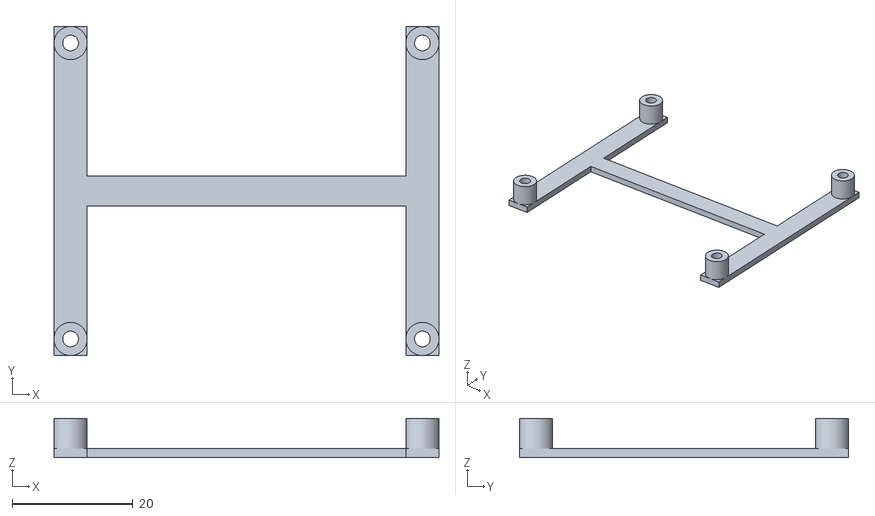
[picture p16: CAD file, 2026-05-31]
case/raspberry_support.stl
63.8 x 54.5 x 6.50

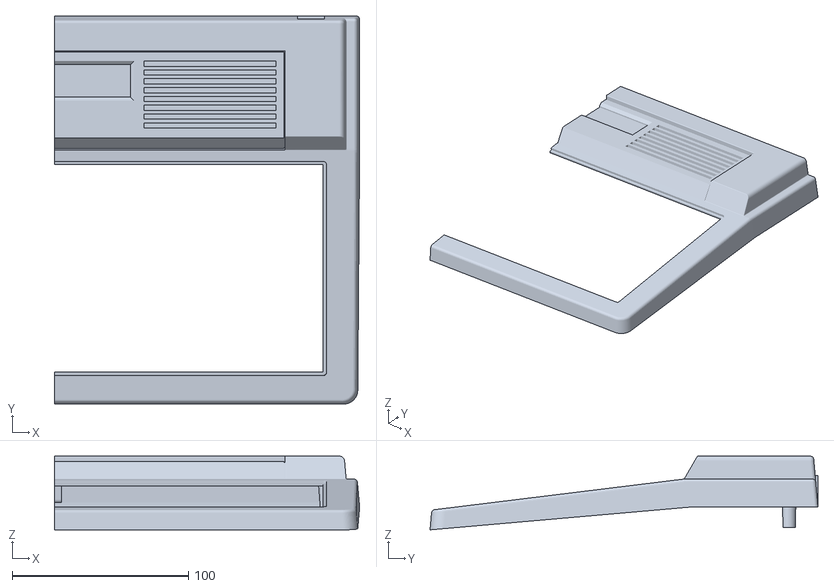
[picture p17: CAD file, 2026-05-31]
case/upper_right.stl
173.4 x 220.4 x 41.9

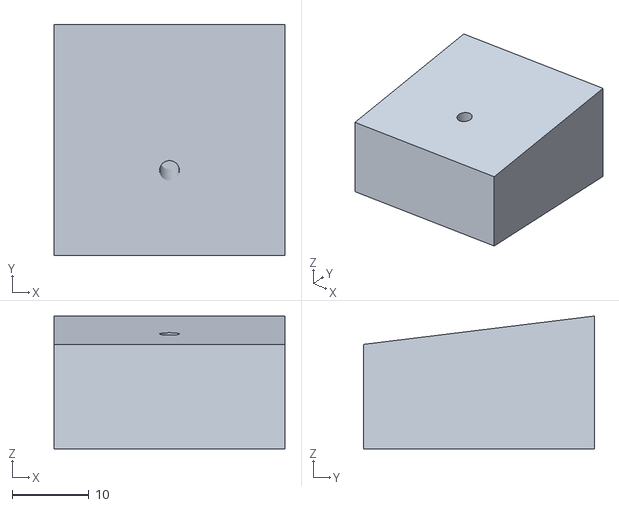
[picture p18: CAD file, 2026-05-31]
case/pillar2.stl
30.0 x 30.0 x 17.3

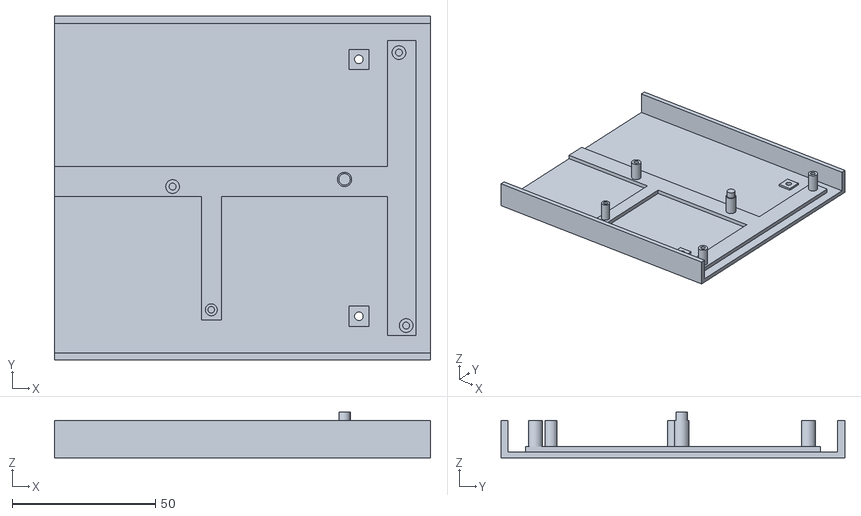
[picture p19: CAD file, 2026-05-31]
case/keyboard_support_a.stl
131.2 x 120.0 x 16.0

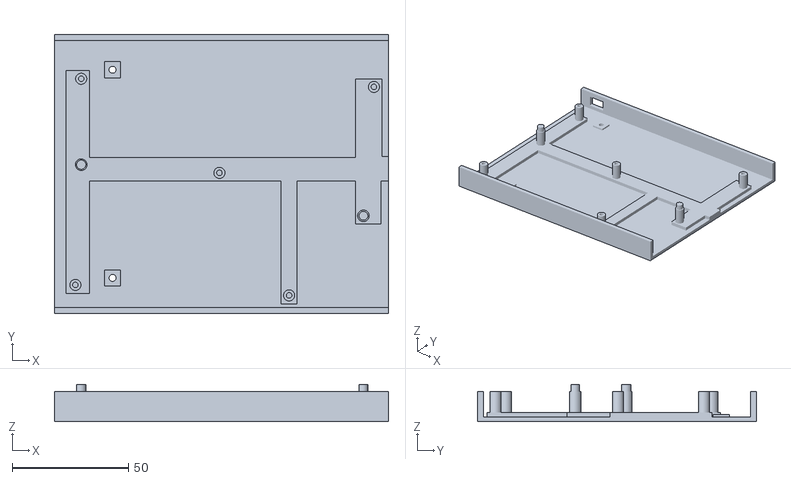
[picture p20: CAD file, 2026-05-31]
case/keyboard_support_b.stl
143.8 x 120.0 x 16.0

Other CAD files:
case/prototipo/lower_left_prototipo.stl
case/lower_right.stl
case/upper_left_sin_pantalla.stl

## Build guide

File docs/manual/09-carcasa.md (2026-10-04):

# 09. La carcasa

Una caja impresa en 3D, en dos mitades (superior e inferior) partidas a su vez en
izquierda y derecha para caber en cualquier impresora de sobremesa. Está en
[`case/`](../../case/). Parte de
[este diseño de Thingiverse](https://www.thingiverse.com/thing:4066021), rediseñado para
el MSXnano.

## Imprimir

Lo más cómodo: abrir **`msxnano_case_bambulab.3mf`** en **Bambu Studio**. Trae todas las
piezas colocadas y orientadas para imprimirlas de una vez.

Si tu impresora no es Bambu, los **STL** están sueltos. Material recomendado: **PETG
blanco**. Sin soportes en la mayoría de piezas; las tapas van boca abajo.

## Las piezas

| Fichero | Pieza | Cantidad |
|---|---|---|
| `Upper_Left_esp32.stl` | Tapa superior izquierda, **con ventana para la pantalla del ESP32-C6** | 1 (elige una) |
| `upper_left_sin_pantalla.stl` | Tapa superior izquierda, **sin ventana** | 1 (elige una) |
| `upper_right.stl` | Tapa superior derecha | 1 |
| `lower_left.stl` | Base izquierda, **preparada para la [placa portadora v2](https://github.com/Papipapito/MSXnano-Boards/tree/main/carrier)**: USB-C, HDMI y 2 × USB-A salen por detrás; 4 separadores para la placa | 1 |
| `prototipo/lower_left_prototipo.stl` | Base izquierda del prototipo anterior (Tang y RP2040 cableados a mano) | — |
| `lower_right.stl` | Base derecha | 1 |
| `lower_side.stl` | Lateral de la base (encaje de la Tang Nano 20K, versión 4) | 1 |
| `keyboard_support_a.stl` | Soporte de teclado A | 1 |
| `keyboard_support_b.stl` | Soporte de teclado B | 1 |
| `raspberry_support.stl` | Soporte de la placa RP2040 (montaje cableado a mano; con la portadora no hace falta) | 1 |
| `pillar1.stl` | Pilar 1 | 2 |
| `pillar2.stl` | Pilar 2 | 2 |
| `msxnano_case_bambulab.3mf` | Proyecto Bambu Lab con todo | — |

### Las dos tapas superiores izquierdas

Son la **única decisión** al imprimir. La tapa izquierda es donde va el módulo WiFi:

- **`Upper_Left_esp32.stl`**: lleva la ventana para la pantalla del **ESP32-C6-LCD-1.3**.
  Imprime esta si vas a montar el C6.
- **`upper_left_sin_pantalla.stl`**: tapa lisa. Para un montaje con ESP-01S, o sin WiFi.

El resto de piezas es igual en los dos casos. Solo se imprime una de las dos.

## Montaje

1. La **Tang Nano 20K** encaja en `lower_side.stl`, que se une a las dos bases. El
   USB-C, la microSD y el HDMI de la placa quedan accesibles por los laterales.
2. La **RP2040** va en `raspberry_support.stl`, con su USB hacia fuera para enchufar el
   teclado (o el hub).
3. Los **pilares** unen la base con la tapa y fijan la altura.
4. Si montas el **ESP32-C6**, va detrás de la ventana de `Upper_Left_esp32.stl`, con su
   USB-C accesible para alimentarlo.
5. Los tres cables de la Pico y los cuatro del ESP van por dentro al header de la Tang:
   ver [02. Instalación](02-instalacion.md).

Tornillería y detalles de medidas en la [lista de materiales](../BOM.md) y en la hoja
[`MSXnano_BOM.xlsx`](../MSXnano_BOM.xlsx).

### Base izquierda para la placa portadora (09/2026)

`lower_left.stl` es la pieza original de Thingiverse con la ventana trasera tapada y cuatro
aberturas nuevas para el borde trasero de la portadora (USB-C de alimentación, HDMI, USB-A
del teclado y USB-A del mando), más cuatro separadores impresos en el suelo con el patrón de
la Raspberry Pi 3 (Ø 6 mm, 6,5 mm de alto, agujero ciego de Ø 2,2 mm). La placa apoya en
ellos a 10,5 mm del suelo con el borde trasero contra la pared; se fija con 4 tornillos
M2,5 × 6–8 desde arriba (hacen rosca en el plástico; si prefieres insertos roscados, abre los
agujeros a Ø 3,2 mm). `raspberry_support.stl` no hace falta con la portadora. La tapa y el
resto de piezas no cambian.

## Créditos

Diseño base: [Spectravideo SVI-728 Retropie case](https://www.thingiverse.com/thing:4066021),
de Palver (CC BY-NC), que sirvió de punto de partida. Las modificaciones para el MSXnano
(soportes, la ventana de la pantalla, el lateral v4 de la Tang, la base para la portadora)
son del proyecto.

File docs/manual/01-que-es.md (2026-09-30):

# 01. Qué es el MSXnano

Un **MSX2+ completo dentro de una FPGA**, en la placa Sipeed Tang Nano 20K. No necesita
un MSX: **es** un MSX. Se conecta a un televisor por HDMI, se le enchufa un teclado USB y
arranca en MSX-DOS o en un menú desde el que se lanzan juegos y discos guardados en una
tarjeta microSD.

Es la línea de core que empezó jabadiagm con el
[MSXgoauldSD_tn20k](https://github.com/jabadiagm/MSXgoauldSD_tn20k) —un Tang Nano 20K
enchufado al zócalo del Z80 de un MSX real— convertida en una máquina **autónoma**: sin
placa MSX debajo, con todo el hardware del sistema dentro del chip. Su hermano mayor es el
[MSXimus](https://github.com/Papipapito/MSXimus), en la Tang Console 60K, que hereda este
core y lo amplía con lo que aquí no cabe.

## Lo que trae

| | |
|---|---|
| **CPU** | Z80 a 3,58 MHz con la temporización de un MSX real (un estado de espera por cada ciclo M1), y **turbo a 5,369318 MHz exactos** con el protocolo Panasonic WSX |
| **Vídeo** | **V9958** (el VDP del MSX2+, con SCREEN 10-12 y scroll horizontal) con salida **HDMI**; scanlines opcionales |
| **Audio** | PSG, **OPLL** (MSX-MUSIC) y **dos SCC+**, mezclados en **estéreo** por el HDMI |
| **Memoria** | 4 MB de mapper de RAM · **Megaram de 2 MB** con SCC en el slot 2 · reloj de tiempo real |
| **Almacenamiento** | Tarjeta microSD con **Nextor 2.1.4** en el slot 3-2, menú de arranque y navegador de ficheros |
| **Teclado, joystick y ratón** | USB, a través de un **RP2040** (Pico Zero); incluye un **ratón MSX** de verdad a partir de cualquier ratón USB |
| **WiFi** | Opcional: MSX UNAPI con un **ESP-01S**, o un **ESP32-C6** que además pone una pantalla de estado |
| **BIOS** | MSX2+ internacional, con el menú integrado y activable desde Ajustes |

## Lo que hace falta

- Una **Tang Nano 20K**. Cualquier revisión: desde la v2.0 el companion USB es externo,
  así que da igual que la placa traiga el BL616 bloqueado (las marcadas `3921` en adelante).
- Un **RP2040** para el teclado. Por defecto una Waveshare **RP2040-Zero**; vale también
  una Raspberry Pi Pico normal. Tres cables.
- Un **teclado USB**. Y si quieres, un mando y un ratón, por un hub.
- Una **tarjeta microSD** en FAT32.
- Un cable **HDMI** y un televisor o monitor.
- El **pack de BIOS**. Va aparte del core: ver [02. Instalación](02-instalacion.md).
- Opcional: un **ESP-01S** o un **ESP32-C6-LCD-1.3** para WiFi, y la [carcasa](09-carcasa.md).

## Lo que no es

- **No es un emulador.** El Z80, el VDP y los chips de sonido son lógica en la FPGA; el
  software corre sobre ellos ciclo a ciclo. Por eso funciona lo que en un emulador se
  rompe, y también por eso cada función nueva cuesta silicio.
- **No es un turbo R.** Es un MSX2+ con turbo Panasonic: el turbo acelera el Z80, no hay R800.
- **No lleva cartucho físico.** Las ROMs se cargan desde la SD en la Megaram. No hay slot.
- **No es un MSXimus.** Le faltan el V9968, el OPL4, el DMA de la SD y demás cosas que
  necesitan un chip cuatro veces más grande.

## Por qué está cerrado

El core ocupa el **~89 % de las celdas lógicas** del GW2AR-18. En ese régimen, cualquier
cambio —incluso quitar lógica— reordena el emplazamiento y puede tumbar el reloj de la
CPU; se ha comprobado varias veces. El `.fs` de la v2.0 cerraba a 61,7 MHz sobre los 54
necesarios, pero era el mejor de tres emplazamientos: uno de los tres no cerraba. La v2.1,
con el mux de lectura de la CPU en árbol, cierra en todos los emplazamientos probados
(seis de seis) y la entregada va a 62,5 MHz. Ahí se
queda. Lo que se sabe y no se pudo meter está
en [pendientes y aparcado](../tecnica/09-pendientes.md).

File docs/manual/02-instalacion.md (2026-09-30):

# 02. Instalación

Cuatro cosas que grabar, en este orden: el **core** en la flash de la Tang, el **pack de
BIOS** detrás de él, el **firmware del RP2040**, y —solo si lo montas— el del **ESP**. Y
unos pocos cables.

## 1. El core (`.fs`)

Herramienta: **Gowin Programmer** (viene con el
[Gowin EDA](https://www.gowinsemi.com/en/support/download_eda/); basta la edición
Education). **No** uses openFPGALoader: no maneja bien la flash externa de esta placa.

| Qué | Fichero | Dirección | Modo del Programmer |
|---|---|---|---|
| Core | `msxnano_v2.1.fs` (de la [release](https://github.com/Papipapito/MSXnano/releases/tag/v2.1)) | `0x000000` | *External Flash Mode* |

Al terminar, la placa reinicia sola con el core cargado. Sin pack todavía no arranca nada
útil: falta la BIOS.

## 2. El pack de BIOS

El pack es un fichero de **512 KB** que concatena la BIOS MSX2+, la sub-ROM, Nextor, la
ROM de kanji, la ROM WiFi, el logo, el menú y el bloque de configuración. La FPGA lo lee
de la flash por streaming al arrancar.

| Qué | Fichero | Dirección | Modo del Programmer |
|---|---|---|---|
| Pack | `pack_bios_msxnano.bin` | `0x200000` | *exFlash C Bin Erase, Program thru GAO-Bridge* |

Hay dos packs en la release: **`pack_bios_msxnano.bin`** (Nextor 2.1.4, el recomendado) y
`pack_bios_msxnano_nextor3.bin` (Nextor 3 beta). Ver [03. La tarjeta SD](03-tarjeta-sd.md)
para las diferencias.

> Los packs llevan ROMs de sistema con derechos de autor de sus dueños; van en la release
> por decisión del autor. Las herramientas que los montan (`tools/hacer_packs.py`) viven en
> su repositorio de BIOS, `bios-msxnano-msximus`, que es **privado**. La anatomía completa
> está en [tecnica/04-pack-bios.md](../tecnica/04-pack-bios.md).

## 3. El RP2040 (teclado, joystick y ratón)

Sin él no hay teclado. Es un **RP2040** con firmware propio que hace de host USB y le
cuenta al FPGA qué teclas hay pulsadas por **un solo hilo**.

**Firmware** (en [`fpga/rp2040/`](../../fpga/rp2040/), fuente incluido):

| Placa | Fichero en el repo | Fichero en la release |
|---|---|---|
| Waveshare **RP2040-Zero** (la recomendada) | `rp2040_keyboard.uf2` | `rp2040_keyboard_zero.uf2` |
| Raspberry Pi **Pico** normal | `rp2040_keyboard_pico.uf2` | `rp2040_keyboard_pico.uf2` |

Para grabarlo: mantén pulsado **BOOTSEL** mientras enchufas la Pico al PC, aparece una
unidad `RPI-RP2`, arrastra el `.uf2` encima. Se reinicia sola.

**Cableado** (tres hilos):

| Pico Zero | Tang Nano 20K | Qué es |
|---|---|---|
| **GP15** | **pin 31** | datos, UART 115200 8N1 (salida del Pico) |
| GND | GND | masa común |
| VBUS | 5V | alimentación del Pico |

El teclado, el mando o el ratón se enchufan al **USB de la propia Pico**. Un hub funciona
(teclado + mando a la vez está probado), y un hub **con alimentación propia** evita
sorpresas.

## 4. WiFi: ESP-01S o ESP32-C6 (opcional)

Los dos hablan el mismo protocolo (MSX UNAPI, firmware de ducasp) por la misma UART a
859372 baudios; el core no sabe cuál tiene enchufado. El C6 añade una **pantalla de
estado** y un hilo más para el indicador de turbo.

### ESP-01S (solo WiFi)

| ESP-01S | Tang Nano 20K |
|---|---|
| RX | **pin 27** |
| TX | **pin 28** |
| VCC | 3,3 V |
| GND | GND |

Firmware: el [ESP8266-UNAPI de ducasp](https://github.com/ducasp/ESP8266-UNAPI-Firmware),
compilado para 859372 baudios (soportado de serie).

### ESP32-C6-LCD-1.3 (WiFi + pantalla)

| ESP32-C6 | Tang Nano 20K | Señal |
|---|---|---|
| **GPIO17** (RX) | **pin 27** | FPGA → C6 |
| **GPIO16** (TX) | **pin 28** | C6 → FPGA |
| **GPIO3** | **pin 29** | indicador de turbo, FPGA → C6 |
| GND | GND | masa común |

Firmware: [ESP32-for-FPGA](https://github.com/Papipapito/ESP32-for-FPGA)
(`firmware_esp32c6_v2.0_merged.bin` en la release). La pantalla enseña el logo al arrancar,
el estado de la WiFi, la hora y si el turbo está activo.

Placa: Waveshare **ESP32-C6-LCD-1.3** (240×240). Se alimenta por su propio USB-C.

## 5. Primer arranque

1. HDMI al televisor, Pico con teclado, SD en la ranura, alimentación por el USB-C de la Tang.
2. Sale el **logo de MSX Barcelona** y, según el ajuste, el menú o directamente MSX-DOS.
3. Si sale el menú y quieres arrancar directo a MSX: **S** (Ajustes) → desmarcar *Menu al
   arrancar* → *Save & Restart*. Ver [04. El menú](04-menu.md).

## Actualizar

Cada versión nueva son los mismos pasos 1 y 2. **El core y el pack van emparejados**: el
menú **no** lo comprueba (solo enseña la versión del `.fs` en Ajustes, leída del puerto
0x2F), así que graba siempre el core y el pack de la misma release.

## Resumen de pines de la Tang Nano 20K

| Pin | Señal | Companion |
|---|---|---|
| 27 | UART TX (FPGA → ESP) | ESP-01S / C6 |
| 28 | UART RX (ESP → FPGA) | ESP-01S / C6 |
| 29 | turbo_status | C6 |
| 31 | teclado/joystick/ratón (Pico → FPGA) | RP2040 |

Todos en la zona libre 26-32 de la placa; la 26, 30 y 32 quedan sin usar. Nivel lógico
3,3 V en todos: conexión directa, sin adaptación.

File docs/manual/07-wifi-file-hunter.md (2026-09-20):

# 07. WiFi y File-Hunter

La WiFi la pone un módulo ESP externo que habla con el MSX por una UART. Para el software
del MSX es una tarjeta de red **MSX UNAPI** (el estándar de Konamiman), así que sirve todo
lo que use UNAPI: clientes de red, descargas, el File-Hunter del menú, `NT.COM`, etc.

El firmware del ESP es el **UNAPI de ducasp**, en dos sabores según el módulo. El core no
distingue cuál lleva: los dos hablan a **859372 baudios** por los pines 27/28.

## Qué módulo

| | ESP-01S | ESP32-C6-LCD-1.3 |
|---|---|---|
| WiFi UNAPI | ✅ | ✅ |
| Pantalla de estado | — | ✅ 240×240 |
| Indicador de turbo | — | ✅ (pin 29) |
| TLS / HTTPS | limitado (poca RAM) | ✅ |
| Alimentación | 3,3 V de la Tang | su propio USB-C |
| Firmware | [ESP8266-UNAPI de ducasp](https://github.com/ducasp/ESP8266-UNAPI-Firmware) | [ESP32-for-FPGA](https://github.com/Papipapito/ESP32-for-FPGA) |

El cableado está en [02. Instalación](02-instalacion.md).

## Configurar la red: tecla W

Desde el menú, **W** abre la configuración del ESP: escaneo de redes, elegir una, meter
la contraseña. La configuración se guarda **en el ESP**, no en la SD ni en la flash de la
Tang, así que sobrevive a cambiar de pack o de core.

Al conectar, el ESP pone en hora el reloj (NTP). El MSX pregunta la hora por UNAPI.

## La pantalla del ESP32-C6

Si montas el C6, su pantalla enseña:

- Al arrancar, el **logo de MSX Barcelona**.
- El nombre de la red, la señal y la IP.
- La **hora**, el tiempo encendido y la temperatura del chip.
- **TURBO** iluminado cuando el MSX está a 5,37 MHz (lo lee del pin 29).
- Un punto de actividad cuando hay tráfico entre el MSX y el ESP.

## File-Hunter: tecla F

Con la red conectada, **F** en el navegador abre el buscador de
[file-hunter.com](https://www.file-hunter.com): escribes parte del nombre, sale la lista,
eliges y se descarga a `FHUNT/` en la SD. Cada descarga se verifica por **CRC32**; si no
cuadra, se avisa y no se guarda. Después el fichero aparece en el navegador como uno más.

> **Estado en el MSXnano**: probado en placa el 04/09/2026 (la primera vez que cupo en el
> pack) y funciona. Lleva menos horas de uso que en el MSXimus, donde se ha validado con
> muchas descargas: si una descarga falla, apunta el fichero y el mensaje.

## Diagnóstico

| Síntoma | Mira |
|---|---|
| W dice que no hay ESP | cables 27/28 cruzados (RX↔TX), o el ESP sin alimentación |
| Se ve el ESP pero no conecta | contraseña; redes de 5 GHz no valen (los dos módulos son de 2,4 GHz) |
| Conecta pero las descargas fallan | la señal; con un ESP-01S, HTTPS puede quedarse sin memoria |
| El C6 se reinicia al conectar | alimentación del C6: por su USB-C con una fuente decente, no del 3,3 V de la Tang |

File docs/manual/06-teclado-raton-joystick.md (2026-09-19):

# 06. Teclado, ratón y joystick

Todo lo USB pasa por el **RP2040**. Hace de host USB (teclado, mando y ratón, por un hub
si quieres los tres) y le manda al FPGA el estado por un solo hilo a 115200 baudios. El
FPGA mantiene una **matriz de teclado virtual** que el MSX lee exactamente igual que
leería un teclado de membrana: para el software no hay diferencia.

Desde la v2.0 es el **único** companion de entrada: el BL616 que la Tang Nano 20K trae de
fábrica ya no se usa. Motivo: las placas fabricadas desde 2024 (las marcadas `3921`)
llevan el BL616 en un estado de arranque seguro que no admite el firmware companion, y te
quedabas sin teclado. Con el RP2040 todas las placas se comportan igual.

## El mapa de teclas

Distribución **internacional / US**. Las teclas del MSX que no existen en un teclado de PC
van así:

| Tecla MSX | En el teclado USB |
|---|---|
| **GRAPH** | Alt izquierdo, o cualquiera de las teclas **Windows** |
| **CODE / KANA** | Alt derecho |
| **STOP** | **F12**, o Bloq Despl (Scroll Lock) |
| **SELECT** | Fin (End) |
| **CAPS** | Bloq Mayús |
| **F6 – F10** | F6 – F10, enviadas como SHIFT+F1..F5, exactamente como hace un MSX real |
| F1–F5, cursores, HOME/INS/DEL, ESC/TAB/BS/RETURN | 1:1 |
| **Turbo** | **F11** conmuta el turbo (ver abajo) |
| Teclado numérico | al teclado numérico del MSX |

### La ñ y el teclado español

La BIOS internacional no lleva la ñ. Con un teclado español la tecla ñ no produce nada.
Está apuntado cómo resolverlo (reciclar la capa KANA) pero no se ha hecho: ver
[pendientes](../tecnica/09-pendientes.md).

### F11 y el turbo

**F11 conmuta el turbo** entre 3,58 y 5,37 MHz al momento, y el cambio sobrevive hasta
que el software lo cambie por los puertos Panasonic o reinicies. Si además quieres que
la máquina **arranque** ya en turbo, es el ajuste *Boot Turbo* del menú. Más en
[08. Audio, vídeo y turbo](08-audio-video-turbo.md).

## El ratón

Cualquier ratón USB se convierte en un **ratón MSX** de los de verdad —el "inteligente",
el que habla por handshake con el pin 8 del puerto de joystick, no el de cuadratura—. El
protocolo está tomado de openMSX ciclo a ciclo, incluidas las ocho fases (las cuatro
normales y las cuatro alternas que devuelven cero y que el software usa para distinguir
un ratón de un trackball).

Lo ve el software que usa ratón MSX (SymbOS, los programas de dibujo, los juegos que lo
admiten). Aparece en el **puerto de joystick 2**. Los dos botones van a los disparos.

En la placa Pico Zero, el LED de a bordo lo cuenta: **cian** = ratón montado, **magenta**
= ratón moviéndose. Útil para saber si el hub se lo ha tragado.

## El joystick

Un gamepad USB HID normal (DirectInput) es un joystick MSX en el **puerto 1**. Se usan
la cruceta o el stick izquierdo, y los botones 1 y 2 como disparos A y B.

**Autofire**: los botones **3 y 4** disparan en ráfaga (A y B respectivamente) a 10 Hz
(semiperiodo de 50 ms, elegido para que cada disparo se lea también a 50 Hz).

Todos los mandos van al **puerto 1**; el firmware no reparte un segundo mando al puerto 2.
Mando y ratón sí conviven, porque el ratón usa el puerto 2.

Los mandos **XInput** (tipo Xbox) también funcionan, con soporte específico. Los mandos
que llevan interruptor XInput/DInput funcionan en cualquiera de las dos posiciones.

## Hubs

Teclado + mando por un hub está **probado en placa**. Recomendaciones:
- Hub **con alimentación propia** si vas a colgar más de un dispositivo: la Pico se
  alimenta del 5 V de la Tang y no le sobra corriente.
- Teclados **sencillos**. Los que llevan hub interno (puerto USB en el lateral, teclas
  multimedia como dispositivo aparte) cuentan como varios dispositivos y pueden agotar
  los endpoints del RP2040.

## Latencia

Del teclado al programa: **~14 ms típicos**. Casi todo es del propio MSX (la BIOS lee el
teclado una vez por frame, ~8 ms de media) y del sondeo USB del teclado (~4 ms). Lo que
añade el RP2040 y el hilo son **0,17 ms**: menos de un 1 % de un frame, imperceptible.
Un teclado con sondeo a 1 ms (los "gaming") lo baja a ~10 ms. Cifras y desglose en
[tecnica/05-companion-rp2040.md](../tecnica/05-companion-rp2040.md).

## Si el teclado deja de responder

El FPGA lleva un **vigilante de un segundo**: si deja de recibir datos del RP2040, suelta
todas las teclas y el joystick, para que un cable suelto no deje una tecla clavada. Si el
teclado "muere", mira el cable del pin 31 y que la Pico tenga alimentación (su LED).

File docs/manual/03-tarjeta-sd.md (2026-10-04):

# 03. La tarjeta SD

La tarjeta es el disco del MSX. La maneja **Nextor** (el MSX-DOS 2 moderno de Konamiman)
a través de un driver propio para el lector SD de la Tang Nano 20K, y el menú de arranque
la lee directamente para enseñarte las ROMs y los discos.

## Qué tarjeta

Una **microSD** de marca, en **FAT16**. La mejor forma de dejarla lista es
**[MSX SD Maker](https://github.com/Papipapito/SD_Maker)**, un programa para Windows con su propio
repositorio (en [`MSXsdmaker/`](../../MSXsdmaker/LEEME.md) hay una copia con sus instrucciones): parte la tarjeta en particiones FAT16 de 2 o 4 GB como lo hace el FDISK de
Nextor, copia Nextor (la versión de tu pack), SofaRun, Multi Mente y un surtido de
utilidades, y escribe el `AUTOEXEC.BAT` que monta las demás particiones como C:, D:…

**FAT16, no FAT32.** Nextor (la 2.1.4 y la 3.0 beta 1) solo monta FAT12 y FAT16, hasta
4 GB por partición: con una tarjeta FAT32 el menú navega y lanza ROMs y discos, pero ESC no
llega a MSX-DOS y el File-Hunter no descarga («FH: la SD es FAT32»). Sin MSX SD Maker, una
tarjeta de 2 GB o menos se formatea en FAT16 desde cualquier sistema; con tarjetas mayores,
una partición de hasta 4 GB en FAT16 con una herramienta de particiones o con `CALL FDISK`
desde el propio MSX.

Nextor soporta **varias particiones** y el menú permite cambiar entre ellas con **TAB**.

## Qué poner

Lo que quieras, en la estructura de carpetas que quieras: el navegador del menú recorre
las carpetas. Por costumbre:

| Carpeta | Contenido |
|---|---|
| `ROMS/` | Cartuchos `.rom` (se cargan en la Megaram) |
| `DSK/` | Imágenes de disco `.dsk` (se montan en Nextor) |
| `FHUNT/` | La crea el File-Hunter para sus descargas |
| raíz | `NEXTOR.SYS`, `COMMAND2.COM`, `AUTOEXEC.BAT` si quieres arrancar en DOS con utilidades |

Para arrancar en **MSX-DOS** hace falta `NEXTOR.SYS` y `COMMAND2.COM` en la raíz de la
primera partición FAT16 (vienen con la distribución de Nextor, y MSX SD Maker los copia). Sin ellos, ESC en el menú te deja en BASIC con
la SD accesible como unidad.

## Las dos versiones de Nextor

El pack lleva Nextor **dentro** (no va en la SD), y hay dos packs:

| Pack | Nextor | Cuándo |
|---|---|---|
| `pack_bios_msxnano.bin` | **2.1.4** | El recomendado. Estable, es el de siempre |
| `pack_bios_msxnano_nextor3.bin` | 3 beta | Para probar Nextor 3. Validado en el MSXimus; en el MSXnano no se ha probado en placa |

La SD sirve igual para los dos. Nextor 3 trae mejoras de compatibilidad con FAT y
ficheros largos; si no sabes cuál, el 2.1.4.

> Detalle que conviene saber: Nextor 2.1 **no se salta con SHIFT** al arrancar en esta
> máquina; si quieres arrancar sin disco, quita la tarjeta.

## Editar la SD desde el PC

Sin problema: es FAT32 normal. Solo una cosa: si editas ficheros de texto del MSX
(`AUTOEXEC.BAT`, `.BAT`, ficheros de configuración), hazlo con un editor que respete los
**finales de línea CR+LF** y no "arregle" las barras invertidas. Un editor de código en
modo Unix ha roto más de un `AUTOEXEC.BAT`.

## Rendimiento

La lectura de la SD va a unos **170 sectores por segundo** (unos 5,9 ms por sector de
512 bytes). El cuello de botella no es la tarjeta: es el Z80 copiando los datos con
`LDIR`, que se lleva la mitad del tiempo. Es lo normal en un MSX con interfaz de disco;
un juego de 128 KB carga en un par de segundos. El MSXimus lo acelera con DMA porque tiene
sitio para meterlo; aquí no.

## Guardado de partidas

El guardado en SRAM de los cartuchos (por ejemplo los juegos con pila) se emula en
**RAM volátil**: se pierde al apagar. Llevarlo a la tarjeta SD está resuelto en el MSXimus
y pendiente aquí por falta de espacio — ver [pendientes](../tecnica/09-pendientes.md).

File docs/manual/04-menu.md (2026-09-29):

# 04. El menú de arranque

El menú vive **dentro del pack de BIOS** (en la ROM de MSX-MUSIC, a partir del offset
0x760) y su fuente está en el repositorio de BIOS del autor, `bios-msxnano-msximus`
(privado), común a las dos máquinas. Este capítulo cuenta cómo se usa.

## Arranque

1. Logo de **MSX Barcelona**.
2. Si *Menu al arrancar* está activado: el **navegador** de la SD.
   Si no: directamente **MSX-DOS** (o BASIC, si no hay `NEXTOR.SYS`).

Desde la v2.0 hay **una sola BIOS** y el menú es un ajuste. Antes había que elegir qué pack
grabar; ahora se elige en Ajustes y se guarda en la flash.

## El navegador

| Tecla | Hace |
|---|---|
| **↑ / ↓** | mover; **← / →** = una página |
| **RETURN** o **botón A** del mando | abrir carpeta, o lanzar la ROM / montar el disco |
| **BACKSPACE** o **botón B** | carpeta anterior |
| **TAB** | cambiar de partición |
| **/** | buscar por nombre (subcadena; RETURN busca la siguiente, ESC cancela) |
| **M** | forzar el mapper de la ROM seleccionada (cicla entre los tipos) |
| **ESC** | arrancar el sistema (MSX-DOS) |
| **S** | Ajustes |
| **W** | configuración WiFi del ESP |
| **F** | File-Hunter: buscar y descargar de internet |
| **H** | ayuda |

Los nombres largos se desplazan (marquesina) cuando la entrada está seleccionada.

**Orden** (desde la v2.1): primero las carpetas y después las ROM y los discos juntos, por
orden alfabético sin distinguir mayúsculas. **No salen los ficheros ocultos ni los de
sistema**: la `System Volume Information` de Windows, las `.Trashes`/`.fseventsd` y los
`._nombre.rom` que deja un Mac al copiar.

Caben **112 entradas por carpeta**. Si hay más, el contador de la esquina lo avisa con un
`+` (`112/112+`) y las que no caben —las últimas que se copiaron a la tarjeta— no salen:
repártelas en subcarpetas. Las listas del File-Hunter van en el orden del servidor.

## Lanzar una ROM

Al pulsar RETURN sobre un `.rom` sale la **pantalla de lanzamiento**: nombre, tamaño, el
mapper detectado (o el forzado con M) y una barra de carga mientras se copia a la Megaram.
Con la ROM cargada, cualquier tecla arranca el MSX con ella "enchufada". Ver
[05. ROMs y mappers](05-roms-mappers.md) para cómo se decide el mapper.

## Montar un disco

Sobre un `.dsk` la pantalla es la misma. El disco se monta como unidad A: y el sistema
arranca desde él (o desde la SD si el disco no es de arranque).

## Ajustes (tecla S)

| Ajuste | Qué hace |
|---|---|
| **Slot 1** | Qué hay en el slot 1 |
| **Second SCC** | Activa el segundo SCC+ |
| **Enable Scanlines** | Líneas de barrido en la salida HDMI |
| **Stereo Sound** | Mezcla estéreo (PSG/SCC a un lado, OPLL al otro) o mono |
| **Sprites 8/línea** | Limita a 8 sprites por línea como un VDP real (algunos juegos cuentan con ello) |
| **Boot Turbo** | Arrancar siempre a 5,37 MHz. **Requiere reiniciar físicamente** (apagar y encender), porque se aplica al leer la flash |
| **Version FPGA (.fs)** | Muestra la versión del core que hay grabado (lee el puerto 0x2F; `2.1` con el core de la v2.1). Solo informa: no la compara con la del pack |
| **Menu al arrancar** | Si está marcado sale el navegador; si no, arranca directo |
| **Save & Restart** | Guarda en la flash y reinicia |

Los ajustes se guardan en el **bloque de configuración** del pack (los 6 bytes del final)
y sobreviven a apagar la máquina. Actualizar el pack los pone a su valor por defecto.

## File-Hunter (tecla F)

Con WiFi conectada, busca en [file-hunter.com](https://www.file-hunter.com) por nombre y
descarga ROMs e imágenes de disco a la carpeta `FHUNT/` de la SD, verificando el CRC32 de
cada descarga. Después aparecen en el navegador como cualquier otro fichero.

> **Estado en el MSXnano**: cabe en el pack desde el 04/09/2026 y ese mismo día se probó
> en placa: funciona. Ver [07. WiFi y File-Hunter](07-wifi-file-hunter.md).

## WiFi (tecla W)

Configura la red del ESP (escaneo de redes, contraseña, hora por NTP). Necesita un ESP-01S
o un ESP32-C6 enchufado. Ver [07](07-wifi-file-hunter.md).

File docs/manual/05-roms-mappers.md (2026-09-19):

# 05. ROMs y mappers

No hay slot de cartucho: las ROMs se cargan desde la SD en una **Megaram de 2 MB** que
vive en el **slot 2** y que sabe comportarse como los mappers más comunes. El menú copia
el fichero a la Megaram, le dice al hardware qué mapper imitar, y reinicia el MSX con el
"cartucho" puesto.

## Los mappers que hay en el hardware

`fpga/src/megaram.v` implementa cuatro modos, seleccionables por el menú:

| Modo | Mapper | Bancos | Registros de cambio de banco |
|---|---|---|---|
| Konami4 | Konami sin SCC | 8 KB | 0x6000 · 0x8000 · 0xA000 (el banco de 0x4000 es fijo) |
| Konami SCC | Konami con SCC | 8 KB | 0x5000 · 0x7000 · 0x9000 · 0xB000 |
| ASCII8 | ASCII de 8 KB | 8 KB | 0x6000 · 0x6800 · 0x7000 · 0x7800 |
| ASCII16 | ASCII de 16 KB | 16 KB | 0x6000 · 0x7000 |

Las ROMs **planas** (16 KB, 32 KB, 48 KB sin mapper) se cargan tal cual, sin cambio de
banco. Cubre la inmensa mayoría de lo que existe para MSX1/MSX2: Konami, la generación
ASCII, y los cartuchos sencillos.

Lo que **no** está: mappers exóticos (R-Type de 384 KB, Cross Blaim, Harry Fox, los NEO
modernos, SRAM de cartucho tipo Game Master 2 o Koei). Algunos los tiene el MSXimus; aquí
no cabían.

## Cómo se decide el mapper

En este orden:

1. **Etiqueta en el nombre del fichero**: `Juego [KonamiSCC].rom`, `[ASCII8]`, `[ASCII16]`,
   `[Konami4]`. Es lo más fiable, y lo que te recomiendo si un juego no arranca.
2. **Heurística**: la cabecera `AB`, el tamaño, y un barrido del código buscando escrituras
   a las direcciones de los registros de banco de cada mapper.
3. Si nada encaja: **ROM plana**.

El barrido de código falla con juegos que cambian de banco con `LD (HL),A` en vez de con
una escritura directa (Ikari, por ejemplo): para esos, la etiqueta.

## Forzar el mapper: tecla M

En el navegador, con la ROM seleccionada, **M** cicla entre los tipos. El mapper forzado
se muestra en la pantalla de lanzamiento. No se guarda: si quieres que sea permanente,
pon la etiqueta en el nombre.

## La Megaram desde el software

Para el software que corre en el MSX, la Megaram es una **Megaram SCC estándar en el slot 2**:
2 MB, con el registro de control habitual. **SofaRun** la detecta sola y carga ROMs desde
MSX-DOS sin pasar por el menú. Otros cargadores (por ejemplo `ODO`) puede que necesiten
que les digas el slot a mano.

## Dos SCC

El core lleva **dos SCC+**: el de la Megaram y un segundo que se activa en Ajustes
(*Second SCC*). Con los dos, el software que pide "SCC en dos slots" (Konami SCC-I, algunos
reproductores) lo encuentra. Los dos suenan mezclados en estéreo con el resto.

## Lo que no arranca y por qué

| Síntoma | Causa probable | Qué hacer |
|---|---|---|
| Pantalla negra tras lanzar | mapper mal detectado | etiqueta o tecla M |
| Arranca y se cuelga al cambiar de nivel | mapper casi bien (8 vs 16 KB) | probar el otro ASCII |
| "Se ve" pero sin sonido de SCC | ROM etiquetada Konami4 siendo SCC | `[KonamiSCC]` |
| ROM de más de 2 MB | no cabe en la Megaram | no hay solución aquí |
| ROM con SRAM (guardado) | el guardado es volátil | se pierde al apagar; ver [pendientes](../tecnica/09-pendientes.md) |

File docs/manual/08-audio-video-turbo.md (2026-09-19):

# 08. Audio, vídeo y turbo

## Audio

Cuatro fuentes, mezcladas en el FPGA y sacadas **por el HDMI** (no hay jack analógico en
la Tang Nano 20K):

| Chip | Qué es | Dónde |
|---|---|---|
| **PSG** (YM2149) | Los tres canales de tono + ruido de todo MSX | puertos 0xA0-0xA2 |
| **OPLL** (YM2413, MSX-MUSIC) | FM de 9 canales; la BIOS de MSX-MUSIC va en el pack | puertos 0x7C/0x7D |
| **SCC+** ×2 | El chip de ondas de Konami. Uno en la Megaram, el segundo se activa en Ajustes | en el espacio de la Megaram |
| — | El click de teclado y el motor de casete del PPI | puerto 0xAA |

**Estéreo**: con *Stereo Sound* activado en Ajustes, PSG y SCC van a un canal y el OPLL al
otro, como en el OCM. Desactivado, todo mezclado en mono a los dos.

El PSG pasa por un **filtro** (`psg_filter.v`) que le quita el escalón digital y lo
acerca al sonido de un MSX real por el altavoz de un televisor.

Lo que **no** hay: OPL4/MoonSound (no cabe ni de lejos; hay un estudio de viabilidad en
[pendientes](../tecnica/09-pendientes.md)), Y8950/MSX-AUDIO, ni salida analógica.

## Vídeo

El VDP es un **V9958** —el del MSX2+— con salida **HDMI**. Todos los modos, incluidos
SCREEN 10-12 (YJK) y el scroll horizontal por hardware (R#26/R#27) que usan los juegos
"smooth scroll".

| Ajuste | Qué hace |
|---|---|
| **Enable Scanlines** | Líneas de barrido alternas, para el efecto de monitor de tubo |
| **Sprites 8/línea** | Limita a 8 sprites por línea como el VDP real. Por defecto el core deja pintar más (sin parpadeo); algunos juegos y demos cuentan con el límite para efectos, y ahí conviene activarlo |

La imagen sale a la resolución nativa del VDP escalada por el HDMI; la sincronización es
la del MSX (50 o 60 Hz según lo que pida el software por R#9).

Dos rarezas conocidas del vídeo, ambas con expediente:

- **R-Type con el parche de smooth-scroll** tiembla en un ~15 % de los frames. Se sabe
  la causa (la interrupción de línea se dispara dos veces) y el arreglo está escrito y
  probado en simulación, pero **no cabe en el chip**: ver
  [pendientes](../tecnica/09-pendientes.md).
- La paleta se expande con ceros en vez de replicando bits, así que **los blancos salen
  un ~12 % oscuros**. Es el hallazgo número uno de la lista de mejoras aparcadas.

## Turbo

El MSXnano lleva el turbo **Panasonic WSX**: el Z80 pasa de 3,579545 a **5,369318 MHz
exactos** (3/2), con el VDP y el sonido a su velocidad normal. Es el mismo mecanismo que
usan el Panasonic FS-A1WSX y el FS-A1WX, así que el software que lo conoce lo detecta.

### Cómo activarlo

| Forma | Cómo | Cuándo |
|---|---|---|
| **F11** en el teclado USB | conmuta al momento | para probar |
| **Boot Turbo** en Ajustes | arranca siempre en turbo; requiere apagar y encender | para dejarlo fijo |
| **Desde software** | `OUT &H40,8 : OUT &H41,128` activa; `OUT &H41,129` desactiva | programas y `AUTOEXEC` |
| **`TURBO.COM`** | `TURBO ON` / `TURBO OFF` / `TURBO` (consulta) desde MSX-DOS | [msx-turbo](https://github.com/Papipapito/msx-turbo) |

El protocolo: el dispositivo 8 del **switched I/O** (`OUT &H40,8`), `INP(&H40)` devuelve
`&HF7` si está presente, y el bit 0 de `&H41` es el estado (0 = turbo). Es exactamente lo
que hace un Panasonic real, así que `INP(&H41)` te dice en qué velocidad estás.

Si F11 y el software cambian el turbo en el mismo ciclo, **gana el software**: en el
chip real (T9769) el puerto es el único control.

### Qué acelera y qué no

Acelera el Z80 en RAM y ROM. **No** acelera los accesos al VDP, que siguen con las esperas
del MSX, ni el sonido, ni la SD (que va limitada por el propio protocolo). En la práctica:
los juegos van más fluidos, las cargas de disco un poco más rápidas, y el software con
temporización por bucles (algunos juegos de MSX1, música) puede ir demasiado deprisa —
para eso está F11.

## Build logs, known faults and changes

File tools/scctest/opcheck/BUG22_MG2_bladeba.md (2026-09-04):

# Bug #22 — MG2/Solid Snake glitchea en partida · Hallazgos del repo bladeba/MSX

> Nota de traspaso (2026-06-23). Generada tras investigar el repo público
> **github.com/bladeba/MSX** (Victor Martínez) buscando referencias para el bug #22.
> **Cómo usar esta nota:** abre una sesión nueva de Claude *dentro de*
> `C:\Users\alber\MSXnano` (así tienes CLAUDE.md + CodeGraph + este harness), di
> "lee tools/scctest/opcheck/BUG22_MG2_bladeba.md" y ataca el plan de la sección 6.

---

## 1. Estado del bug (recordatorio)
MG2/Solid Snake: intro OK, **gameplay corrupto cuando se lanza desde el menú del
nano**; va bien lanzado desde **SofaRun** (OCM). ~11 hipótesis ya descartadas.
Causa sospechada: quisquillosidad de MG2 con los **slots** (no tanto el mapper en sí).

## 2. Qué aporta bladeba/MSX (evidencia nueva)
El repo contiene **el fix comunitario exacto de este problema**:

- **`Fixes/MGEAR2-ESP-FRS-SLOTEXPANDIDO.IPS`** — parche de MG2 que incluye, entre
  otras cosas, un **"parche de slot expandido"** cuya única función es *hacer que
  MG2 funcione en un slot expandido*. Es decir: **MG2 de fábrica NO tolera correr
  desde un slot/subslot expandido** — asume que su ROM Konami-SCC de 512 KB está en
  un slot primario no expandido y usa selects de slot hardcodeados + pokes anticopia.
  (No se pudo decodificar byte a byte: 36 KB dominados por la traducción.)

- **`Fixes/Sdsnatcher-disk1.IPS`** (535 bytes, **decodificado entero**) — usa el
  mismo mecanismo de bajo nivel y lo revela. La técnica del fix de slot expandido es:
  1. En el arranque, **descubrir en runtime** el slot+subslot real donde está el
     cartucho (lee EXPTBL `0FCC1h` bit7 = slot expandido; recorre el campo de subslot
     escribiendo el byte compuesto en `0FFFFh`, que se lee **complementado**; conmuta
     el slot primario por el puerto `0A8h`).
  2. **Reescribir (auto-parchear)** los selects de slot hardcodeados del juego para
     que apunten al subslot descubierto, de modo que las conmutaciones de banco y las
     escrituras al **banco 0x3F (= registros de la SCC, NO un bank-switch real)** se
     enruten al slot correcto.
  - Handshake SCC canónico que confirma: `LD (#9000),#3F` arma la SCC y entonces la
    ventana `#9800` revela su wave-RAM (write/CPL/read-back). Idéntico a lo que ya
    hace nuestro `scctest.asm`.

- **`SRC/Miscellaneous/Search_SCC.asm`** — versión "limpia" del barrido de
  slot/subslot buscando la SCC (EXPTBL bit7 + ENASLT `#0024` + sonda `#9000`/`#9800`).

**Conclusión:** el fix oficial trata el bug como *"MG2 no sabe correr en slot
expandido"*. Y resulta que **el nano lanza la ROM en un subslot expandido** (ver §3).

## 3. Por qué encaja con nuestro RTL (rutas exactas)
`tools/scctest/opcheck/slotchk.txt` ya documenta: la ROM lanzada queda en
**slot 0, subslot 3** (`@4000 = 4C 47 F3`). Y en el RTL:

- **`fpga/top.v:921`** — comentario `//expanded slots 0 & 3`.
- **`fpga/top.v:932-947`** — decodificación de `xffff` (registro de subslot `0FFFFh`),
  `pri_slot_num`, `exp_slotx_num`.
- **`fpga/top.v:908-909`** — PPI puerto `A8h` (registro de slot primario).
- **`fpga/top.v:1597`** — `scc2_req3` (la megaram/SCC del cartucho) se habilita con
  `pri_slot == config_megaram_slot && exp_slotx_num[3] == 1 && xffff == 0`.
  ⇒ **La megaram + su SCC viven en un subslot EXPANDIDO (subslot 3).**
- **`fpga/top.v:1211`** — `mapper_req3` también gateado por `exp_slotx_num[0] && xffff==0`.

Es exactamente el escenario para el que existe el parche de slot expandido de bladeba.

## 4. Las dos hipótesis (refinadas con el RTL real)

### Hipótesis A — interacción con el SLOT EXPANDIDO  ← lead más fuerte
MG2 se lanza desde el menú en **slot 0 / subslot 3 (expandido)**; MG2 de fábrica no
tolera eso. **SofaRun va bien** probablemente porque deja a MG2 en un contexto de slot
que sí espera (primario no expandido) o porque corre bajo DOS con la SCC ya colocada.

Acciones:
1. **Comparar la colocación de slot menú vs SofaRun**: instrumentar con openMSX
   (extender `nano_slotchk.tcl`) y volcar, en el momento del lanzamiento, el estado de
   `pri_slot_num` / `exp_slotx_num` / `xffff` y los selects que hace MG2.
2. **Probar a lanzar MG2 en un slot primario NO expandido** (replicar lo que hace
   SofaRun). Si la corrupción desaparece → confirmada A. Mirar dónde el menú decide
   `config_megaram_slot` / la colocación en subslot 3 y si se puede ofrecer una ruta
   "primario plano" para cartuchos quisquillosos.
3. **Auditar el camino de subslot expandido del SCC**: revisar que cuando MG2 accede a
   la SCC *a través del subslot 3*, el decode de `megaram.v` (ventana `#9800`, banco
   `#3F`, regs `#B000`/`#BFFE`) responde igual que por un slot plano. Posible fallo:
   que `xffff==0` / `exp_slotx_num[3]` deseleccione la ventana SCC en algún acceso que
   MG2 hace creyendo estar en su slot.

### Hipótesis B — regla "banco 0x3F = SCC, no bank-switch"  ← parece YA resuelta
**OJO: esto ya está implementado.** No rehacer; solo verificar de refilón.
- `fpga/src/megaram.v:36-61` — la ventana `#9800` solo se abre con
  `megaram_reg2[5:0]==6'b111111` (= 0x3F) y en modo SCC (`ff_scc_mode`,
  `map_sel==2'b10`); en Konami4/ASCII un 0x3F en reg2 **no** abre la ventana.
- `fpga/src/megaram.v:45-52` — `ff_scc_mode` registrado, comentado como
  *"fix timing regresion MG2 v1.7"*.
- `fpga/src/megaram.v:214-224` — guard explícito: *"MG2 hace pokes anticopia a
  BFFE/7FFE que en una megaram abierta habilitan escritura"* → ya contemplado.

→ La causa del bug probablemente **no** está aquí. Solo confirmar contra el modelo de
referencia (§7) que no quede ningún caso de 0x3F mal interpretado **bajo subslot
expandido**.

## 5. Qué NO rehacer
- El handshake/conformidad SCC ya lo cubre `tools/scctest/scctest.asm` (slots 1-3 vía
  A8; SCC compat + SCC+). La **regla 0x3F** y los **guards anticopia de MG2** ya están
  en `megaram.v`. El foco nuevo es el **camino expandido (subslot 3)**, no el mapper.

## 6. Plan de ataque para la próxima sesión (en orden)
1. Leer esta nota + `git log` reciente de `fpga/top.v` y `fpga/src/megaram.v`
   (`ff_scc_mode`/v1.7) para no repetir lo ya probado.
2. **Extender `scctest.asm`**: hoy solo recorre slots **primarios** vía `A8`. Añadir un
   modo que coloque/pruebe la SCC **a través de un subslot expandido** (escribir `0FFFFh`
   complementado, como Search_SCC.asm) y verificar que la ventana `#9800`/regs SCC+
   responden igual que por slot plano. Esto reproduce el acceso de MG2 en subslot 3.
3. **Trace en openMSX (réplica `MSXnano_test`)** con `mg2_launchglitch.tcl` +
   `nano_slotchk.tcl` extendido: capturar, en el frame donde aparece la corrupción, los
   selects de slot/subslot de MG2 y los accesos a `#9000`/`#9800`/`#B000`/`#BFFE`.
   Comparar **menú vs SofaRun** lado a lado.
4. Según el resultado:
   - Si A: ajustar el menú/loader para presentar MG2 en primario no expandido, **o**
     corregir el decode SCC bajo `exp_slotx_num[3]` en `megaram.v`/`top.v`.
   - Recordar la restricción del proyecto: **NUNCA reset HW al lanzar** (la megaram
     decae con la recarga de flash) — la solución debe ser por colocación/decode, no por reset.
5. Regresión: re-probar MG2 (intro+gameplay), Solid Snake, y otros Konami-SCC, más el
   `SCCTEST.COM` en HW, antes de mergear (rama desde `dev`).

## 7. Referencias
- **Modelo de oro** (cómo debe comportarse la MegaFlashROM SCC+ SD):
  openMSX `src/memory/MegaFlashRomSCCPlusSD.cc`
  (https://github.com/openMSX/openMSX/blob/master/src/memory/MegaFlashRomSCCPlusSD.cc)
- Mapper/SCC Konami + detección: https://www.msx.org/wiki/MegaROM_Mappers ·
  http://bifi.msxnet.org/msxnet/tech/soundcartridge · http://bifi.msxnet.org/msxnet/tech/scc
- Problema slot expandido de MG2 + slotfix:
  https://www.msx.org/forum/msx-talk/software/metal-gear-solid-snake-through-megaflashrom-scc-512k-not-working
- FRS Turbo Fix (parte "FRS" del IPS, timing R800): https://frs.badcoffee.info/patches.html ·
  https://www.msx.org/news/development/en/turbo-fix-patch-metal-gear-2
- Repo fuente de los hallazgos: https://github.com/bladeba/MSX (carpetas `Fixes/`, `SRC/Miscellaneous/`)

## 10. CORRECCION IMPORTANTE (2026-06-23) — MG2 arranca en SLOT 2 PLANO

Al leer la secuencia de lanzamiento real (`menu_main.asm` `boot_stub`, ~1873-1897)
se descubre que **el lanzador NO pone MG2 en un subslot expandido**: hace
`ld a,#02 / call ENASLT` para páginas 1 y 2 → **primario 2, PLANO** (id #02 con
bit7=0). Como MG2 arranca (intro OK), la megaram responde ahí: **slot 2 plano**,
igual que bajo SofaRun. El "slot 0/subslot 3" de `slotchk.txt` era de la **réplica
openMSX** (`.tcl` hardcodeado); el "slot 3 expandido / config_megaram_slot=2'b11"
del análisis RTL era la **rama fallback** (sin flash-config), no la activa
(`config_megaram_slot = config1_ff[7:6] = var_megslt = slot 2`; `MEG_SLOT equ #02`).

**Implicaciones:**
- La teoría de bladeba ("MG2 no tolera slot expandido") **NO aplica a nuestro
  lanzador**: ya usamos un slot plano. La extensión `test_subslot` de §9 prueba un
  camino (subslot 3 expandido) que MG2 **no usa al arrancar** → no es la ruta del
  bug #22 (queda como diagnóstico SCC general, no como sonda de #22).
- Los 3 "forks" del RTL de §9 (scc_sound_disable, CDC exp_slotx_num[3], doble
  contabilidad) son diferencias del camino EXPANDIDO `*_req3`; MG2 usa el PLANO
  `*_req12` → tampoco aplican.
- El bug está en la **secuencia de lanzamiento** (VDP/paleta/cerrojo/H.STKE) vs un
  arranque limpio BIOS/SofaRun. Encaja con el síntoma: el fundido-a-negro por
  cambio de paleta tras el logo azul no ocurre. Es SOFTWARE (`menu_main.asm`), sin
  recompilar FPGA.

**Siguiente real (§6 paso 3, reenfocado al VDP):** trazar en openMSX las escrituras
de paleta/VDP de MG2 durante el fundido (puerto `#9A`, R#16/R#17 vía `#99`)
**menú vs SofaRun** y localizar la divergencia. (El `launch_rom` hace INIT32 +
vdp_clean_tbl + restore_palette + cerrojo mode_a=0x80 antes del INIT del cartucho:
sospechosos de alterar el estado VDP que MG2 espera.)

## 11. CAUSA RAIZ + FIX (2026-06-23) — motor de comandos VDP residual

**El glitch NO se reproduce en la réplica openMSX** (MG2 lanzado por el menú llega
limpio a título y gameplay: `lg_06/08/10.png`). → es **específico del FPGA**.
Cruzado con que SofaRun va bien en el mismo FPGA, la causa es:

> El **logo de arranque** (MSX Barcelona) pinta su bitmap con **comandos VDP** y
> deja el motor del V9938/58 **a medias (CE asserted) + R32-R46 sucios**. El
> `launch_rom` reinicia R0-R27 y la paleta pero **NUNCA toca el bloque de comandos
> (R32-R46) ni drena CE**. MG2, al entrar, hace su **HMMV de borrado** (el fundido
> a negro / limpiar la página de trabajo, trace `mg2_io.txt` L61076-61088: HMMV
> DX=40,DY=832,NX=168,NY=72,CLR=0 en SCREEN 5); con el motor aún "ocupado" para el
> FPGA ese borrado no cuaja → los 103 HMMM del título se componen sobre VRAM sin
> limpiar → "la pantalla de carga se mezcla con el juego".

Encaja con las 3 restricciones: (a) FPGA-only — openMSX modela el motor instantáneo
y el abort de libro; el RTL real tiene handshake CE + gate STIDLE/CMRWR
(`vdp_command.vhd:458-502`). (b) menú falla / SofaRun limpio — el `launch_rom`
provablemente no tiene ningún `out(#99)` a registro ≥32 ni lectura de S#2; SofaRun
corre bajo DOS con el motor ocioso. (c) síntoma = el HMMV de borrado no surte efecto.

**FIX (software, sin recompilar FPGA)** — `menu_main.asm`, rutina `vdp_cmd_abort`
llamada en `launch_rom` justo antes de saltar a `boot_stub`: como acabamos de hacer
INIT32 → SCREEN 1, ahí `W_VDPCMD_EN=0`, así que escribir **R#46=0 fuerza STIDLE y
limpia CE** (verificado en `vdp_command.vhd:458-502` / `198-199`). Se limpian
R32-R45 (ARG/coords) y R46 el ÚLTIMO. Build: `make clean && make rom` (OK, asMSX) +
inyectado en `goauld_rom_int.bin` @0x6C000. **PENDIENTE: validar en HW** (flashear
pack, lanzar MG2 desde el menú, confirmar que hace el fundido a negro).

**Confianza ~75-90%.** Si NO lo arregla: (1) añadir drenaje de S#2 (poll CE) antes
del abort; (2) si persiste, es el latch de modo en HSYNC (`vdp_register.vhd:319-329`
alimentando el command engine combinacional) → fix RTL con rebuild. Detalle completo
en el workflow `ws5gmr3zn`. Dato sin verificar (eslabón): que el logo deje CE=1 —
confirmable trazando el logo (no MG2) en openMSX, o por el propio resultado en HW.

## 9. Progreso (2026-06-23) — §6 paso 2 HECHO

**`scctest.asm` extendido a v4** con el camino de **subslot expandido** (rutina
`test_subslot`), handshake refactorizado (`scc_handshake` + `scc_restore_banks`
compartidos por el camino plano y el expandido → comparación apples-to-apples).
Revisado adversarialmente contra el RTL (0 bugs en pila/slot, máscaras A8,
round-trip de `#FFFF`, scoping de labels, DI/EI). **Falta**: ensamblar
(`asmsx -z scctest.asm` → `SCCTEST.COM`) y correr en HW.

**Verdades de campo confirmadas contra el RTL (corrigen suposiciones previas):**
- La megaram/SCC vive en **primario 3 / subslot 3 (expandido)** — `config_megaram_slot
  = config1_ff[7:6] = 2'b11` (top.v:2014/2045), y `scc2_req3` exige
  `pri_slot==3 && exp_slotx_num[3]==1 && xffff==0` (top.v:1597). El "slot 2" del
  comentario de scctest = nomenclatura OCM del *modo*, no el slot MSX; el "slot 0"
  de slotchk venía del `.tcl` hardcodeado (réplica openMSX), no del HW real.
- `map_sel = Slot2Mode` (top.v:1612); **el SWIO `#D4/#0F` ya arma `map_sel=10`
  (modo SCC)** (menu_main.asm:1448-1452) → no hace falta SWIO extra para la ventana.
- `#FFFF` se guarda PLANO (top.v:966) y se lee COMPLEMENTADO; la escritura solo
  cuaja si la página 3 es primario 3 (top.v:940).
- Acceso correcto a la SCC por subslot 3: A8 pág2=3 (`[5:4]=11`) + `#FFFF`=`#F0`
  (pág2 sub3) con pág3=3 momentáneo para la escritura.

**Cómo leer el resultado en HW:** la nueva línea `Subslot exp (pri3/sub3): SCC/SCC+/---`.
Como la megaram solo responde expandida, lo esperado es `Slot 3: ---` (barrido plano)
**y** `Subslot exp: SCC` → confirma que la SCC vive en el subslot expandido. Si el
expandido también da `---`, el decode estático del subslot está roto (ver abajo).

**Candidatos de causa raíz del RTL (forks que solo existen en el camino expandido
`*_req3`, no en el plano `*_req12`) — leads para el paso 3:**
1. **`scc_sound_disable` asimétrico (top.v:1557 vs 1558):** `scc_req3` NO está gateado
   por `scc_sound_disable`, `scc_req12` SÍ. Los pokes anticopia de MG2 a `#7FFE/#BFFE`
   tocan ese bit → la ventana de sonido se comporta distinto en el camino que MG2 usa.
   **Lead más accionable.**
2. **CDC `exp_slotx_num[3]` (top.v:966 clk_27m → 1594 clk_54m):** el camino plano no
   tiene término `exp_slotx_num`; el expandido sí, cruzando dominios. Un bank-switch
   in-game podría desincronizar y deseleccionar la megaram un frame. **No reproducible
   con sonda estática** → si la sonda pasa pero el glitch persiste, este es el sospechoso.
3. **Doble contabilidad `megaram_reg2` (megaram.v:202, con guard) vs `scc_bank2`
   (top.v:1532, sin guard):** tras los pokes de modo pueden divergir → ventana abierta
   en un decoder y no en el otro.

**Siguiente (§6 paso 3):** trazar en openMSX (réplica `MSXnano_test`) los selects de
slot/subslot y accesos a `#9000/#9800/#B000/#BFFE` en el frame de la corrupción,
**menú vs SofaRun** lado a lado (`mg2_launchglitch.tcl` + `nano_slotchk.tcl` extendido).

## 8. Licencia / cuidado
bladeba/MSX **no tiene licencia** (todos los derechos reservados). Los *algoritmos*
(handshake SCC, barrido de slot/subslot, regla 0x3F) no son copyrightables y están
documentados en las fuentes de §7 → **reimplementar clean-room** (es lo que ya hacemos).
**No** incrustar ni redistribuir las ROMs/IPS parcheadas (Konami MG2 + traducción de
Pazos + parche de FRS). Usarlas solo como referencia privada de comportamiento.

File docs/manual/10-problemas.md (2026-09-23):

# 10. Problemas frecuentes

Por síntoma. Cada entrada dice la causa más probable primero.

## Arranque

| Síntoma | Causa probable | Qué hacer |
|---|---|---|
| Pantalla negra, ningún LED de actividad | El core no está grabado, o el Programmer lo grabó en SRAM en vez de en la flash | Regrabar el `.fs` en modo *External Flash*, dirección `0x000000` |
| Logo y luego nada, o basura | Falta el pack, o está en la dirección equivocada | Grabar el pack en `0x200000` con *exFlash C Bin Erase, Program thru GAO-Bridge* |
| Cosas raras tras actualizar solo una parte | Core y pack de releases distintas (el menú no lo comprueba) | Grabar el `.fs` y el pack de la misma release; Ajustes → *Version FPGA* dice qué core hay |
| Arranca en BASIC en vez de MSX-DOS | No hay `NEXTOR.SYS` + `COMMAND2.COM` en la raíz de la SD | Copiarlos de la distribución de Nextor |
| Arranca directo a DOS y quiero el menú | *Menu al arrancar* desmarcado | S → marcar → Save & Restart |
| Se reinicia solo en bucle | Alimentación: el USB-C de un PC a veces no da corriente suficiente con la Pico y un hub colgando | Fuente USB de solo corriente, de 2 A |

## Teclado, ratón, mando

| Síntoma | Causa probable | Qué hacer |
|---|---|---|
| Sin teclado | La Pico sin firmware, sin alimentación, o el cable del pin 31 | LED de la Pico encendido; regrabar el `.uf2`; comprobar GP15 → pin 31 |
| Teclado va, pero se queda una tecla pulsada | No debería: el vigilante de 1 s lo suelta todo | Si pasa, cable del pin 31 con mal contacto |
| El teclado funciona a ratos con un hub | Hub sin alimentación propia | Hub alimentado |
| El mando no hace nada | Mando no HID o modo raro | Probar el interruptor XInput/DInput si lo tiene; otro mando |
| El ratón no se mueve | El software no usa ratón MSX, o está en el puerto 1 | El ratón vive en el puerto 2; el LED de la Pico en cian confirma que está montado |
| La ñ no sale | La BIOS internacional no la tiene | Pendiente; ver [tecnica/09](../tecnica/09-pendientes.md) |
| F11 no cambia el turbo | Estás en un software que lo fija por los puertos Panasonic | Es lo correcto: gana el software |

## ROMs y discos

| Síntoma | Causa probable | Qué hacer |
|---|---|---|
| ROM que no arranca | Mapper mal detectado | Etiqueta `[KonamiSCC]`/`[ASCII8]`/`[ASCII16]`/`[Konami4]` en el nombre, o tecla M |
| Se cuelga al cambiar de nivel | Mapper casi bien | Probar el otro tamaño de ASCII |
| ROM mayor de 2 MB | No cabe en la Megaram | Sin solución aquí |
| El guardado del juego desaparece | La SRAM es volátil en esta máquina | Pendiente; ver [tecnica/09](../tecnica/09-pendientes.md) |
| Disco que no monta | Imagen no estándar (no 720 KB / 360 KB) o corrupta | Comprobar la imagen en un emulador |
| La SD no se ve | No es FAT32, o partición extendida | Formatear FAT32, partición primaria |

## WiFi

| Síntoma | Causa probable | Qué hacer |
|---|---|---|
| W dice que no hay ESP | RX/TX cruzados o ESP sin alimentar | Pin 27 = entrada del ESP (RX), pin 28 = salida (TX) |
| No conecta a la red | Red de 5 GHz | Los módulos son de 2,4 GHz |
| El C6 se reinicia al conectar | Alimentación del C6 | Por su propio USB-C con una fuente decente |
| File-Hunter falla | Sin red, CRC que no cuadra, o SD llena | Reintentar; si se repite con un fichero concreto, apuntar el nombre; ver [07](07-wifi-file-hunter.md) |

## Vídeo y sonido

| Síntoma | Causa probable | Qué hacer |
|---|---|---|
| El monitor no detecta señal | Algunos monitores no negocian bien | Otro cable / otro monitor; un televisor suele ser más tolerante |
| Sin sonido | El HDMI es la única salida | El monitor tiene que tener altavoces, o pasar por un extractor de audio HDMI |
| Solo suena un lado | *Stereo Sound* activado y el software solo usa PSG | Es normal: el PSG va a un lado; desactívalo si prefieres mono |
| R-Type con smooth-scroll tiembla | Bug conocido de la interrupción de línea | Arreglo escrito pero no cabe; ver [tecnica/09](../tecnica/09-pendientes.md) |
| Los blancos se ven grises | Expansión de paleta del core | Conocido; ver [tecnica/09](../tecnica/09-pendientes.md) |
| Parpadeo de sprites que no debería estar | *Sprites 8/línea* activado | Desactivarlo (o activarlo si el juego lo necesita) |

## Cómo reportar un problema

Un issue en [github.com/Papipapito/MSXnano](https://github.com/Papipapito/MSXnano/issues)
con: versión del core (Ajustes → *Version FPGA*), pack que usas, qué companions tienes
montados, y el software concreto que falla. Una foto de la pantalla vale más que una
descripción.

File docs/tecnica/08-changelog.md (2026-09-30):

# 08. Historial de versiones

Resumen técnico de cada release (tags del repo). Las notas completas están en
[GitHub → Releases](https://github.com/Papipapito/MSXnano/releases). Versión del core =
puerto `0x2F`.

## v2.1 — 29 de septiembre de 2026 · `FPGA_VERSION = 0x21` · **pendiente de validar en placa**

Publicada el 30/09 como **pre-release** [`v2.1`](https://github.com/Papipapito/MSXnano/releases/tag/v2.1): `msxnano_v2.1.fs`
(7e5ac2d3), los cuatro packs (2.1.4 eb03b904, inglés e7fe504e, Nextor 3 a2a0c4c3, inglés con
Nextor 3 422dd54f) y los firmwares de la RP2040 y del C6 de la v2.0, que no cambian. Pasará
a release normal cuando se valide en placa. `bin/msxnano.fs` es ya el de la v2.1.

- **Mux de lectura de la CPU (`cpu_din`) por grupos** en vez de una cadena de ~31
  ternarios: misma prioridad (demostrado con yosys + Icarus, ver [06](06-sintesis-timing.md)).
  `clock_54m` cierra en **6 de 6 dados** (55,1-62,5 MHz) frente a 3 de 6 con la cadena.
  Entregado el dado **999917**: **62,494 MHz (+8,49 ns)**, CLS 9.188 (89 %), que ahora
  va en el repo. Idea de MSXHeroTN.
- **Navegador** (pack nuevo, repo de BIOS `ee18b2c`): **ordenado** (carpetas primero,
  alfabético sin mayúsculas), **sin ficheros ocultos ni de sistema** (Windows y macOS) y
  con **aviso `+`** en el contador si la carpeta tiene más de las **112** entradas que
  caben (antes 115, sin aviso). Probado en un Z80 de openMSX en las 6 variantes.
- **Joystick en el menú**: solo auto-repite arriba/abajo; izquierda/derecha (saltar 18 filas)
  cuentan una vez por pulsación. En el MSXimus 60K un mando USB con la izquierda atascada
  devolvía 18 atrás toda selección ≥ 18 y parecía que la lista no hacía scroll.

## v2.0-final — 23 de septiembre de 2026

- **Los mismos binarios que la v2.0**: `.fs` del par 48 (dado 999961, md5 `b0e374d8…`) y
  los packs del 04/09 (Nextor 2.1.4 `4dc4e4f5…`, Nextor 3 beta `d6f3b2d4…`).
- Validado en placa por Albert el 23/09: **F11 → 5,37 MHz**, mando, ratón, Space Manbow y
  Metal Gear 2, y el guardado de cambios.
- La documentación completa (`docs/`), la carcasa con las dos tapas y los dos packs de
  BIOS en la release.

## v2.0 — 4 de septiembre de 2026 · `FPGA_VERSION = 0x20`

- **Fuera el BL616**: teclado, mando y **ratón MSX** por un **RP2040** (GP15 → pin 31, un
  cable). Las placas `3921` de 2024+ traían el BL616 con *secure boot* y muchas se
  quedaban sin teclado; con la RP2040 todas se comportan igual. −479 LUT, −353 FF y un
  reloj inferido menos (`WARN TA1132`).
- **Ratón MSX** (`msx_mouse.v`, protocolo de openMSX, 8 fases, puerto 2) servido por el
  mensaje `0xD0` del RP2040; diagnóstico en `0x2B`.
- **Una sola BIOS**: el menú se activa/desactiva en Ajustes (*Menu al arrancar*, bit 3 de
  `config2`, guardado en flash). Antes había dos packs.
- **Descargas** desde el menú con WiFi (File-Hunter, tecla F). Cupo en el pack del nano
  al retirar la cinta web; probado en placa el 04/09.
- **ESP32-C6 con pantalla** como companion opcional (estado, reloj, turbo, logo animado);
  el ESP-01S sigue valiendo. Pin 29 = estado del turbo.
- **PPI**: decodificado `0xAB` (bit set/reset: CAPS, click, motor) y relectura de `0xAA`,
  portado del MSXimus.
- **Timing**: fusión del decodificador `A9/AA` y puerto 2 del PSG registrado (commit
  `4cb65a4`); paso a **Gowin 1.9.12.03**; `set_device -name`.
- **Fuera la cinta virtual** (`cas_stream`, `tape_uart`, `cas_player`, `tape_flash`,
  `tape_rom`, puertos `0x2C-0x2E`): el proyecto que la alimentaba se cayó. Pines 26 y 32
  libres. `CASIN` en reposo alto.
- `F11` cableado al turbo (`kbd_cmd_turbo` → `turbo <= ~turbo`).
- Fuera el guardián de versión menú ↔ core: el puerto `0x2F` vuelve solo para enseñar la
  versión en Ajustes, y el anuncio de versión de la Pico (`0xC0`) se consume y se descarta.
- Teclado RP2040: F6-F10 como en un MSX real, GRAPH en Alt izq./Windows, CODE en Alt
  der., STOP en F12.
- README reducido de 405 a 152 líneas: solo lo que hay.
- Assets de la release: `.fs` + `.bin`, los dos `.uf2`, `firmware_esp32c6_v2.0_merged.bin`.
  Dado del `.fs`: 999961.

## v1.9 — 10 de julio de 2026 · `0x19`

- **Solo MSX**: fuera la emulación de SG-1000/ColecoVision (`sn76489.v` borrado).
- **Turbo Panasonic WSX 5,369 MHz** con conmutación de cadencia *glitch-free* (F11 ya no
  cuelga); testbench `turbo_cadence_equiv`.
- Arreglo de la pantalla negra en *Save & Reset* con turbo (el boot-turbo solo en frío).
- Fuera el *Compatible Mode* vestigial del goauld (`config2` bit 3 queda libre).
- Guardián de versión menú ↔ bitstream por el puerto `0x2F`.
- Límite de 8 sprites por línea como ajuste (`config2` bit 4).
- Refresco de SDRAM ligado a `RFSH` (bucle de arranque resuelto).

## v1.8 — 29 de junio de 2026

- **ColecoVision y SG-1000** desde el menú (`.col`/`.sg`, SN76489). Retirado en la v1.9.
- **Metal Gear 2 arreglado** de verdad: el menú usaba el registro de parpadeo `R#13` para
  resaltar, que en V9938/V9958 fuerza la página 0 y anulaba el cambio de página del juego.
  El lanzador ahora restaura `R#12/R#13` y hace un `STOP` de comando antes del `INIT`.
- Logo de arranque (`logo16k` con magic `LG`, menú con `CALLF 8C:4002`).

## v1.7.1 — 13 de junio de 2026

- Corrección sobre v1.7: Konami4 en dos fases, `.dsk`, navegador, **Nextor 2.1.4** (desde
  aquí es la versión de referencia), SRAM, splash, arreglo del refresco del VDP.
- Limitación conocida entonces: MG2 glitcheaba al empezar (resuelto en v1.8).

## v1.7 — 11 de junio de 2026

- **Mapper Konami4** (registros en `6000/8000/A000`, banco 0 fijo, sin registros de modo:
  inmune a los *pokes* anticopia). Arregla Nemesis, Penguin Adventure y los Konami sin SCC,
  que nunca habían funcionado.
- Las ventanas del SCC (`9800/B800`) y su audio, exclusivas del modo SCC: un banco `0x3F`
  en Konami4/ASCII ya no abre el sonido por accidente.
- Búsqueda en el navegador y **forzado de mapper** (tecla M, etiquetas GoodMSX).
- **La saga MG2**: el sondeo de RAM de la BIOS escribía en `0x8000` de todos los slots y
  pisaba un registro de banco del Konami4 en modo por defecto → los juegos de dos fases
  entraban con el mapeo roto. Cerrojo anticopia en `7FFE` bit 7, `restore_palette`,
  `clock_108i` por `get_pins`.

## v1.6 — 10 de junio de 2026

- **Menú de arranque** completo: navegador de la SD estilo File-Hunter (pestañas
  ROM/DSK/ALL, nombres largos, subdirectorios), lanzar `.ROM` a la Megaram con detección
  de mapper, lanzar `.DSK` por emulación de Nextor (sin ficheros auxiliares), **FAT16 +
  FAT32** por partición (TAB cambia de partición).
- **SCC+ real** (SCC-I: ventana `B800`, registro `BFFE`, canal 5 con onda propia; lectura
  de la wave RAM arreglada) y **segundo SCC+** en el slot libre; **segundo PSG** en
  `0x10-0x12`.
- **Estéreo por HDMI**: PSG1+SCC1+OPLL a la izquierda, PSG2+SCC2+OPLL a la derecha.
- Timing: el dominio de 54 MHz cierra con margen positivo (constraints CDC del SPI del
  companion + *retime* del decodificador kanji).
- `fat32_emu_test.py`: intérprete Z80 para probar el menú en el PC.

## v1.5 — 4 de junio de 2026

- Primer menú de arranque (M2): navegador de SD, lanzador de ROMs, autofire.

## v1.3 — 31 de mayo de 2026

- Turbo por **F11** (F12 la capturaba el firmware del BL616).
- Teclas GRAPH y CODE/KANA.

## v1.2 — 31 de mayo de 2026

- **Reconstrucción sobre el core goauld standalone** (sin bus MSX debajo): BL616 para
  HID, LEDs discretos, HDMI, WiFi.
- **Estado de espera por M1** (`ENABLE_M1_WAIT`) → velocidad de MSX real (~100 %; antes
  116 %).
- **BIOS en un pack de flash** (`0x200000`) que se copia a la SDRAM al arrancar, en vez
  de empotrada en BSRAM (que estaba al 100 %); la ROM UNAPI del ESP va dentro. Pack fuera
  del repo (copyright).
- Configuración persistente en flash (`0x280000`, firma `AB`), heredada del OCM.
- Fuera los directorios de hardware del goauld (KiCad, PCBA).

## v1.1 — 27 de mayo de 2026

- WiFi con ESP-01S (MSX UNAPI).

## v1.0 — 27 de mayo de 2026

- Primera versión: MSX2+ en la Tang Nano 20K a partir del MSXgoauldSD de jabadiagm.

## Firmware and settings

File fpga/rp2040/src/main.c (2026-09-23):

#include <stdio.h>
#include "pico/stdlib.h"
#include "pico/multicore.h"
#include "hardware/timer.h"
#include "hardware/uart.h"
#include "bsp/board_api.h"
#include "tusb_config.h"
#include "class/hid/hid_host.h"
#include "usbin.h"

// ============== Defines ==============

#define KEYBOARD_REPORT_LEN 6

// ===== Status LED =====
// RP2040-Zero: on-board WS2812 (NeoPixel) on GPIO16, driven via PIO -- a plain
// gpio_put() cannot speak the 800kHz NeoPixel protocol. Raspberry Pi Pico: a
// plain mono LED on GPIO25. States (see the main loop):
//   boot                 -> blue blink (you can see it powered up)
//   idle (no USB kbd)     -> solid red
//   USB keyboard mounted  -> solid green
//   key pressed           -> brief white flash
//   USB mouse mounted     -> solid cyan
//   mouse moving          -> magenta flash
#ifndef RP2040_ZERO
#define RP2040_ZERO 1
#endif

// WS2812 PIO is needed both for the on-board NeoPixel (RP2040-Zero) and for the
// external status strip on the case -- include it unconditionally.
#include "hardware/pio.h"
#include "hardware/clocks.h"
#include "ws2812.pio.h"

// ---- External WS2812 status STRIP on the case (visible status bar) ----------
// Daisy-chained WS2812 on STRIP_PIN, driven by its own PIO state machine; all
// LEDs mirror the on-board status LED's colour (a bright bar). Wiring:
//   STRIP_PIN (GPIO26) -> strip DIN  (3.3V data, direct from the RP2040)
//   strip GND         -> common GND
//   strip +V          -> ~4.3V: one silicon diode (1N4007) from the MSX +5V.
//     The 4-7V strip's VIH (~0.7*Vcc) then sits below 3.3V, so it accepts the
//     RP2040's 3.3V data with NO level shifter. (5V direct also works on many
//     4-7V strips; add the diode only if colours glitch.)
#define STRIP_PIN   26    // GP26 (carrier redesign; UART link moved to GP15 via PIO)
#define STRIP_LEDS  8
static PIO  s_strip_pio  = pio0;
static uint s_strip_sm   = 1;     // on-board NeoPixel uses SM0; the strip uses SM1
static int  s_ws2812_off = -1;    // shared ws2812 program offset on pio0 (loaded once)

#if RP2040_ZERO
#define WS2812_PIN 16
static PIO  s_led_pio = pio0;
static uint s_led_sm  = 0;
static void status_led_init(void) {
    s_ws2812_off = pio_add_program(s_led_pio, &ws2812_program);
    ws2812_program_init(s_led_pio, s_led_sm, (uint)s_ws2812_off, WS2812_PIN, 800000.f, false);
}
// r,g,b in 0..255 -> WS2812 wants GRB, MSB-first, left-justified in 32 bits.
static inline void status_led_rgb(uint8_t r, uint8_t g, uint8_t b) {
    uint32_t grb = ((uint32_t)g << 16) | ((uint32_t)r << 8) | (uint32_t)b;
    pio_sm_put_blocking(s_led_pio, s_led_sm, grb << 8u);
}
#else
#define PICO_LED_PIN 25
static void status_led_init(void) {
    gpio_init(PICO_LED_PIN);
    gpio_set_dir(PICO_LED_PIN, GPIO_OUT);
}
// Pico has a single mono LED: lit for any non-black colour.
static inline void status_led_rgb(uint8_t r, uint8_t g, uint8_t b) {
    gpio_put(PICO_LED_PIN, (r | g | b) ? 1 : 0);
}
#endif

// Set up the external strip's PIO state machine. Reuses the ws2812 program that
// status_led_init() already loaded on RP2040-Zero; loads it itself on a plain
// Pico. Must be called AFTER status_led_init().
static void strip_init(void) {
    if (s_ws2812_off < 0)
        s_ws2812_off = pio_add_program(s_strip_pio, &ws2812_program);
    ws2812_program_init(s_strip_pio, s_strip_sm, (uint)s_ws2812_off, STRIP_PIN, 800000.f, false);
}
// Fill all STRIP_LEDS with one colour (used for the boot blink).
static inline void strip_rgb(uint8_t r, uint8_t g, uint8_t b) {
    uint32_t grb = ((uint32_t)g << 16) | ((uint32_t)r << 8) | (uint32_t)b;
    for (int i = 0; i < STRIP_LEDS; i++)
        pio_sm_put_blocking(s_strip_pio, s_strip_sm, grb << 8u);
}
// Push a per-LED frame (STRIP_LEDS colours packed as 0xRRGGBB) to the strip.
static inline void strip_push(const uint32_t *c) {
    for (int i = 0; i < STRIP_LEDS; i++) {
        uint8_t r = (uint8_t)(c[i] >> 16), g = (uint8_t)(c[i] >> 8), b = (uint8_t)c[i];
        uint32_t grb = ((uint32_t)g << 16) | ((uint32_t)r << 8) | (uint32_t)b;
        pio_sm_put_blocking(s_strip_pio, s_strip_sm, grb << 8u);
    }
}

#define BUF_COUNT   4

// Full-matrix resync cadence (microseconds). Self-heals any dropped event.
#define RESYNC_INTERVAL_US 250000ull

// ============== Global Variables ==============

tusb_desc_device_t desc_device;
uint8_t buf_pool[BUF_COUNT][64];
uint8_t buf_owner[BUF_COUNT] = { 0 };
uint8_t isMounted = 0;       // set by the HID mount/unmount callbacks (usbin.c)
uint8_t kb_leds = 0;
uint8_t kb_modifiers = 0;
// NKRO scratch sizing only (the event model uses its own internal state in
// usbin.c). Kept so the NKRO expansion in tuh_hid_report_received_cb is
// unchanged; kb_report_receive() caps the effective key count safely.
uint8_t kb_keys[120] = {0};

// ============== Core 1 ==============

void core1_entry() {
    while (1) {
        sleep_ms(200);
    }
}

// ============== Main ==============

int main() {
    // stdio is routed to USB-CDC only (PICO_STDIO_UART disabled in CMakeLists),
    // so this never touches uart0. Any DEBUG printf goes over USB-CDC.
    stdio_init_all();

    // Dedicated keyboard link: PIO UART TX on GP15 -> FPGA pin 31 (see usbin.c).
    // Must run AFTER stdio_init_all() so our explicit pin mux owns GP15.
    kb_uart_init();

    tusb_init();

    status_led_init();
    strip_init();          // external 8-LED status strip on the case (GPIO26)

    // Launch Core 1
    multicore_launch_core1(core1_entry);

#ifdef DEBUG
    printf("Firmware Boot Done\n");
#endif

    // Boot indicator: blink blue a few times so it is visibly alive.
    for (int i = 0; i < 3; i++) {
        status_led_rgb(0, 0, 40); strip_rgb(0, 0, 40); sleep_ms(120);
        status_led_rgb(0, 0, 0);  strip_rgb(0, 0, 0);  sleep_ms(120);
    }

    tuh_hid_set_default_protocol(HID_PROTOCOL_REPORT);

    uint64_t next_resync = time_us_64() + RESYNC_INTERVAL_US;
    uint32_t led_prev = 0xFFFFFFFFu;
    uint32_t strip_prev[STRIP_LEDS];
    for (int i = 0; i < STRIP_LEDS; i++) strip_prev[i] = 0xFFFFFFFFu;  // force first push

    while (1) {
        tuh_task();      // service USB host (fills the TX ring via callbacks)
        kb_tx_pump();    // drain TX ring into uart0 FIFO -- never blocks

        uint64_t now = time_us_64();

        joy_autofire_tick(now);   // advance autofire square wave + emit composed joy byte

        mouse_tick(now);          // vuelca el acumulador del raton a 100 Hz (0xD0)

        // Periodic full-matrix resync (also self-heals any dropped byte).
        if ((int64_t)(now - next_resync) >= 0) {
            kb_send_resync();
            joy_send_resync();   // re-emit both MSX joystick ports (0xB0 frames)
            kb_tx_pump();
            next_resync = now + RESYNC_INTERVAL_US;
        }

        // ---- LED de a bordo: un color por prioridad ----------------------
        //   magenta parpadeo = el RATON esta mandando informes (se mueve)
        //   cian fijo        = raton MONTADO pero sin informes  <- diagnostico
        //   blanco parpadeo  = actividad de teclado/joystick
        //   amarillo         = gamepad montado
        //   verde            = teclado montado
        //   rojo             = nada montado
        // Los dos primeros separan las DOS cosas que pueden fallar con un raton:
        // que no llegue a montarse, o que se monte y no mande nada (que era el
        // fallo del 03/09: el SET_PROTOCOL invalidaba la peticion de informe).
        uint32_t led;
        if      ((uint64_t)(now - g_last_mouse_us) < 70000ull && g_mouse_mounted)
                                                             led = 0x200020u;  // magenta: raton moviendose
        else if ((uint64_t)(now - g_last_key_us) < 70000ull)  led = 0x202020u;  // blanco: actividad
        else if (g_mouse_mounted)                            led = 0x002020u;  // cian: raton montado
        else if (g_joy_mounted)                              led = 0x141400u;  // amarillo: gamepad
        else if (isMounted)                                  led = 0x002000u;  // verde: teclado
        else                                                 led = 0x1A0000u;  // rojo: nada
        if (led != led_prev) {
            status_led_rgb((uint8_t)(led >> 16), (uint8_t)(led >> 8), (uint8_t)led);
            led_prev = led;
        }

        // ---- Case strip: an 8-LED panel, each LED a different signal --------
        //  [0] power red (always)      [1] keyboard blue (mounted)
        //  [2] joystick yellow (mounted) [3] typing white (key flash)
        //  [4] fire A green             [5] fire B magenta   (both blink at 10Hz on autofire)
        //  [6] direction cyan (any dir) [7] heartbeat dim-green (~1Hz, "alive")
        uint8_t  joy    = g_joy_out;
        bool     typing = (uint64_t)(now - g_last_kbd_us) < 90000ull;
        uint32_t f[STRIP_LEDS];
        f[0] = 0x140000u;                                                          // power: red
        f[1] = g_kbd_mounted ? 0x000018u : 0;                                      // keyboard: blue
        f[2] = g_joy_mounted ? 0x141400u : 0;                                      // joystick: yellow
        f[3] = typing ? 0x101010u : 0;                                             // typing: white
        f[4] = (joy & JOYO_A) ? 0x001400u : 0;                                     // fire A: green
        f[5] = (joy & JOYO_B) ? 0x140014u : 0;                                     // fire B: magenta
        f[6] = (joy & (JOYO_UP|JOYO_DOWN|JOYO_LEFT|JOYO_RIGHT)) ? 0x001414u : 0;   // direction: cyan
        f[7] = ((now / 500000ull) & 1ull) ? 0x000600u : 0;                         // heartbeat: ~1Hz dim green
        bool strip_changed = false;
        for (int i = 0; i < STRIP_LEDS; i++) if (f[i] != strip_prev[i]) strip_changed = true;
        if (strip_changed) {                       // send-on-change: crisp blinks, PIO not flooded
            strip_push(f);
            for (int i = 0; i < STRIP_LEDS; i++) strip_prev[i] = f[i];
        }
    }

    return 0;
}

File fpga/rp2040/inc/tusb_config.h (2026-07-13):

/* 
 * The MIT License (MIT)
 *
 * Copyright (c) 2019 Ha Thach (tinyusb.org)
 *
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
 */

#ifndef _TUSB_CONFIG_H_
#define _TUSB_CONFIG_H_

#ifdef __cplusplus
 extern "C" {
#endif

#define CFG_TUSB_MCU          OPT_MCU_RP2040
#define CFG_TUSB_RHPORT0_MODE OPT_MODE_HOST

#ifndef CFG_TUSB_OS
#define CFG_TUSB_OS           OPT_OS_PICO
#endif

#ifndef CFG_TUH_MEM_SECTION
#define CFG_TUH_MEM_SECTION
#endif

#ifndef CFG_TUH_MEM_ALIGN
#define CFG_TUH_MEM_ALIGN        __attribute__ ((aligned(4)))
#endif

#define CFG_TUH_ENUMERATION_BUFSIZE 2048  // was 256; some HID gamepads have large report descriptors

#define CFG_TUH_HUB                 2
#define CFG_TUH_DEVICE_MAX          6

#define CFG_TUH_HID                 16
#define CFG_TUH_XINPUT              1   // Ryzee119 XInput host driver: number of XInput pads (Xbox / dongles)
#define CFG_TUH_HID_EPIN_BUFSIZE    128 // default 64
#define CFG_TUH_HID_EPOUT_BUFSIZE   128 // default 64

#define CFG_TUSB_HOST_DEVICE_MAX    (CFG_TUH_HUB ? 5 : 1) // normal hub has 4 ports
#define CFG_TUH_CDC                 1
#define CFG_TUH_HID_KEYBOARD        1
#define CFG_TUH_HID_MOUSE           0
#define CFG_TUH_MSC                 1  // Enable Mass Storage
#define CFG_TUSB_HOST_HID_GENERIC   0  // (not yet supported)

#ifdef __cplusplus
}
#endif

#endif /* _TUSB_CONFIG_H_ */

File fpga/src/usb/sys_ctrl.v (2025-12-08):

/*
    sysctrl.v
 
    generic system control interface from/via the MCU

    TODO: This is currently very core specific. This needs to be
    generic for all cores.
*/

module sysctrl (
  input		    clk,
  input		    reset,

  input		    data_in_strobe,
  input		    data_in_start,
  input [7:0]	    data_in,
  output reg [7:0]  data_out,

  // interrupt interface
  output	    int_out_n,
  input [7:0]	    int_in,
  output reg [7:0]  int_ack,

  input [1:0]	    buttons, // S0 and S1 buttons on Tang Nano 20k

  output reg [1:0]  leds, // two leds can be controlled from the MCU
  output reg [23:0] color, // a 24bit color to e.g. be used to drive the ws2812

  // IO port interface
  input	[31:0]	    port_status,         // status bits to report additional info about the port
  input	[7:0]	    port_out_available,  // number of bytes available for transmission to MCU
  output reg	    port_out_strobe,
  input [7:0]	    port_out_data,
  input	[7:0]	    port_in_available,   // number of unused bytes in the input buffer
  output reg	    port_in_strobe,
  output reg [7:0]  port_in_data,
		
  // values that can be configured by the user
  output reg [1:0]  system_chipset,
  output reg	    system_memory,
  output reg	    system_video,
  output reg [1:0]  system_reset,
  output reg [1:0]  system_scanlines,
  output reg [1:0]  system_volume,
  output reg	    system_wide_screen,
  output reg [1:0]  system_floppy_wprot,
  output reg	    system_cubase_en,
  output reg [1:0]  system_port_mouse,
  output reg	    system_tos_slot
);

reg [3:0] state;
reg [7:0] command;
reg [7:0] id;
   
// reverse data byte for rgb   
wire [7:0] data_in_rev = { data_in[0], data_in[1], data_in[2], data_in[3], 
                           data_in[4], data_in[5], data_in[6], data_in[7] };

// coldboot flash and system interrupt   
reg coldboot = 1'b1;   
reg sys_int = 1'b1;

// registers to report button interrupts
reg [1:0] buttonsD, buttonsD2;
reg	  buttons_irq_enable;
   
// the system cobtrol interrupt or any other interrupt (e,g sdc, hid, ...)
// activates the interrupt line to the MCU by pulling it low
assign int_out_n = (int_in != 8'h00 || sys_int)?1'b0:1'b1;
   
reg       port_out_availableD;
reg [7:0] port_cmd;   
reg [7:0] port_index;

   
// process mouse events
always @(posedge clk) begin
   if(reset) begin
      state <= 4'd0;      
      leds <= 2'b00;        // after reset leds are off
      color <= 24'h000000;  // color black -> rgb led off

      buttons_irq_enable <= 1'b1;  // allow buttons irq
      int_ack <= 8'h00;
      coldboot = 1'b1;      // reset is actually the power-on-reset
      sys_int = 1'b1;       // coldboot interrupt

      port_out_strobe <= 1'b0;
      port_in_strobe <= 1'b0;
      
      // OSD value defaults. These should be sane defaults, but the MCU
      // will very likely override these early
      system_chipset <= 2'd0;       // regular ST
      system_memory <= 1'b0;        // 4 MB
      system_video <= 1'b0;         // color
      system_scanlines <= 2'b00;    // no scanlines
      system_volume <= 2'b00;       // mute
      system_wide_screen <= 1'b0;   // normal video 
      system_floppy_wprot <= 2'b00; // floppy not write protected
      system_cubase_en <= 1'b0;     // no cubase dongle
      system_port_mouse <= 2'b00;   // mouse on usb -> db9 joystick
      system_tos_slot <= 1'b0;      // primary tos slot
   end else begin // if (reset)
      //  bring button state into local clock domain
      buttonsD <= buttons;
      buttonsD2 <= buttonsD;
      
      int_ack <= 8'h00;
      port_out_strobe <= 1'b0;
      port_in_strobe <= 1'b0;

      // iack bit 0 acknowledges the system control interrupt
      if(int_ack[0]) sys_int <= 1'b0;      
            
      // (further) data has just become available, so raise interrupt
      port_out_availableD <= (port_out_available != 8'd0);
      if(port_out_available && !port_out_availableD)
	sys_int <= 1'b1;
      
      // monitor buttons for changes and raise interrupt
      if(buttons_irq_enable) begin
        if(buttonsD2 != buttonsD) begin
            // irq_enable prevents further interrupts until
            // the button state has actually been read by the MCU
            sys_int <= 1'b1;
            buttons_irq_enable <= 1'b0;
        end
      end

      if(data_in_strobe) begin
        if(data_in_start) begin
           state <= 4'd0;
           command <= data_in;
	   data_out <= 8'h00;
        end else begin
            if(state != 4'd15) state <= state + 4'd1;
	    
            // CMD 0: status data
            if(command == 8'd0) begin
                // return some pattern that would not appear randomly
	        // on e.g. an unprogrammed device
                if(state == 4'd0) data_out <= 8'h7c;
                if(state == 4'd1) data_out <= 8'h42;
                if(state == 4'd2) data_out <= 8'h10;   // core id 0 = Generic core
            end
	   
            // CMD 1: there are two MCU controlled LEDs
            if(command == 8'd1) begin
                if(state == 4'd0) leds <= data_in[1:0];
            end

            // CMD 2: a 24 color value to be mapped e.g. onto the ws2812
            if(command == 8'd2) begin
                if(state == 4'd0) color[15: 8] <= data_in_rev;
                if(state == 4'd1) color[ 7: 0] <= data_in_rev;
                if(state == 4'd2) color[23:16] <= data_in_rev;
            end

            // CMD 3: return button state
            if(command == 8'd3) begin
               data_out <= { 6'b000000, buttons };
	       // re-enable interrupt once state has been read
               buttons_irq_enable <= 1'b1;
            end

            // CMD 4: config values (e.g. set by user via OSD)
            if(command == 8'd4) begin
                // second byte can be any character which identifies the variable to set 
                if(state == 4'd0) id <= data_in;
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

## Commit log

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2026-05-27 Fix joystick bit mapping: Right/Left/Down/Up order from companion
    Firmware sends: bit0=Right, bit1=Left, bit2=Down, bit3=Up, bit4=A, bit5=B
    MSX PSG Port A: bit0=Up, bit1=Down, bit2=Left, bit3=Right, bit4=TrigA, bit5=TrigB
    Previous mapping was wrong (assumed Up=bit0 instead of Right=bit0).
    [top.v]
2026-05-27 Fix heartbeat LED: use clk_54m+clk_enable instead of posedge clk_enable as clock
    [top.v]
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2026-05-31 v1.2: rebuild on goauld standalone core + authentic M1 wait-state (~100% MSX)
    - Replace nano-based core with the goauld-derived standalone (USB BL616 HID
    keyboard/joystick, discrete LEDs, HDMI, WiFi) — no MSX bus dependency.
    - Add per-M1 opcode-fetch wait-state -> ~100% real-MSX speed (was ~116%).
    Toggleable via `define ENABLE_M1_WAIT in fpga/top.v.
    - WiFi UART tx pin 79->73 to match wiring diagram (rx stays 77).
    - WiFi UNAPI ROM (esp8266e) integrated into the 0x200000 BIOS pack.
    - README: flashing updated to the monolithic BIOS pack @0x200000.
    - Drop goauld hardware dirs (kicad/pcba/production) — standalone only.
    - BIOS pack gitignored (copyright); build locally with src/rom/build.b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
    [device.cfg]
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2026-05-31 docs(BOM): add purchase links (AliExpress) + fix typos (Micro, USB-C)
    [MSXnano_BOM.xlsx]
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2026-06-04 Menu M2: arranque rapido a juego + marquee de nombres largos
    - .br_selrom simplificado: seleccionar ROM -> carga directa a megaram
    (barra de progreso) y ofrece RETURN=LANZAR. Sin volcado de bytes ni
    verificacion seg0/seg1 (debug fuera). Mapper por tag del nombre primero
    y solo escaneo de codigo si no hay tag (mas rapido).
    - Fix marquee: NAME_MAX 56->72, ENT_SIZE 64->80, MAX_ENT 144->115. Los
    nombres largos ahora se guardan completos (>59 = ancho de ventana) y
    el marquee horizontal del seleccionado vuelve a desplazarse.
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2026-06-06 Menu M2: restyle estilo File-Hunter + fixes .dsk/ESC
    UI (TEXT2, mismo modo, sin cambios de FPGA):
    - Barra de tabs [R]OM/[D]SK/[A]LL con filtro por tipo (re-escaneo); tab
    activo resaltado en inverso (tabla de blink R12).
    - Seleccion inversa a fila completa (la fila bajo el cursor).
    - Lineas finas con glifo de fuente redefinido (char 0x10 en la tabla de
    patrones, recargado tras cada INITXT; dibujado directo en la name table).
    - Contador sel/total en la linea inferior.
    - Lista sin tags [ROM]/[DSK]; carpetas muestran [DIR] en la columna derecha.
    - Refresco SUAVE (sin cls/INITXT, sin parpadeo) al filtrar, entrar/salir de
    carpeta y cambiar de particion; limpia el blink de filas vacias.
    - Rel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
2026-06-06 bin: restore autofire bitstream (bin/msxnano.fs was 0 bytes)
    The v1.5 commit left bin/msxnano.fs empty (the asset upload failed for that
    reason). Restore the real autofire FPGA core (joystick buttons 3/4 autofire),
    identical to fpga/impl/pnr/project.fs, so the testing branch carries the
    correct bitstream. Menu/M2 changes are software (BIOS pack), no FPGA rebuild.
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2026-06-11 v1.7: Konami4 mapper, two-stage Konami launch fix, browser search + mapper override
    FPGA (megaram.v / top.v):
    - new Konami4 mode (map_sel=00, selected via SWIO smart command #0D):
    bank registers at 6000/8000/A000, bank 0 fixed, no mode registers
    (pure-ROM behaviour, immune to Konami anti-copy pokes). Fixes plain
    Konami games (Nemesis 1, Penguin Adventure, ...) which never worked:
    the megaram only decoded the SCC-mapper registers
    - SCC wave windows (9800/B800) and SCC audio now exclusive to the SCC
    mode: a 0x3F bank in Konami4/ASCII modes no longer opens the sound
    window by accident
    Menu:
    - launcher CALLs the cartridge INIT like the BIOS and, if the game
    hooked H.STKE and retur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
    [megaram.v, top.v]
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2026-06-12 megaram: blindaje del lanzamiento de juegos (regresion MG2 v1.7)
    - Cerrojo anti-anticopia (mode_a bit7): el menu lo echa al lanzar y sella
    los registros de modo 7FFE/BFFE hasta el proximo reset; los pokes de
    deteccion de MegaRAM de los juegos Konami (MG2 escribe BFFE=FF en su
    test de RAM) ya no pueden congelar el mapper ni abrir la escritura.
    - ff_scc_mode / ff_sram_mode: las condiciones de modo (map_sel/sram_cfg,
    estaticas durante el juego) entran registradas al decodificador en vez
    de alargar el cono combinacional hacia el controlador SDRAM.
    - SDC: reloj interno de 108MHz por fin definido (get_pins del CLKOUT del
    PLL; la red clk_108m no existe tras sintesis) -- pone bajo analis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
    [megaram.v]
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2026-06-13 memory: el refresh SDRAM no roba slots de ESCRITURA del VDP
    El refresh de la SDRAM (disparado por RFSH del Z80) se hacia en el slot
    del VDP (video_dlclk==1) de forma incondicional. El VDP da ACK de sus
    escrituras sin esperar confirmacion de memory.v (fire-and-forget,
    sincronizado solo por video_dlclk compartido), asi que cuando refresh y
    una escritura VDP coincidian en el mismo slot, la escritura se perdia.
    Las lecturas de display perdidas se recuperan al frame siguiente
    (invisible), pero las ESCRITURAS (comando del blitter / acceso CPU por
    puerto) dejan agujeros permanentes en VRAM -> linea fina de basura en la
    intro de Space Manbow. Fix: el refresh solo roba el slot VDP si NO hay
    escritura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
    [memory.v]
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2026-06-14 console mode: SG-1000 + ColecoVision launchable from the boot menu
    A new 'console mode' (volatile register at port #44; physical reset
    returns to MSX) turns the whole Z80 memory map and I/O into a Sega
    console, with the game living in the megaram:
    FPGA:
    - sn76489.v: new SN76489 PSG core (3 square + LFSR noise, latch/data
    protocol, 2dB attenuation table), mixed into both HDMI channels
    - megaram.v: console memory maps. SG-1000: 0000-BFFF linear ROM
    (segments 0+), C000-FFFF 8KB RAM (segment 249, mirrored). Coleco:
    BIOS segment 250, 1KB RAM mirrored at 6000-7FFF, cart segments 0-3.
    Writes only land in the RAM regions; bank/mode registers disabled
    - top.v: in console mode every MSX respo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
    [megaram.v, top.v]
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2026-07-03 filehunter: FIX RAIZ del fallo en frio = retraso de power-on en la FPGA
    El re-init por software (#4010 desde el menu) COLGABA (contexto de
    pantalla/interrupciones distinto al del boot) -> revertido a fallo limpio
    y el diagnostico U ahora imprime H:<hokvld> N:<implementaciones> antes de
    decidir (distingue hook ausente vs driver 'sin ESP').
    FIX REAL en top.v: el INIT del driver ESP corre en el escaneo de slots
    ~1-2s tras dar corriente, pero el ESP-01S tarda ~3-5s en arrancar ->
    quedaba instalado 'sin ESP' hasta re-init manual (setup W). Nuevo
    contador de power-on (clk_27m, satura en ~3s) que retiene el Z80 en
    reset SOLO en el arranque en frio: el ESP esta listo cuando el INIT lo
    sondea. Los s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
    [top.v]
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2026-07-10 v1.9: MSX-only cleanup + turbo robustness
    Elimina SG-1000/ColecoVision (RTL + menu):
    - top.v: fuera console_mode (35 gates a MSX, INT/NMI/decode-VDP/scc2
    simplificados, puerto #44 fuera, bloque HW SN76489/gamepad/keypad/pausa
    borrado); megaram.v: mapa de memoria de consola fuera; sn76489.v BORRADO
    y quitado de build.tcl; menu: fuera deteccion .SG/.COL, launch, COLECO.ROM
    y strings (navegador solo ROM/DSK). Testbench megaram: 24 checks PASS.
    Turbo WSX 5.37MHz - conmutado de cadencia SIN glitch:
    - turbo_eff adopta turbo solo en un limite de T-estado limpio (ambas
    cadencias bajas Y CPU sin wait) -> arregla el cuelgue de F11 en el menu
    (el mux asincrono entregaba dos ENABLE/FALLING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
    [megaram.v, top.v]
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2026-07-11 memory: guardia anti-inanicion del refresh (fix cuelgue video en turbo Screen 2)
    Portado de MSXimus (commit 8b2d33c, verificado en sim T8). CAUSA: el fix MG2
    del refresh ("saltar el slot de refresh si vram_write==1") usa el NIVEL sostenido
    de ~WeVdp_n; en modos de escritura VDP continua (Screen 3 multicolor; Screen 2 en
    TURBO, donde el CPU escribe VRAM mas rapido) ese nivel se queda activo -> el refresh
    se muere de hambre -> la SDRAM se descarga -> cuelgue a los pocos segundos con el
    CPU ejecutando basura. El VDP esta exonerado (goauld sin la condicion = inmune):
    el delta es el arbitro SDRAM. FIX: rfsh_skip_cnt cuenta oportunidades de refresh
    saltadas por vram_write y FUERZA el refresh a los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
    [memory.v]
2026-07-11 top.v: Boot Turbo tambien en Save&Reset (revertir workaround boot-turbo-solo-en-frio)
    La pantalla-negra del warm-boot-turbo era la INANICION DE REFRESH de la SDRAM
    (misma raiz que el cuelgue de Screen 2/3 en turbo), ya arreglada en memory.v
    (rfsh_skip_cnt, commit f822c1d, confirmado en HW). Con eso, los workarounds ya
    no hacen falta:
    - quitado `boot_done`: config_init vuelve a aplicar el Boot Turbo en CUALQUIER
    reset (frio Y warm) -> activar Boot Turbo + Save&Reset ya arranca a 5.37.
    - quitado `warm_reset_pending`: el CPU cruza el reset a la cadencia normal; el
    turbo_eff sigue siendo glitch-free (conmuta en borde cadence_safe & wait_io &
    wait_m1, el fix del cuelgue de F11 -> se conserv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
    [top.v]
2026-07-11 top.v: Boot Turbo en Save&Reset (restaurar warm_reset_pending, SIN boot_done)
    El par 27 (sin ninguno de los dos) volvia a dar pantalla negra en warm-reset-con-
    turbo -> confirma que la negra NO era (solo) la inanicion de refresh, sino cruzar
    el reset / arrancar directo a 5.37 en warm (el warm reset no tiene el hold ~3s del
    esp_boot_ok que el cold boot usa para asentar; por eso el power-cycle SI arranca en
    turbo). SOLUCION = warm_reset_pending (cruza el reset a 3.58 + asienta ~0.4s del
    monostable) PERO sin boot_done: config_init deja `turbo`=boot-turbo, asi que al
    expirar el hold turbo_eff conmuta a 5.37 SOLO (como un F11, glitch-free) -> arranca
    a 3.58 medio segundo y salta a turbo. No mas n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
    [top.v]
2026-07-11 turbo: descartar Boot-Turbo en Save&Reset; nota "(reiniciar fisicamente)" en menu
    La pantalla negra al hacer Save&Reset con turbo ocurre en la ENTRADA del reset con
    el CPU a 5.37 MHz (grabacion de config a flash + cruce del reset), no al re-arrancar,
    asi que ningun ajuste del lado del boot (boot_done/warm_reset_pending/warm_boot) lo
    cura. top.v vuelve al baseline glitch-free de turbo_eff (adopta `turbo` solo en un
    limite de T-estado limpio). El Boot-Turbo se aplica solo en arranque fisico (cold,
    via config_init); el menu avisa "(reiniciar fisicamente)" en la fila de Boot Turbo.
    .gitignore: proteger el pack goauld_rom_int_*.bin (copyright) y gowin_build*.log.
    [top.v]
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2026-07-13 feat(cinta-virtual): cinta virtual de cassette validada en HW
    Modulador KCS en la FPGA que genera CMTIN (PSG reg14 bit7): la BIOS
    real carga RUN"CAS:" sin hacks. Probado en Tang Nano 20K -> Found +
    "CINTA VIRTUAL OK".
    - cas_player.v: FSM modulador KCS (one=731 / zero=1463 T-states), lee
    imagen CVT1 por byte, gated por ce=clk_enable_3m6_54.
    - tape_rom.v: imagen de cinta en BSRAM ($readmemh), test de 286 bytes.
    - top.v: 3 enganches -> inyeccion reg14 bit7, captura de motor por
    OUT (0xAB) bit set/reset de PC4, load/rebobinado por flanco.
    - build.tcl: add_file cas_player.v + tape_rom.v.
    Prueba de concepto (BSRAM, cintas pequenas). Siguiente: imagen en
    SDRAM para juegos reales.
    [top.v]
2026-07-13 fix(cinta-virtual): bancos BSRAM explicitos + monitor de carga (audio+LED)
    Escalado del test de 286B al juego real 1x2 (18250B, 7 bloques). El primer
    intento en HW cargo el cargador ASCII (Found/Ok/CLOAD/Found) pero el bloque
    de 16.5KB nunca llegaba: todo lo que funcionaba vivia en el PRIMER primitivo
    BSRAM (<2KB). La sim Icarus de la imagen completa exonera a cas_player
    (payload de 18216B byte-exacto, congelacion por motor sin perdidas), asi que
    el fallo apunta al init multi-BSRAM de $readmemh en la sintesis de Gowin.
    - tape_rom.v: troceado en 9 bancos explicitos de 2KB (1 BSRAM + $readmemh
    cada uno) — replica el patron de 1 primitivo ya validado en placa.
    Latencia 2 clks (registro B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
    [top.v]
2026-07-14 diag(cinta-virtual): puerto I/O 0x2C/0x2D para leer tape_rom desde el Z80
    Toda la cadena esta verificada en local (CVT=CAS byte-exacto, cas_player y
    tape_rom de bancos byte-exactos en sim con los hex reales, stream KCS
    demodulable) — la unica capa sin observar es el contenido fisico de los BSRAM
    que sintetiza Gowin. Este puerto la expone: OUT &H2C/&H2D fija direccion,
    INP(&H2C) lee byte con autoincremento, INP(&H2D) da el byte alto de la
    posicion viva de la cinta. diag_active desvia la ROM al Z80 hasta el reset.
    [top.v]
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2026-07-15 pico-companion: usar el firmware/modulo CORRECTOS de MSXgoauldSD v1.3 (GP15 PIO-UART)
    El import inicial trajo por error la variante vieja (MSXgoauldSD_tn20k): UART HW en
    GP0 y kbd_uart_rx.v que NO decodifica el announce de version 0xC0<ver>. El UF2 que
    se va a flashear es el de v1.3, que:
    - manda el enlace por PIO-UART en GP15 (los UART HW del RP2040 no llegan a GP15),
    - tira WS2812 en GP26 (GP27 libre), LED on-board GP16,
    - antepone 0xC0<FW_VERSION> en cada resync (version-guard).
    Cambios:
    - fpga/src/kbd_uart_rx.v -> modulo de v1.3 (md5 066a0390): consume 0xC0<ver> (no
    inyecta teclas fantasma) y anade cmd_turbo_toggle (F11) + salida fw_version.
    - top.v: instancia con .fw_version() y .cmd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
    [kbd_uart_rx.v, main.c, top.v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]
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2026-07-16 feat(cinta-virtual): integrar la cinta por STREAM en top.v (pines 26/32)
    - Puertos nuevos: tape_rx (pin 26, PULL UP: sin C6 no hay bytes fantasma) y
    tape_rtr (pin 32, flow control por nivel al GPIO del C6).
    - El backend de cinta pasa de tape_flash (bloqueado, build 9) a
    tape_uart -> cas_stream: el C6 baja el .tsx, lo convierte a CVS1 y lo
    streamea; FIFO 2KB = ~18s de cinta; el RTR gatea el TX del C6.
    - Se REUTILIZA sin tocar lo validado en HW: motor OUT(0xAB)/PC4, armado
    auto tras reset + re-arme al acabar (el FSM espera la magia CVS1 en
    S_RD), casin -> PSG PortA bit7.
    - Diag de bring-up reciclado: INP(&H2C) = primeros 16 bytes consumidos
    (esperar "CVS1" = 43 56 53 31); INP(&H2D)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
    [top.v]
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2026-07-16 fix(merge): quitar .dbg_state() de flash1 (puerto solo existia en el worktree cinta sin commitear); build unificado OK
    Imagen unificada compila: 0 errores, clk_54m 54.367 MHz (cumple), CLS 89%,
    pines 26 (tape_rx) + 29 (turbo_status) + 31 (kbd Pico) + 32 (tape_rtr).
    [top.v]
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2026-08-26 PPI: portado del MSXimus el arreglo de ABh + la relectura de AAh (CAPS y click)
    Aqui faltaban las MISMAS dos cosas que se cazaron en el MSXimus el 26/08 y se
    validaron en placa (commit 565ed77 de aquel repo):
    1. ABh (bit set/reset del 8255) solo se decodificaba para el BIT 4, el motor del
    casete. Los bits 6 (LED de CAPS) y 7 (click de tecla) no llegaban nunca. El
    comentario que habia lo delataba: "se rastrea aparte porque el core solo
    capturaba 0xAA, NO 0xAB". Se arreglo el motor sin ver que el agujero era
    general.
    2. AAh no se podia RELEER, y esa es la causa de raiz. La BIOS relee el puerto C
    para cambiar de fila de teclado (IN A,(0AAh) / AND 0F0h / OR fila /
    OUT (0AAh),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
    [top.v]
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2026-08-26 top.v: fuera dos identificadores declarados por duplicado (uno bloqueaba el raton)
    Los dos los delataba Icarus y llevaban ahi desde siempre, invisibles porque Gowin
    no se queja:
    * `psgPB` estaba declarado como `wire [7:0]` (1697) Y COMO `reg` DE 1 BIT (1704).
    Mismo nombre, ancho 1 contra 8: la sintesis se queda con uno de los dos y no te
    lo dice. Hasta hoy daba igual porque nadie usaba la senal fuera de la propia
    instancia del PSG -- pero el raton MSX necesita `psgPB[5]` (el pin 8 del puerto
    de joystick 2), y sobre un reg de 1 bit no habria funcionado NUNCA. Es decir:
    esto no es limpieza, es el prerequisito del raton.
    El MSXimus ya lo habia cazado y arreglado igual ("niquelado B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
    [top.v]
2026-08-26 Raton MSX en el MSXnano: RTL completo, servido por el RP2040 (mensaje 0xD0)
    El raton MSX no es de cuadratura: es "inteligente" y habla por handshake con el
    pin 8 del puerto de joystick, presentando cuatro nibbles por los bits 0-3 del
    puerto A del PSG. Todo eso ya estaba resuelto en el MSXimus y VALIDADO EN PLACA,
    asi que se porta tal cual en vez de reescribirlo.
    QUE ENTRA
    * fpga/src/msx_mouse.v (206 lineas) + su banco tools/mouse_sim/tb_msx_mouse.sv,
    copiados del MSXimus. El banco pasa aqui tambien: 7 pruebas, 0 errores.
    * kbd_uart_rx.v aprende el mensaje **0xD0 <dx> <dy> <btn>** (4 bytes). Habia
    hueco: el protocolo usaba 0x80/0x90/0xA0/0xB0/0xC0/0xFE y 0xD0 estaba libre.
    Es ADITIVO,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
    [kbd_uart_rx.v, top.v]
2026-08-26 RP2040: leer el raton USB y mandarlo por el mensaje 0xD0
    Completa el lado que faltaba: la FPGA ya sabe recibir 0xD0 <dx> <dy> <btn>, y
    esto es quien lo emite.
    COMO SE RECONOCE EL RATON
    Por el protocolo de interfaz (HID_ITF_PROTOCOL_MOUSE), sin registro aparte como
    el de los gamepads: los ratones SI se anuncian correctamente, los mandos no.
    Al montarlo se le pide protocolo BOOT, con lo que el informe es siempre de 3
    bytes fijos -- [botones][dx][dy] -- y nos ahorramos interpretar descriptores.
    Todos los ratones soportan BOOT.
    SE ACUMULA, NO SE MANDA EN CADA INFORME
    Un raton de oficina informa a 125 Hz, pero uno "gaming" puede ir a 1000, y a 4
    bytes por informe serian 4 KB/s de los 11,5 que d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
    [main.c, usbin.c]
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2026-08-26 timing: devolver clk_54m a verde -- y con MAS margen del que habia antes
    MEDIDO, no estimado. Cuatro campanas con el mismo Gowin 1.9.11.03:
    referencia (633e58e, sin nada mio) 54,367 MHz +0,367 PASA (por los pelos)
    + arreglo del PPI 44,642 MHz -9,358 FALLA 26 endpoints
    + PPI + raton 44,242 MHz -9,758 FALLA 33 endpoints
    + mux fusionado 53,953 MHz -0,047 FALLA 2 endpoints
    + puerto 2 registrado 58,921 MHz +4,921 PASA <-- este
    LO QUE HABIA ROTO YO, Y POR QUE
    El mux de lectura del cpu_din es una cadena de prioridad larguisima que ya iba
    con 20 ns de camino contra 18,2 disponibles. L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
    [top.v]
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2026-09-03 teclado: F6..F10 como en un MSX de verdad, GRAPH en Windows y STOP en F12
    Peticion de Albert tras probar en placa: las teclas de funcion altas no hacian
    lo que uno espera.
    Como estaban (y por que no era un bug, sino el diseno heredado):
    F6 -> celda de STOP F7 -> celda de GRAPH
    F8/F9/F10 -> comandos 0x01/0x03 que en top.v estan SIN CABLEAR = no-op
    F12 -> comando 0x02 (reset), tambien sin cablear = no-op
    Ahora:
    F6..F10 -> SHIFT + F1..F5, que es lo que son en un MSX (no tienen celda
    propia en la matriz). keymaps.h las mapea a la celda de F1..F5 y
    usbin.c SINTETIZA el SHIFT alrededor.
    GRAPH -> ademas del Alt izquierdo, LAS DOS TECLAS WINDOWS. El Alt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
    [usbin.c]
2026-09-03 F11 del Pico cableado al turbo, y el raton arreglado (orden de SET_PROTOCOL)
    RTL (top.v): el puerto .cmd_turbo_toggle de ukbd estaba SIN CONECTAR desde la
    v1.9c, que quito F11 de los dos teclados por timing. Se cablea: wire
    kbd_cmd_turbo + toggle del reg turbo, puesto ANTES del puerto Panasonic para que
    el software siga mandando si coinciden en el mismo ciclo.
    El commit 2545373 (julio) ya lo intento y quedo BLOQUEADO: clk_54m iba a
    54,195 con 0,195 de margen y el mux lo tiraba a 46 MHz. Pedia "liberar
    headroom antes de entrar". El arreglo de timing del 02/09 (4cb65a4) lo libero
    y ahora ENTRA: clk_54m cierra a 54,857 (+0,857) y el gate pasa.
    🚨 Pero se come casi todo el margen: s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
    [top.v, usbin.c]
2026-09-03 LED de a bordo del Pico: cian = raton montado, magenta = raton moviendose
    Peticion de Albert para diagnosticar por que el raton no aparece: que el LED
    integrado de la RP2040-Zero diga algo del raton, como ya dice verde cuando hay
    teclado. Separa las DOS cosas que pueden fallar, que hasta ahora no se podian
    distinguir desde fuera:
    cian FIJO -> el raton se MONTO (tuh_hid_mount_cb lo vio)
    magenta PARPADEO-> estan LLEGANDO informes (se esta moviendo)
    blanco parpadeo -> actividad de teclado/joystick (como antes)
    amarillo/verde/rojo -> gamepad / teclado / nada (como antes)
    Asi, al enchufar el raton: si NO se pone cian, no se monta (problema de USB o de
    hub); si se pone cian pero al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
    [main.c, usbin.c]
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2026-09-03 RATON FUNCIONANDO: el puerto 2 del PSG exigia un bit que no es el selector
    VALIDADO EN PLACA el 03/09. El bug llevaba ahi desde el goauld y no solo mataba
    el raton: EL JOYSTICK DEL JUGADOR 2 TAMPOCO SE LEIA NUNCA.
    Roto: (!joy_sel[0]) ? puerto1 : (!joy_sel[1]) ? puerto2 : 8'hFF
    joy_sel = reg15[7:6], o sea que para leer el puerto 2 exigia que el
    BIT 7 fuera 0. El bit 7 NO es el selector de puerto.
    Bien: (!joy_sel[0]) ? puerto1 : puerto2
    En el estandar MSX el registro 15 bit6 elige solo: 0 = puerto 1,
    1 = puerto 2. Es lo que hace el MSXimus (psg_reg15_port2 <= dout[6]),
    donde el raton funcionaba.
    Con el software pidiendo el puerto 2 (b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
    [top.v]
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2026-09-04 Trabajo de Albert: logo16k, banco del SCC y demo del frontend
    Cambios que estaban sin commitear en el arbol de trabajo, agrupados aparte
    para no mezclarlos con la extirpacion del BL616:
    - fpga/src/rom/make_logo16k.py + logo16k_preview.png
    - tools/scctest: scctest.asm y SCCTEST.COM actualizados, mas pgcmd/pgcmd4/
    pgrom/pgtest.asm y opcheck/BUG22_MG2_bladeba.md
    - tools/megaram_equiv: megaram_v16.v y megaram_v17.v
    - tools/frontend_demo/sample_sd: COVERS.PAK e INDEX.DAT
    - CLAUDE.md del proyecto
    .gitattributes: regla explicita para los binarios MSX (.COM/.SYS/.ROM/.DAT/
    .PAK/.bin/.fs). Con core.autocrlf=true git solo los respetaba por heuristica
    de contenido (NUL en los primeros 8 KB); uno qu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
    [megaram_v17.v]
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2026-09-19 Documentacion completa del proyecto y cierre de la v2.0
    El MSXnano se cierra en la v2.0: el chip esta al 89 % de CLS y clk_54m
    cierra por el margen del emplazador, no del diseno. Esta es la
    documentacion para quien lo use y para quien lo retome.
    docs/INDICE.md — indice general. Estado: v2.0, cerrado.
    docs/manual/ (10 capitulos, castellano): que es, instalacion (core, pack,
    RP2040, ESP-01S/ESP32-C6, cableado por pines), tarjeta SD y Nextor, menu
    de arranque, ROMs y mappers, teclado/raton/joystick, WiFi y File-Hunter,
    audio/video/turbo, carcasa, problemas frecuentes por sintoma.
    docs/tecnica/ (9 capitulos): arquitectura (relojes 108/30 y 108/20 +
    swallow, modulos de build.tcl, defines), p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
    [Upper_Left_esp32.stl, msxnano_case_bambulab.3mf, upper_left_sin_pantalla.stl]
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2026-09-29 v2.1: documentacion (arbol de cpu_din medido con 6 dados: 6/6 frente a 3/6; navegador ordenado) y el dado entregado 999917 en top.v
    - docs/tecnica/06: el mux por grupos, la tabla de 6 dados cadena/arbol (la v2.0 se
    reproduce exacta), ocupacion de la v2.1 y la de la v2.0 reconstruida; el repo
    reconstruye el bitstream (.bin identico, el .fs solo cambia en la fecha).
    - 08: entrada v2.1 (pendiente de validar en placa). 09: hecho tras el cierre y el
    arreglo del VDP (+47 CLS) como lo primero que reintentar con el arbol.
    - manual/04: orden, ocultos, 112 entradas y el '+'; Ajustes dice 2.1.
    [top.v]
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
